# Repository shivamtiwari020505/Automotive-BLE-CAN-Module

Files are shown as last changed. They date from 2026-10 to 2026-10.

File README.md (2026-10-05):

# Automotive BLE-CAN Module

A four-layer hardware design that connects a vehicle CAN bus to a Bluetooth Low Energy (BLE) interface. The module accepts a 9–36 V vehicle supply and has a separate input for a protected, externally charged 1-cell backup battery. During backup operation, the BLE section remains powered while CAN is unavailable.

This repository is a design snapshot for review and prototyping. It has not been fabricated or electrically tested, and the open items below must be resolved before a fabrication release.

## Design at a glance

| Item | Design |
| --- | --- |
| Vehicle input | 9–36 V |
| CAN interface | CAN FD controller and transceiver, connected to the MCU over SPI |
| Wireless interface | Bluetooth Low Energy, with a U.FL antenna connection |
| Backup input | Protected 1-cell Li-ion pack, charged externally |
| PCB | 49.5 × 56.9 mm, four layers, single-sided component assembly |
| Design tool | KiCad 10.0.6 or later |

## Open the project

1. Open [`hardware/BLE-CAN-module.kicad_pro`](hardware/BLE-CAN-module.kicad_pro) in KiCad 10.0.6 or later.
2. Keep the entire `hardware/` directory together. Its symbol tables, footprint tables, local libraries, and 3D models use project-relative paths.
3. For a quick review without KiCad, see the [schematic PDF](documentation/schematic/BLE-CAN-module-schematic.pdf), [PCB views](documentation/pcb/), and [architecture diagram](documentation/architecture/Architecture.svg).

## Repository layout

| Path | Contents |
| --- | --- |
| [`hardware/`](hardware/) | Editable KiCad schematic and PCB, project-local libraries and 3D models |
| [`hardware/Manufacturing_Output_Files/`](hardware/Manufacturing_Output_Files/) | Gerbers, drill files, placement data, BOM, and fabrication notes |
| [`documentation/architecture/`](documentation/architecture/) | System architecture and block diagram |
| [`documentation/schematic/`](documentation/schematic/) | Schematic PDF |
| [`documentation/pcb/`](documentation/pcb/) | PCB layer plot and 3D views |
| [`documentation/dfmea/`](documentation/dfmea/) | Risk register and review report |

## Design status

The project includes routed PCB files and a manufacturing output package, but these are review artifacts. The [architecture notes](documentation/architecture/ARCHITECTURE.md), [BOM notes](hardware/Manufacturing_Output_Files/BOM/BOM_NOTES.md), and [DFMEA report](documentation/dfmea/DFMEA_REPORT.md) record the remaining assumptions and validation work.

Before fabrication, the main open items are:

- Verify the CAN common-mode choke land pattern and terminal numbering.
- Select the CAN crystal and choose part numbers for the remaining BOM entries.
- Resolve the CAN controller's `nWKRQ` power-domain interface in hardware.
- Confirm the required conformal-coating process for the input-section clearances.

Electrical operation, vehicle transients, thermal behavior, RF performance, and EMC still require prototype testing. Do not treat the included manufacturing files as a production release.

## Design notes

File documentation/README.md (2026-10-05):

# Documentation

| Project file | Location | Contents |
| --- | --- | --- |
| Architecture description | `architecture/ARCHITECTURE.md` | System design and assumptions (Rev C) |
| Architecture diagram | `architecture/Architecture.png`, `.svg` | Power, CAN, and BLE block diagram |
| Schematic PDF | `schematic/BLE-CAN-module-schematic.pdf` | Five schematic sheets |
| PCB plots and 3D renders | `pcb/` | Board layer plots and 3D views |
| BOM | `../hardware/Manufacturing_Output_Files/BOM/BOM.csv` | 54 line items, cross-checked against the netlist |
| BOM notes | `../hardware/Manufacturing_Output_Files/BOM/BOM_NOTES.md` | Part qualification and open assumptions |
| DFMEA | `dfmea/DFMEA_REPORT.md`, `dfmea/DFMEA_REGISTER.csv` | 38-item module risk review (Rev 1.0) |
| Fabrication notes | `../hardware/Manufacturing_Output_Files/FAB_NOTES.md` | Stackup and assembly requirements |
| Manufacturing outputs | `../hardware/Manufacturing_Output_Files/` | Gerbers, drills, and placement data |

`datasheets/` holds the device datasheets used during design. `references/` holds
the TI reference material the design draws on — the LP-EM-CC2340R53 LaunchPad
schematic (RF matching values) and the TCAN4550 EVM (common-mode choke and bus
protection). Notes on the CC2340R5 library import are in
`../hardware/libraries/README.md`.

## Known gaps

These are design gaps, not documentation gaps — each is tracked in the DFMEA
register with a closure action.

- **Blocks fabrication:** L301's land pattern is unverified against the TDK
  ACT45B drawing (CAN-007); X301 has no manufacturer part number (MFG-001);
  eight further BOM line items have no MPN (MFG-002 / `../hardware/Manufacturing_Output_Files/BOM/BOM_NOTES.md` OA-3).
- **Blocks production schematic release:** the TCAN4550 nWKRQ power-domain
  conflict needs a hardware isolating buffer (CAN-001).
- **Blocks production build:** conformal coating must be contractually
  confirmed — the 9–36 V input spacing is only compliant under IPC-2221 row B4
  (PWR-005, `../hardware/Manufacturing_Output_Files/FAB_NOTES.md`).
- **Needs hardware before it can close:** all three oscillators run on assumed
  stray capacitance (CAN-002, RF-003, RF-004), and the RF match sits 6.3 mm from
  the ANT pin without re-tuning (RF-001).

36 of 38 DFMEA items are open. See `dfmea/DFMEA_REPORT.md` section 5 for the
twelve stated assumptions where a requirement, datasheet detail or layout rule
could not be closed.

## Tooling

The project is in **KiCad 10** file format (schematic `20260306`, PCB `20260206`)
and requires **KiCad 10.0.6 or later**. It will not open in KiCad 9 — KiCad file
formats are forward-compatible only.

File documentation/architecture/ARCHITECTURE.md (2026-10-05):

# Automotive BLE-CAN Module Architecture

**Revision C | 2026-09-30**

This document describes the current KiCad design in `hardware/BLE-CAN-module.kicad_sch`. It covers the vehicle input and battery backup power paths, CC2340R53 BLE controller, TCAN4550 CAN interface, and their external connections. It is a design description, not a vehicle-transient qualification report.

## System overview

The module accepts a nominal 9-36 V vehicle supply and a separately charged 1-cell Li-ion battery. The protected vehicle input is converted to `+6V5_CAN` for the CAN transceiver and regulated to `+3V3_VEH`. The battery branch produces a protected battery node and a low-quiescent-current 3.0 V rail.

U403/U404 (LM66100-Q1) implement the dual ideal-diode ORing topology of the LM66100-Q1 datasheet, section 9.2.1: each device's CE pin is cross-coupled to the opposite source (`U403 CE` = `+3V3_VEH`, `U404 CE` = `+3V0_BAT`), so the comparators select the higher rail with make-before-break behavior and block reverse current in both directions without any control logic. Because the vehicle rail is regulated to 3.3 V and the battery rail to 3.0 V, source priority is deterministic by construction: the vehicle path conducts whenever vehicle power is present, and the battery path takes over automatically when `+3V3_VEH` decays to about 80 mV below `+3V0_BAT`. The 0.3 V offset also avoids the datasheet-documented corner in which two equal input rails leave both ORing devices off. This is an analog priority scheme; there is deliberately no firmware in the changeover path.

The CC2340R53 runs the BLE application and communicates with the TCAN4550 over SPI. The CAN transceiver is powered from `+6V5_CAN` and uses `+3V3_SYS` for its digital I/O. Consequently, battery backup can keep the MCU domain alive while the vehicle-only CAN transceiver is unpowered; CAN communication is then unavailable.

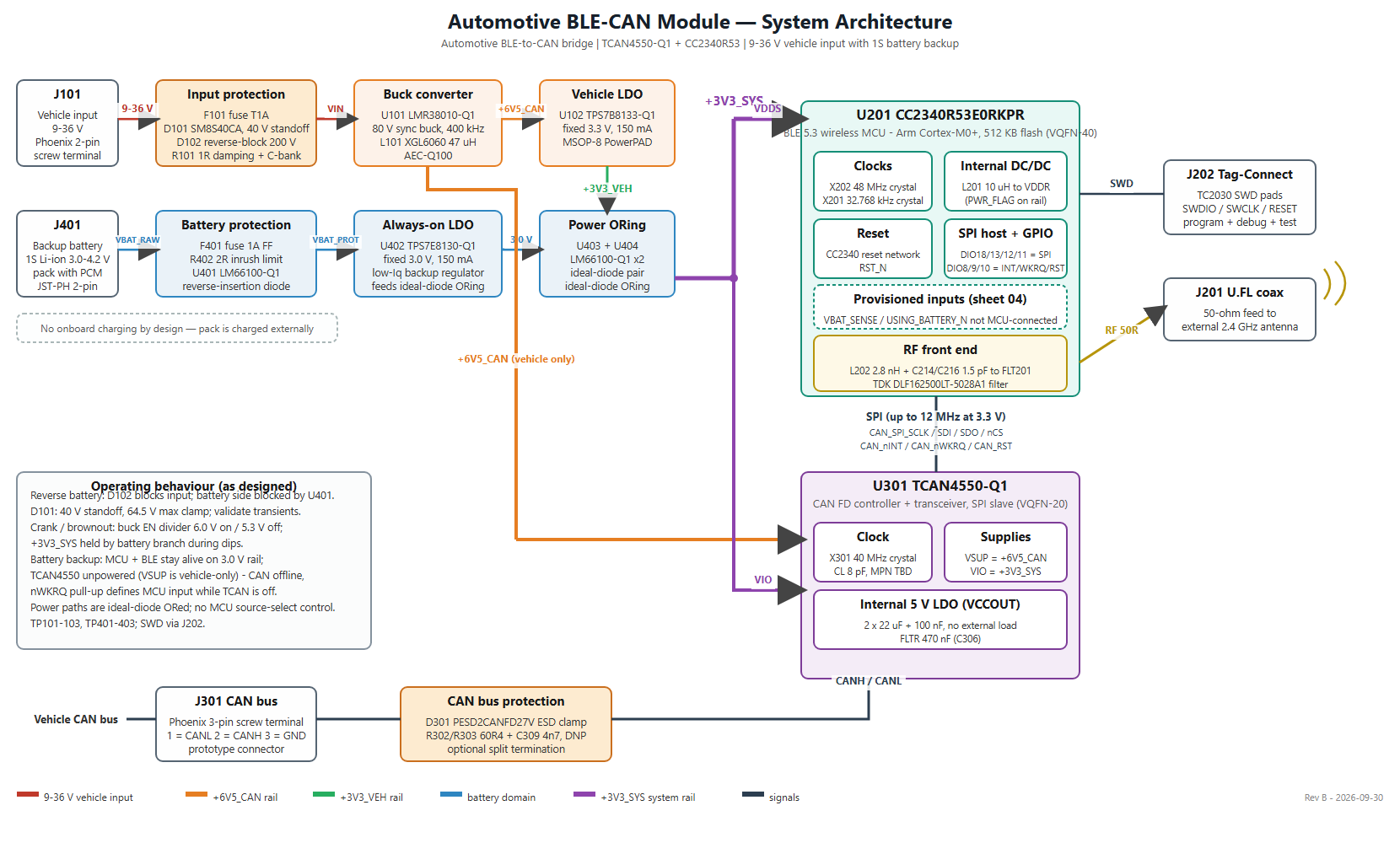
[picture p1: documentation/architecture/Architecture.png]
Automotive BLE-CAN module system architecture


## Power input and backup

### Vehicle input

J101 is the 2-pin 9-36 V input. F101 (T1A) and the input-protection network, including D101 (Vishay SM8S40CA TVS) and D102 (PNE20010ER-Q reverse-polarity protection), protect the downstream converter. R101 (1 ohm) and the input capacitor bank provide damping/filtering. U101 (LMR38010-Q1) with L101 (47 uH) generates `+6V5_CAN`; U102 (TPS7B8133-Q1) regulates that rail to `+3V3_VEH`. D101's 40 V rating is its reverse standoff voltage, not its clamp voltage; its specified maximum clamping voltage is 64.5 V at the rated pulse current. This alone does not establish compliance with a vehicle load-dump or other transient profile.

The 6.5 V intermediate rail is chosen against the TCAN4550 supply window: VSUP recommended operating range is 6-24 V with UVSUP thresholds of 5.5-5.9 V rising and 4.5-4.7 V falling, so 6.5 V provides headroom above UVSUP while minimizing dissipation in the transceiver's internal 5 V LDO and in U102.

### Battery backup

J401 accepts a protected 1-cell Li-ion pack (3.0-4.2 V); the pack is charged externally and no charger is present on this board. F401, R402, and U401 (LM66100-Q1) provide battery-branch protection; U401 uses the datasheet's always-on reverse-current-blocking configuration (CE tied to VOUT through R401), so the pack is isolated from any downstream fault that could otherwise back-drive it. U402 (TPS7E8130-Q1) produces `+3V0_BAT`. U403 and U404 combine `+3V0_BAT` and `+3V3_VEH` onto `+3V3_SYS` as described in the system overview.

`USING_BATTERY_N` and the `VBAT_SENSE` divider are present on the backup-power schematic but are not connected to CC2340 GPIO/ADC pins. They are provisioned, not MCU-readable in the current design. The CAN transceiver supply remains on the vehicle-derived `+6V5_CAN` rail.

## Vehicle transients, crank, and brownout

Behavior over the input range, using LMR38010-Q1 datasheet thresholds (EN rising 1.25 V typ / 1.4 V max; EN falling 1.10 V typ / 0.95 V min) and the R102/R103 divider (383 k / 100 k, ratio 4.83):

- **Normal operation, 9-36 V.** All rails regulated; buck output current is far below the 1 A rating (see power budget).
- **Jump start / 24 V system.** 36 V steady-state is within the converter's 80 V recommended operating range with large margin.
- **Load dump / transients.** D101 clamps at up to 64.5 V; the converter's 80 V operating / 85 V absolute-maximum input tolerates the clamped waveform. Formal ISO 16750-2 / ISO 7637-2 pulse testing has not been performed; see assumptions.
- **Crank.** The converter is enabled above approximately 6.0 V (worst-case 6.8 V) and remains enabled down to approximately 5.3 V typical. Below about 8 V input the buck is in dropout and `+6V5_CAN` follows the input minus the dropout voltage. CAN remains operational until VSUP crosses the TCAN4550 UVSUP falling threshold (4.5-4.7 V); the MCU's 3.3 V LDO stays in regulation essentially as long as the buck runs. Through a moderate crank dip (input ≥ ~6 V) the whole module therefore stays up.
- **Severe brownout (< ~5.3 V) or supply loss.** The buck disables via EN, the vehicle rails collapse, and U403/U404 switch `+3V3_SYS` to the battery rail with make-before-break continuity. The MCU domain (BLE) rides through; the CAN transceiver enters its protected/unpowered state and recovers automatically when VSUP rises back above UVSUP rising (5.5-5.9 V) - the TCAN4550 M_CAN core must then be reconfigured by firmware.
- **Reverse battery.** D102 blocks reverse current; D101 is bidirectional and clamps; F101 provides the series fault break.

## Power budget and thermal estimates

Estimated worst-case active budget (values from device datasheets; not yet validated on hardware):

| Rail | Loads | Estimated worst case |
| --- | --- | --- |
| `+6V5_CAN` | TCAN4550 VSUP (transceiver dominant, internal 5 V LDO, up to 70 mA VCCOUT budget), U102 input | ~90 mA |
| `+3V3_VEH` / `+3V3_SYS` | CC2340R53 (radio active, internal DC/DC), TCAN4550 VIO (≤3 mA with crystal), pull-ups | ~15-20 mA |
| Buck output total | | ~110 mA of 1 A rating |
| Input current at 9 V | ~0.72 W out, ~90 % PFM efficiency | ~90 mA |

Dissipation estimates at worst case, 85 °C ambient:

- **U301 TCAN4550**: dominant-state dissipation ≈ 0.45 W; at RθJA 35.2 °C/W (improved by the exposed-pad via array into the ground planes) junction rise ≈ 16 °C, Tj ≈ 101 °C against a 125 °C operating / 160 °C shutdown limit. This is the hottest device on the board.
- **U101 buck**: ~70 mW loss at full module load - negligible; DDA PowerPAD into the plane stack.
- **U102 LDO**: (6.5 V - 3.3 V) × 20 mA ≈ 64 mW - negligible.

No heatsinking or airflow is assumed; copper pours and the via arrays under U101/U102/U201/U301 are the only thermal paths.

## Standby (parked) current estimate

With the vehicle present, CAN in sleep, and BLE idle/advertising slowly, the estimated draw from the vehicle battery is on the order of **100-150 µA at 12 V**, dominated by:

- R102/R103 EN divider: 483 kΩ across the input ≈ 25 µA at 12 V (50 µA at 24 V) - the largest single fixed load; accepted to keep the enable threshold purely resistive.
- LMR38010-Q1 non-switching quiescent: 40 µA (PFM variant selected specifically for this figure).
- TCAN4550 sleep (VSUP tens of µA, VIO 9 µA) plus TPS7B81-Q1 (2.7 µA) and MCU standby (~1-2 µA).

On the battery branch, the continuous drain is the TPS7E81-Q1 quiescent (2.8 µA), the ideal-diode devices, and the 2 MΩ `VBAT_SENSE` divider (~2 µA) - roughly 6-8 µA before BLE activity, i.e. about 17 mAh/year from the divider alone. As a labeled example, a 500 mAh protected pack supporting an average 50 µA backup profile gives an order-of-magnitude runtime of ~10,000 h. These are datasheet-arithmetic estimates to be confirmed at bring-up.

## BLE controller

U201 is the TI CC2340R53E0RKPR, a 2.4 GHz Bluetooth LE MCU with 512 KB flash. X201 is a 32.768 kHz, 9 pF load crystal (Abracon ABS06-32.768KHZ-9-T). C212 and C213 are 15 pF C0G capacitors (Murata GRM1555C1H150JA01D). These are nominal values selected with approximately 1.5 pF of assumed parasitic capacitance; validate crystal load and startup margin on the assembled layout.

X202 is a 48 MHz, 7 pF load crystal (Abracon ABM11W-48.0000MHZ-7-D1X-T3). C210 and C211 are DNP; the MCU's configurable internal load-capacitance array is used, and its setting should be checked against the assembled board's parasitics. L201 is the MCU internal DC/DC inductor.

The RF network uses L202 (2.8 nH), C214/C216 (1.5 pF), and TDK DLF162500LT-5028A1 (FLT201), a 2.4 GHz band-pass filter. J201 is the U.FL antenna connection; use a 50 ohm feed and a suitable 2.4 GHz antenna. FLT201 is a filter, not a balun. The RF path is a 50 ohm microstrip on F.Cu referenced to the In1.Cu ground plane; the controlled-impedance requirement is stated in `hardware/Manufacturing_Output_Files/FAB_NOTES.md`.

J202 is the Tag-Connect TC2030 programming/debug footprint. The CC2340 SPI clock should be limited to the MCU-supported rate for the selected supply and operating conditions; at 3.3 V, use no more than 12 MHz and observe both devices' timing requirements.

## CAN interface

U301 is the TI TCAN4550-Q1 CAN FD controller/transceiver. It receives `+6V5_CAN` at VSUP, `+3V3_SYS` at VIO, and communicates with U201 over SPI. X301 is a 40 MHz crystal specified at 8 pF load capacitance; the schematic does not specify its manufacturer part number.

C305 and C310 are 22 uF VCCOUT capacitors; C307 is 100 nF. C306 is the 470 nF FLTR capacitor.

**Common-mode choke.** L301 (TDK ACT45B-101-2P-TL003, 100 µH, AEC-Q200) sits directly at the transceiver CANH/CANL pins, matching the choke position on TI's TCAN4550EVM and the datasheet section 11.1 guidance. The transceiver-side nets are `CAN_P`/`CAN_N`; the bus side of the choke - TVS, termination, and connector - is `CAN_BUS_P`/`CAN_BUS_N`. Both pairs use the `_P`/`_N` suffix convention so KiCad treats them as differential pairs. On the PCB the chain is placed inline in signal order — U301 → L301 → D301 → J301 — with the TVS adjacent to the connector per the datasheet layout guideline; J301 was shifted 0.7 mm toward the board edge to fit the choke without courtyard conflicts. The DNP split-termination cluster sits directly below the bus pair; its CANH tap uses a short B.Cu link (two vias) to cross the pair, which is acceptable for an unpopulated termination stub.

D301 (PESD2CANFD27V) protects the CAN bus. J301 is the 3-pin bus connector with the schematic pinout:

| J301 pin | Signal |
| --- | --- |
| 1 | CANL |
| 2 | CANH |
| 3 | GND |

R302 and R303 (60.4 ohm each) and C309 (4.7 nF) are DNP split-termination options. Populate termination only when the module is an end node and the network topology calls for it; do not populate it on an intermediate bus node.

## SPI, interrupt and reset wiring between CC2340R53 and TCAN4550

All seven control signals run directly between the two devices with no level
translation. The complete interface:

| Net | CC2340R53 (U201) | TCAN4550 (U301) | Bias | Purpose of the bias |
| --- | --- | --- | --- | --- |
| `CAN_SPI_SCLK` | pin 13, DIO18 | pin 4, SCLK | R308 100 k to GND | Defined level when the MCU tri-states in backup; matches SPI mode 0 idle |
| `CAN_SPI_SDI` | pin 7, DIO13 | pin 5, SDI | R309 100 k to GND | As above; TCAN input never floats |
| `CAN_SPI_SDO` | pin 6, DIO12 | pin 6, SDO | R310 100 k to GND | TCAN SDO is Hi-Z whenever nCS is high, so this defines the MCU input |
| `CAN_SPI_nCS` | pin 5, DIO11 | pin 7, nCS | R301 10 k to `+3V3_SYS` | Keeps the TCAN deselected while the MCU is in reset or tri-stated |
| `CAN_nINT` | pin 2, DIO8 | pin 8, nINT | R306 10 k to `+3V3_SYS` | Open-drain output; datasheet requires a 2–10 kΩ pull-up to VIO |
| `CAN_nWKRQ` | pin 3, DIO9 | pin 2, nWKRQ | R307 100 k to `+3V3_SYS` | See the voltage-domain note below — this one is **not** safe as drawn |
| `CAN_RST` | pin 4, DIO10 | pin 19, RST | R305 10 k to GND | RST is **active HIGH**; the pull-down keeps the device out of reset while the MCU is tri-stated |

### Voltage-domain assumptions

**No level shifting is required, and this is deliberate.** The TCAN4550 VIO pin
exists precisely so the SPI and GPIO block can be operated in the host's
I/O domain. Both sides of this interface sit on the same rail:

- CC2340R53 `VDDS` (pins 8, 17, 31, 38) → `+3V3_SYS`
- TCAN4550 `VIO` (pin 17) → `+3V3_SYS`

Because both devices track the same node, the logic thresholds move together and
there is no translation, no series resistor network and no added propagation
delay. SPI clock is limited to 12 MHz — the CC2340R53 constraint at 3.3 V, which
is below the TCAN4550's 18 MHz capability, so the MCU is the limiting device.

Two consequences follow from this choice, both tracked in the DFMEA:

1. **`nWKRQ` is the exception, and it is a real defect.** Before firmware writes
   register `0x0800` bit 19, nWKRQ drives from an internal **3.6 V** source — not
   from VIO. It is therefore the one pin in this interface that does *not*
   respect the shared domain. When the CAN device is powered while the MCU rail
   is low or absent, current can be injected into an MCU pin, and R307's 100 kΩ
   pull-up does not isolate a push-pull driver. Firmware configuration cannot
   protect the interval between power-up and that write. A buffer with a 5.5 V
   tolerant input and `Ioff` / partial-power-down protection is required — see
   **DFMEA CAN-001**, which blocks production schematic release.
2. **In battery backup, the shared rail sits at ~3.0 V**, below the TCAN4550's
   3.135 V recommended VIO minimum, though well above its 2.45–2.6 V UVIO
   threshold. The device does not fault; it simply operates outside its
   recommended window. This is accepted because CAN is defined as unavailable in
   backup and VSUP is absent anyway. The alternative — powering VIO from the
   vehicle rail only — was rejected because it would create a powered-MCU /
   unpowered-VIO partial-power-down condition on the SPI pins, which is the same
   mechanism as item 1. See **DFMEA CAN-006**.

The pull-down bias on SCLK/SDI/SDO is not decorative: backup mode is a state the
system enters by design, and without these resistors the TCAN4550 inputs would
float in a powered device.

## RF keepout, ground strategy and enclosure assumptions

**Keepout.** The RF chain runs as a straight line on F.Cu from the U201 ANT pad
through C214 / L202 / C216 and FLT201 to J201, with no vias and no layer changes.
In1.Cu beneath it is an uninterrupted ground plane — the microstrip reference is
continuous over the whole path. A local all-layer keepout is defined under the
U.FL body so no copper or via intrudes into the connector launch. Board-wide
ground stitching (505 vias) flanks the RF corner.

**Ground strategy.** In1.Cu is a solid, unbroken ground plane and is never used
for signal routing. B.Cu is a stitched ground pour. The RF section, the switching
regulator and the CAN section therefore share one reference with no split planes
and no moats — deliberately, since split-plane returns are a more common source
of trouble than they are a cure. U201's RFGND (pin 40) and exposed pad tie
straight into that plane through the device's via array.

**Enclosure assumptions** *(summary; no mechanical
design was undertaken)*:

- The antenna is **off-board**, on a U.FL pigtail. The board makes no assumption
  about antenna type or position beyond providing a 50 Ω port, so the enclosure
  can place it where the installation allows rather than the PCB dictating it.
- The enclosure is assumed **non-metallic in the vicinity of the antenna**, or
  the antenna is assumed to be mounted external to it. No detuning allowance has
  been made, and antenna performance is therefore outside what this board can
  guarantee (**DFMEA RF-005**).
- **Mounting and grounding:** four M2 holes (H1–H4) at the board corners have
  plated, ground-connected pads. If the enclosure is metallic and the standoffs
  are conductive, the board ground bonds to chassis at four points. That is the
  intended arrangement; if chassis bonding is *not* wanted, non-conductive
  standoffs must be specified.
- **Connectors** J101, J301 and J401 are all on board edges with horizontal entry,
  so a simple enclosure with edge cut-outs suffices. J201 (U.FL) is vertical and
  needs headroom for the mating pigtail.
- The board is assumed to be **conformally coated** (see assumptions section) —
  the enclosure is not relied upon for environmental sealing of the PCB.

## PCB stackup rationale

The board is a 1.58 mm 4-layer stackup: **F.Cu (signal) / In1.Cu (solid GND) / In2.Cu (power) / B.Cu (GND pour)**, with 0.11 mm 2116 prepreg between the outer layers and their adjacent planes.

- The thin prepreg to a continuous In1.Cu ground gives the 2.4 GHz microstrip a tight, unbroken reference and keeps the buck converter's hot-loop return inductance low.
- In2.Cu carries the `+3V3_SYS` and `+6V5_CAN` distribution planes, each sandwiched against ground.
- B.Cu is a stitched ground pour providing a low-impedance return and thermal spreading; dense via stitching ties all ground layers together, including arrays under the exposed pads of U101, U102, U201, and U301 and around the connectors and mounting holes.
- All components mount on the top side for single-pass assembly; three fiducials and six labeled test points support manufacturing and bring-up.

## Assumptions and trade-offs

1. **Input-section creepage/clearance - conformal coating assumed.** The 9-36 V input nets are routed at the project-default 0.2 mm clearance (minimum measured 0.20 mm). This assumes the assembled board receives a **permanent polymer conformal coating**, placing it under IPC-2221 Table 6-1 row **B4** (external conductors, coated, 31-50 V → 0.13 mm) rather than row B2 (uncoated → 0.6 mm). Coating is therefore a manufacturing requirement, not an option; it is called out in `hardware/Manufacturing_Output_Files/FAB_NOTES.md` together with the masking list. Where coating is masked - at J101 - the governing limit is the connector system's own rated insulation voltage at its 2.54 mm pitch, not the bare-board spacing table. *Trade-off:* tighter spacing kept the input section compact on a 49.5 × 56.9 mm board; the cost is a mandatory coating step and a repair/rework constraint. *Not closed:* spacing has not been assessed against the SM8S40CA's 64.5 V clamping voltage, only against the 36 V steady-state maximum.

2. **MCU part number.** An early project requirement named CC2340R40, which is not a valid part number. The design uses the **CC2340R5** family and selects **CC2340R53E0RKPR** (512 KB flash, QFN-40 RKP) as its orderable device. This selection does not imply automotive qualification.

3. **Automotive qualification is mixed.** All power-path and CAN ICs are AEC-Q100/Q101 qualified (-Q1 variants). The BLE MCU, CC2340R53E0RKPR, is **not AEC-Q100 qualified**; no automotive-qualified CC2340 orderable exists in this design's library. The module is therefore assumed to be a **cabin-mounted, non-safety telematics device** with an operating ambient bounded by the MCU's commercial rating rather than by the Q1 parts around it. Several electromechanical parts are likewise prototype/bench grade and would change for a production automotive build: the Phoenix MPT terminal blocks (J101, J301) and JST-PH battery connector (J401) have no vibration or sealing rating and would move to a sealed automotive connector system; C101 (Panasonic FK, 105 °C / 2000 h electrolytic) is a wear-out item on the always-on input and would move to an automotive-grade hybrid-polymer or ceramic-only bank; the AEC-Q200 status of the selected Abracon crystal orderables must be verified or Q200 equivalents substituted.

4. **TCAN4550 VIO below recommended minimum in battery backup.** In backup, `+3V3_SYS` equals the 3.0 V battery rail, below the TCAN4550 VIO recommended minimum of 3.135 V but well above the UVIO thresholds (2.45-2.6 V rising), so the device does not fault - it is simply outside recommended operating conditions on a powered pin. This is accepted because CAN is defined as unavailable in backup mode and VSUP is absent anyway. The alternative - powering VIO from the vehicle rail only - was rejected because it would create a powered-MCU/unpowered-VIO partial-power-down condition on the SPI pins (compare DFMEA item CAN-001).

5. **CAN choke land pattern.** L301 is placed and routed on the PCB (DRC and schematic parity clean). Its footprint is a generic 4532 common-mode-choke land pattern; verify it against the TDK ACT45B manufacturer drawing, including terminal numbering, before fabrication release.

## Test and design notes

Power test points are TP101 (`+6V5_CAN`), TP102 (`+3V3_VEH`), TP103 (GND), TP401 (`VBAT_PROTECTED`), TP402 (`+3V3_SYS`), and TP403 (GND). No TP404 or TP405 is present in the current schematic. J202 provides programming/debug access.

The SM8S40CA's 40 V standoff rating is below the maximum 36 V nominal input range only with limited margin for tolerance and transient behavior. Confirm the selected protection scheme against the intended vehicle electrical/transient requirements, connector polarity, fuse coordination, and downstream absolute-maximum ratings before production use. Component ratings in this document do not constitute automotive qualification.

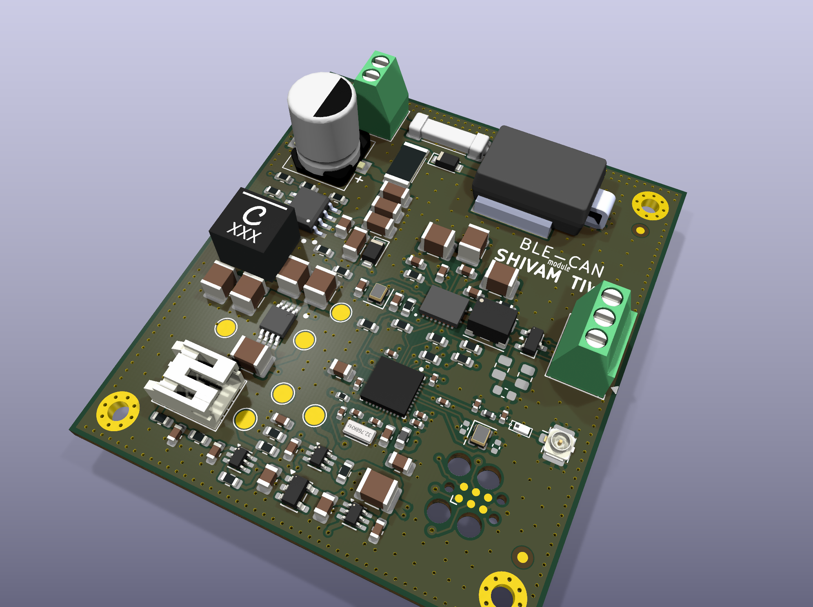
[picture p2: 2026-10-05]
documentation/pcb/pcb-3d-isometric.png

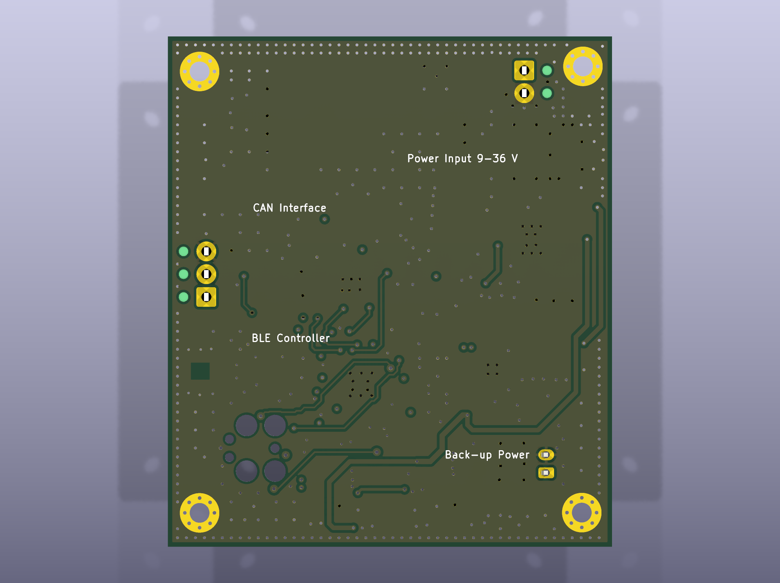
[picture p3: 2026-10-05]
documentation/pcb/pcb-3d-bottom.png

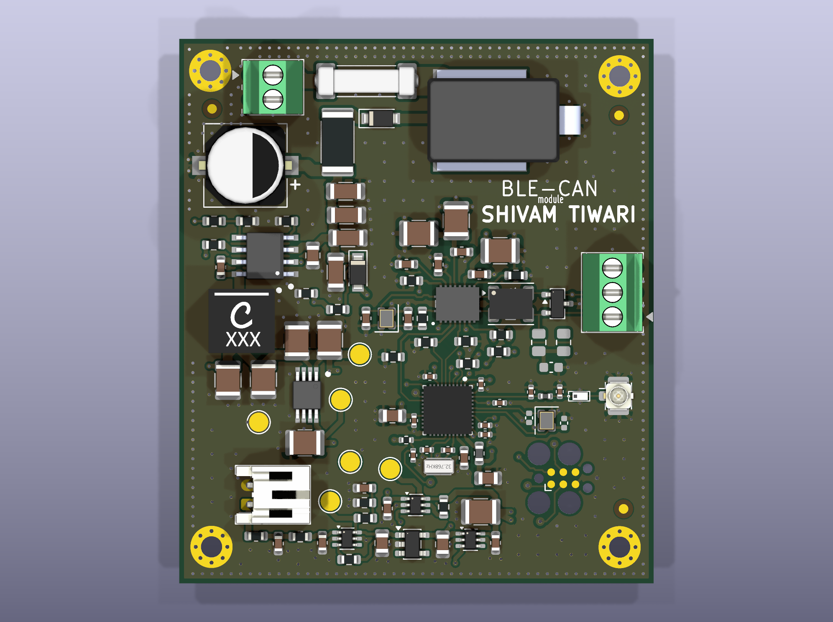
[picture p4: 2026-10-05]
documentation/pcb/pcb-3d-top.png

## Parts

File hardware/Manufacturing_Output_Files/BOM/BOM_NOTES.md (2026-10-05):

# Bill of Materials — Notes, Qualification Status and Unresolved Assumptions

**Project:** Automotive BLE-CAN Module
**Designer:** Shivam Tiwari
**Design period:** 2026-09-24 to 2026-09-30 | Rev A
**Source of truth:** `hardware/BLE-CAN-module.kicad_sch` (KiCad 10.0.6)
**Machine-readable BOM:** `BOM.csv` in this folder

This document carries the qualification notes, alternatives rationale and open
assumptions for this project. `BOM.csv` holds the same information
per line item; this file groups it so it can be reviewed as a whole.

## 1. Summary

| Metric | Count |
| --- | --- |
| BOM line items | 54 |
| Distinct components on the board | 96 |
| Fitted components | 91 |
| DNP components | 5 (C210, C211, C309, R302, R303) |
| Line items with a committed MPN | 46 of 54 |
| **Line items with NO manufacturer part selected** | **8** |
| Footprint-only items (no part fitted) | 14 |

`BOM.csv` has been cross-checked programmatically against the KiCad netlist
export: all 96 board references are covered exactly once, every `Qty` matches its
reference list, and the DNP set agrees with the schematic.

Footprint-only items, correctly excluded from the BOM but present on the board:
H1–H4 (M2 mounting holes, grounded), FM1–FM3 (fiducials), J202 (Tag-Connect
TC2030 programming footprint — no connector is fitted, the probe is a tool), and
TP101/102/103/401/402/403 (test pads).

## 2. Automotive qualification status

The power path and CAN devices are automotive-qualified. The wireless subsystem
and all electromechanical parts are not. This is a deliberate, documented
trade-off — see `documentation/architecture/ARCHITECTURE.md`, assumptions
section 2.

### Qualified

| Class | Parts | Standard |
| --- | --- | --- |
| Power / interface ICs | LMR38010-Q1, TPS7B81-Q1, TPS7E81-Q1, LM66100-Q1 (×3), TCAN4550-Q1 | AEC-Q100 Grade 1 |
| Discretes | SM8S40CA, PNE20010ER-Q, PMEG10010ELR-Q, PESD2CANFD27V | AEC-Q101 |
| Passives | TDK CGA series MLCC (all), Vishay CRCW-e3 resistors (all), Coilcraft XGL6060, Vishay MFU fuse | AEC-Q200 |

### Not qualified, or unverified

| Part | Status | Consequence and intent |
| --- | --- | --- |
| **CC2340R53E0RKPR** (U201) | **Not AEC-Q100** | No automotive-qualified CC2340 orderable exists. This part, not the Q1 devices around it, bounds the module's environmental rating. Assumed cabin-mount, non-safety telematics use. |
| **C101** Panasonic EEEFK2A220P | **AEC-Q200 claim unverified** | The schematic note claims AEC-Q200; this was not confirmed against the Panasonic datasheet. Regardless of qualification, FK is a 105 °C / 2000 h series — roughly one year of continuous operation at high ambient on an always-on rail. This is the board's dominant wear-out item. |
| **F101** Schurter UMT 250 | Not AEC-Q200 | Industrial fuse. Needs an automotive-qualified equivalent or a documented procurement agreement. |
| **C212, C213** Murata GRM | Not automotive (GRM is the commercial series) | Direct automotive equivalent exists: **GCM1555C1H150JA16**. Recommended swap for production — same size, same value. |
| **X201, X202** Abracon | Commercial, +85 °C max | Rated below the +125 °C of the surrounding automotive ICs. Automotive equivalents identified in `BOM.csv`. |
| **FLT201** TDK DLF162500LT | Commercial | No automotive grade identified for this filter. |
| **J101, J301** Phoenix MPT | Not automotive | Industrial screw terminals — no vibration, sealing or keying rating. Bench/prototype connectors. |
| **J401** JST PH | Not automotive | No locking retention for vibration. |
| **J201** Hirose U.FL | Commercial | ~30 mating cycles, no vibration lock. Acceptable for an internal pigtail, not a serviceable interface. |
| **L301** TDK ACT45B | AEC-Q200 believed, **unverified** | See open item OA-2 below. |

## 3. Unresolved assumptions — ranked

These are the honest gaps. None are hidden in the CSV; each appears against its
line item as well.

**OA-1 — X301 (40 MHz CAN crystal) has no manufacturer part selected.**
The single most significant BOM gap. Frequency tolerance directly drives CAN FD
bit timing, and the crystal's motional parameters determine the final C303/C304
and R311 values. This blocks closure of DFMEA item CAN-002. Candidate parts are
listed in `BOM.csv`; none has been committed.

**OA-2 — L301 footprint is a generic land pattern, not the manufacturer's.**
The choke is assigned `L_CommonModeChoke_Coilank_ACM4532`, a generic 4.5 × 3.2 mm
pattern, while the specified part is a TDK ACT45B. Both the pad geometry **and
the terminal numbering** must be checked against the TDK drawing before
fabrication. The schematic symbol variant (`_1423`) was chosen so windings pair
1–4 and 2–3 to match the assigned footprint; if the ACT45B numbers its windings
differently, the symbol variant must be swapped. This is recorded in the
component's `Purpose` field in the schematic.

**OA-3 — Eight line items have no manufacturer part number.**
All are in the MCU/RF section: L201, L202, C201–C204/C206/C207/C215, C205/C208,
C209, C214/C216, R201, plus X301 (OA-1) and the J201 MPN field. Two matter
electrically rather than commercially:
- **L202 (2.8 nH)** and **C214/C216 (1.5 pF)** are RF matching components. The
  values come from TI's LP-EM-CC2340R53 reference design, but a general-purpose
  part will degrade the match — high-Q RF-grade parts with tight tolerance are
  required.
- **L201 (10 µH)** feeds the CC2340R5 internal DC/DC and must meet TI's
  saturation-current and DCR requirement.

**OA-4 — The RF matching network has not been re-tuned for this board.**
L202/C214/C216 are the TI reference values, but on the LaunchPad those parts sit
immediately at the ANT pin. Here the first matching element is **6.3 mm** from
the pin — about 33° of electrical length at 2.44 GHz — and the network feeds a
TDK low-pass filter into a U.FL connector rather than the reference's tuning pi.
The values are a starting point, not a verified match. VNA verification on an
assembled board is required.

**OA-5 — MLCC derating is assumed from datasheet curves, not measured.**
Several capacitances have datasheet minimums that must survive DC bias,
temperature and aging: TCAN4550 VCCOUT (≥10 µF effective at 5 V, from
C305 + C310 = 44 µF nominal), FLTR (≥300 nF from 470 nF nominal), U402 output
(≥2.2 µF), and the buck output bank (≥20 µF effective at 6.49 V). All are
believed to have margin; none has been bench-verified.

**OA-6 — Crystal load capacitors are provisional.**
C212/C213 (15 pF) assume ~1.5 pF board stray for CL = 9 pF. C303/C304 (10 pF)
assume ~3 pF stray for CL = 8 pF. C210/C211 are DNP because the CC2340R5 internal
cap array is used — but the X48P/X48N traces are long and asymmetric (11.1 mm vs
7.6 mm), so the added stray may prevent the array reaching the 7 pF CL. R311 is
0 Ω for first assembly only. All of these are set on the prototype, per TI SLLA549.

**OA-7 — CAN bus termination topology is an assumption.**
R302/R303/C309 are DNP because the module is assumed to be a **stub node**. If it
is deployed as a bus end node, all three must be fitted together (120.8 Ω). No
network topology requirement was supplied.

**OA-8 — Transient protection is not validated against a pulse standard.**
D101's 40 V standoff leaves limited margin over the 36 V maximum input, and its
64.5 V clamp is within the LMR38010-Q1's 80 V operating / 85 V absolute-maximum
rating. No ISO 7637-2 or ISO 16750-2 pulse testing has been performed, and the
fuse/TVS energy coordination study has not been done.

**OA-9 — VBAT_SENSE is provisioned but not connected.**
R403/R404/C404 form a working divider, but `VBAT_SENSE` and `USING_BATTERY_N`
terminate at unconnected labels — no CC2340 ADC or GPIO is attached, despite 16
free pins. Firmware cannot read battery voltage or determine the active source.

**OA-10 — D102 ratings taken from the schematic note, not the datasheet.**
PNE20010ER-Q is recorded as 200 V / 1 A from the schematic's own annotation.
IF(AV) and the forward drop at the ~90 mA operating current were not
independently confirmed.

## 4. Deliberate design choices visible in the BOM

Worth reading as intent rather than as gaps:

- **U101 is the PFM, spread-spectrum variant** (`LMR38010SQ…`, not `…FSQ…`).
  Chosen for 40 µA non-switching quiescent current — the parked-current budget —
  and for conducted/radiated EMI. The FPWM variant would have been the wrong call.
- **U402 is 3.0 V, not 3.3 V.** The 0.3 V offset below `+3V3_VEH` is what gives
  the LM66100 ORing pair a decisive priority margin and avoids the datasheet's
  documented equal-rails lockout, where both devices switch off.
- **U102 is fed from +6V5_CAN, not VIN.** Dissipation drops to ~64 mW at the
  design load instead of ~0.65 W from a 36 V rail.
- **D101 is bidirectional (CA).** Reverse battery is blocked by the D102 series
  diode rather than clamped, so the fuse does not open on a reverse connection.
- **D301 is 27 V standoff.** Chosen so a CANH/CANL short to a 24 V vehicle rail
  does not put the clamp into conduction.
- **R102/R103 set turn-on near 6.0 V**, below the 9 V specification minimum, to
  ride through crank. The cost is ~25 µA continuous — the largest single fixed
  standby load on the vehicle battery.

## 5. Before fabrication release

1. Select X301 and close OA-1.
2. Verify the L301 land pattern and terminal numbering (OA-2).
3. Assign the eight missing MPNs, with RF-grade parts for L202/C214/C216 (OA-3).
4. Swap C212/C213 to the GCM automotive equivalent.
5. Decide the C101 endurance question — either confirm its qualification and
   accept the 2000 h rating, or move to an automotive hybrid-polymer part.
6. Confirm conformal coating is contracted — the input-section spacing depends
   on it (see `hardware/Manufacturing_Output_Files/FAB_NOTES.md`).

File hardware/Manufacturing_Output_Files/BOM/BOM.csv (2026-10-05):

Item | Qty | References | Description | Value / Key Ratings | MPN | Manufacturer | Package / Footprint | Automotive Qualification | Key Alternatives | Notes and Unresolved Assumptions | Fitted
1 | 1 | C101 | Aluminium electrolytic input bulk | 22 uF +/-20% / 100 V / 105 degC / 2000 h endurance | EEEFK2A220P | Panasonic | SMD can 8 x 10.2 mm (FK case F) | UNVERIFIED - schematic note claims AEC-Q200; not confirmed against Panasonic datasheet | Nichicon UCD2A220MCL1GS; Wurth 865060645004 (both need land-pattern check) | Only wet electrolytic on the board and the dominant wear-out item on an always-on rail. 2000 h at 105 degC is roughly 1 year continuous at high ambient. Damping partner to R101; do not delete without re-checking input-filter damping. | Yes
2 | 4 | C102-C105 | Input ceramic bank X7R | 4.7 uF / 100 V / X7R / 1206 | CGA5L1X7R2A475K160AC | TDK | C_1206_3216Metric | AEC-Q200 (TDK CGA automotive series) | Murata GCM31CR72A475KE02; Kemet C1206C475K1RACAUTO | Bank must retain >=4.7 uF effective after DC bias, temperature and aging. Not measured - derating assumed, not verified. | Yes
3 | 1 | C106 | VIN high-frequency bypass | 100 nF / 100 V / X7R / 0805 | CGA4J2X7R2A104K125AA | TDK | C_0805_2012Metric | AEC-Q200 (TDK CGA) | Murata GCM21BR72A104KA37 | Placed directly across U101 VIN/GND for the smallest hot loop. | Yes
4 | 6 | C107,C302,C307,C308,C404,C408 | General decoupling / filter | 100 nF / 50 V / X7R / 0603 | CGA3E2X7R1H104K080AA | TDK | C_0603_1608Metric | AEC-Q200 (TDK CGA) | Murata GCM188R71H104KA57 | Roles: U101 bootstrap (C107), TCAN4550 VSUP/VIO/VCCOUT bypass (C302/C308/C307), VBAT_SENSE filter (C404), +3V3_SYS bypass (C408). | Yes
5 | 9 | C108-C112,C301,C305,C310,C407 | Bulk ceramic X7R | 22 uF / 25 V / X7R / 1210 | CGA6P3X7R1E226M250AB | TDK | C_1210_3225Metric | AEC-Q200 (TDK CGA) | Murata GCM32ER71E226KE15 | C305+C310 must retain >=10 uF effective at 5 V (TCAN4550 VCCOUT minimum). Buck output bank should hold >=20 uF effective at 6.49 V. Derating assumed from datasheet curves - not bench-verified. | Yes
6 | 1 | D101 | Bidirectional transient suppressor | 40 V standoff, 64.5 V max clamp at 102 A (10/1000 us), 8000 W peak | SM8S40CAHM3_A/I | Vishay | DO-218AC (BLE_CAN:Vishay_DO-218AC_SM8S) | AEC-Q101 | Littelfuse SM8S40CA; Bourns SM8S40CA (same DO-218AC outline) | Bidirectional chosen so reverse battery is blocked by D102 rather than clamped. 40 V standoff leaves limited margin over the 36 V maximum input. NOT validated against an ISO 7637-2 / ISO 16750-2 pulse set. | Yes
7 | 1 | D102 | Series reverse-battery blocking rectifier | 200 V / 1 A (per schematic note - confirm IF(AV) and VF at 90 mA) | PNE20010ER-QX | Nexperia | SOD-123W (Diode_SMD:Nexperia_CFP3_SOD-123W) | AEC-Q101 (Nexperia -Q suffix) | Nexperia PMEG6010CEH; ST STPS1L60A (footprint differs) | Series diode costs ~0.5-0.7 V forward drop. A reverse-blocking P-FET would be more efficient but was not used. Exact VF at load not verified. | Yes
8 | 1 | D103 | Output-to-input discharge Schottky | 100 V / 1 A Schottky | PMEG10010ELR-QX | Nexperia | SOD-123W (Diode_SMD:Nexperia_CFP3_SOD-123W) | AEC-Q101 (Nexperia -Q suffix) | Nexperia PMEG10020ELR-Q | Protects the buck when VIN falls below the stored output voltage. Not a battery power path. | Yes
9 | 1 | F101 | Vehicle input fuse | T1A / 125 VDC slow-blow | 3403.0166.24 | SCHURTER | UMT 250 SMD (Fuse:Fuse_Schurter_UMT250) | NOT AEC-Q200 - industrial part; automotive qualification/procurement agreement required | Littelfuse 0453001.MR (AEC-Q200); Bel Fuse 0ZCJ series | Must coordinate with the harness fuse and the TVS clamp energy. Coordination study not performed. | Yes
10 | 1 | J101 | Vehicle power input connector | 6 A / 160 V, 2.54 mm pitch screw terminal | 1725656 | Phoenix Contact | TerminalBlock_Phoenix_MPT-0.5-2-2.54_1x02_P2.54mm_Horizontal | NOT automotive - industrial terminal block, no vibration or sealing rating | TE AMPSEAL 16 series; Molex MX150 (sealed automotive) | Pin 1 = vehicle positive, pin 2 = vehicle return. Prototype/bench connector; production build requires a sealed, keyed, vibration-rated connector. This connector carries the full 9-36 V input: its 0.34 mm pad-to-pad copper gap is fixed by the 2.54 mm pitch, and the surrounding pour clearance is 0.30 mm - both rely on the mandatory conformal coating (IPC-2221 row B4). See hardware/Manufacturing_Output_Files/FAB_NOTES.md. | Yes
11 | 1 | L101 | Buck power inductor | 47 uH / 107 mOhm max DCR / shielded composite | XGL6060-473MEC | Coilcraft | Coilcraft XGL6060 6.0 x 6.0 mm | AEC-Q200 | Wurth 74439346470; Bourns SRP6060A-470M | Marked short-lead side oriented to the SW node to keep the switching field away from the RF section. | Yes
12 | 1 | L201 | MCU DC/DC inductor | 10 uH / 0603 | NOT SELECTED | - | Inductor_SMD:L_0603_1608Metric | Not selected | TI recommends a specific L for the CC2340 internal DC/DC - see device datasheet | UNRESOLVED: no MPN assigned. Must select a part meeting TI's saturation-current and DCR requirement for the CC2340R5 internal DC/DC before release. | Yes
13 | 1 | L202 | RF matching inductor | 2.8 nH / 0402 / high-Q RF | NOT SELECTED | - | Inductor_SMD:L_0402_1005Metric | Not selected | Murata LQW15A series; Coilcraft 0402HP | UNRESOLVED: no MPN. Value copied from the TI LP-EM-CC2340R53 reference. Requires a high-Q RF inductor with tight tolerance; a general-purpose part will degrade the match. | Yes
14 | 1 | L301 | CAN common-mode choke | 100 uH common-mode / CAN and CAN FD rated | ACT45B-101-2P-TL003 | TDK | 4.5 x 3.2 mm (Inductor_SMD:L_CommonModeChoke_Coilank_ACM4532) | AEC-Q200 - VERIFY against TDK datasheet | Murata DLW43SH101XK2; Wurth 744232101 | Part taken from the TI TCAN4550EVM choke pad. FOOTPRINT IS A GENERIC ACM4532 LAND PATTERN - verify pad geometry AND terminal numbering against the TDK ACT45B drawing before fabrication; if ACT45B numbers its windings differently, swap the schematic symbol variant. | Yes
15 | 1 | R101 | Input damping / inrush resistor | 1 Ohm / 5% / 1 W / pulse-proof | CRCW25121R00JNEGIF | Vishay | R_2512_6332Metric | AEC-Q200 (Vishay CRCW-e3) | Vishay CRCW2512 standard; Bourns CRM2512 | Damps the input LC with C101 and limits hot-plug inrush. Approx 5 mW dissipation at nominal load - heavily de-rated for surge energy. | Yes
16 | 1 | R102 | Buck EN divider upper | 383 k / 1% / 0603 | CRCW0603383KFKEA | Vishay | R_0603_1608Metric | AEC-Q200 (Vishay CRCW-e3) | Panasonic ERJ series (AEC-Q200) | With R103 sets buck turn-on near 6.0 V and turn-off near 5.3 V, giving crank ride-through below the 9 V spec. Draws ~25 uA continuously from the vehicle battery - the largest fixed standby load. | Yes
17 | 3 | R103,R107,R405 | Pull-up / divider | 100 k / 1% / 0603 | CRCW0603100KFKEA | Vishay | R_0603_1608Metric | AEC-Q200 (Vishay CRCW-e3) | Panasonic ERJ series (AEC-Q200) | R103 buck EN divider lower; R107 PGOOD pull-up to +3V3_VEH; R405 USING_BATTERY_N pull-up to +3V3_SYS. | Yes
18 | 1 | R104 | Switching frequency set | 64.9 k / 1% / 0603 | CRCW060364K9FKEA | Vishay | R_0603_1608Metric | AEC-Q200 (Vishay CRCW-e3) | Panasonic ERJ series (AEC-Q200) | Sets nominal 400 kHz - the value used in the LMR38010-Q1 datasheet characterisation. | Yes
19 | 1 | R105 | Buck feedback upper | 54.9 k / 1% / 0603 | CRCW060354K9FKEA | Vishay | R_0603_1608Metric | AEC-Q200 (Vishay CRCW-e3) | Panasonic ERJ series (AEC-Q200) | 1 V x (1 + 54.9k/10k) = 6.490 V. Within TI's preferred 10k-100k divider range. | Yes
20 | 1 | R106 | Buck feedback lower | 10.0 k / 1% / 0603 | CRCW060310K0FKEA | Vishay | R_0603_1608Metric | AEC-Q200 (Vishay CRCW-e3) | Panasonic ERJ series (AEC-Q200) | 100 uA nominal divider current; routed as a quiet Kelvin connection to the analogue ground. | Yes
21 | 1 | U101 | Synchronous buck regulator | 4.2-80 V in, 6.49 V out, 1 A, PFM, spread spectrum, 40 uA Iq | LMR38010SQDDARQ1 | Texas Instruments | HSOIC-8 PowerPAD DDA (BLE_CAN:TI_DDA0008B_PowerPAD) | AEC-Q100 Grade 1 (-40 to +125 degC) | LMR38020SQDDARQ1 (2 A, same DDA package); LMR38010FSQDDARQ1 (FPWM variant - higher standby current) | PFM + spread-spectrum variant deliberately chosen: 40 uA non-switching Iq for parked current, spread spectrum for conducted/radiated EMI. Absolute max VIN 85 V covers the 64.5 V TVS clamp. | Yes
22 | 1 | U102 | Vehicle 3.3 V LDO | 3-40 V in, 3.3 V fixed, 150 mA, 2.7 uA Iq | TPS7B8133QDGNRQ1 | Texas Instruments | HVSSOP-8 PowerPAD DGN (BLE_CAN:TI_DGN0008G_PowerPAD) | AEC-Q100 Grade 1 | TPS7B6933QDBVRQ1 (SOT-23-5 - different footprint) | Fed from +6V5_CAN rather than VIN, cutting dissipation to ~64 mW at the ~20 mA design load. | Yes
23 | 1 | U201 | BLE 5.x wireless MCU | 512 KB flash, 2.4 GHz, 1.71-3.8 V, internal DC/DC | CC2340R53E0RKPR | Texas Instruments | QFN-40 RKP 5 x 5 mm (BLE_CAN:RKP0040B-MFG) | NOT AEC-Q100 - no automotive-qualified CC2340 orderable exists | CC2340R52E0RKPR (256 KB, same RKP package and pinout) | MCU SELECTION: CC2340R53E0RKPR (512 KB flash) is the project-selected orderable device in the CC2340R5 family. It is not AEC-Q100 qualified. Assumed cabin-mount, non-safety telematics use - see ARCHITECTURE.md assumptions. | Yes
24 | 7 | C201-C204,C206,C207,C215 | MCU decoupling | 100 nF / 0402 (voltage rating not specified) | NOT SELECTED | - | C_0402_1005Metric | Not selected | TDK CGA2B3X7R1H104K050BB (AEC-Q200) or Murata GCM155R71H104KE02 | UNRESOLVED: no MPN or voltage rating assigned. Specify >=16 V X7R AEC-Q200 parts before release. | Yes
25 | 2 | C205,C208 | MCU bulk decoupling | 10 uF / 0805 (voltage rating not specified) | NOT SELECTED | - | C_0805_2012Metric | Not selected | TDK CGA4J1X7R1C106K125AC (AEC-Q200) | UNRESOLVED: no MPN or voltage rating. C208 is the VDDR reservoir - TI specifies a minimum effective capacitance; confirm after derating. | Yes
26 | 1 | C209 | VDDD decoupling | 1 uF / 10 V / 0603 | NOT SELECTED | - | C_0603_1608Metric | Not selected | TDK CGA3E1X7R1A105K080AC (AEC-Q200) | UNRESOLVED: no MPN. Value per TI SWRA834A section 9.1. | Yes
27 | 2 | C210,C211 | HFXT load capacitor provision | DNP / 0402 | NOT FITTED | - | C_0402_1005Metric | n/a | - | Deliberately unfitted: the CC2340R5 internal load-capacitance array is used instead. Fit only if the internal array cannot reach the crystal's 7 pF CL on the assembled board. | No (DNP)
28 | 2 | C212,C213 | LSE crystal load capacitors | 15 pF / 50 V / C0G / 0402 | GRM1555C1H150JA01D | Murata | C_0402_1005Metric | NOT automotive - GRM is Murata's commercial series | Murata GCM1555C1H150JA16 (AEC-Q200, same size) - RECOMMENDED for production | Values assume ~1.5 pF board stray to hit CL = 9 pF. Stray not measured. Swap to the GCM automotive equivalent for production. | Yes
29 | 2 | C214,C216 | RF matching capacitors | 1.5 pF / 0402 / C0G RF | NOT SELECTED | - | C_0402_1005Metric | Not selected | Murata GJM1555C1H1R5BB01 (RF-grade C0G) | UNRESOLVED: no MPN. Values copied from the TI LP-EM-CC2340R53 reference. Tight-tolerance RF C0G parts required; the match has NOT been re-tuned for this board's U.FL + LPF combination. | Yes
30 | 1 | FLT201 | 2.4 GHz low-pass filter | 2400-2500 MHz LPF | DLF162500LT-5028A1 | TDK | 0603 (RF_BLE_PCBFootprints:DLF162500LT-5028A1) | Commercial - no automotive grade identified | Johanson 2450FM07A0029; Murata LFL21868MSA1A167 | This is a LOW-PASS filter (TDK title: 'Multilayer Low Pass Filter'), used for harmonic suppression - it is not a balun and not a band-pass filter. | Yes
31 | 1 | J201 | RF coaxial connector | 50 Ohm, DC-6 GHz, ~30 mating cycles | U.FL-R-SMT-1(10) | Hirose | Connector_Coaxial:U.FL_Hirose_U.FL-R-SMT-1_Vertical | Commercial | Amphenol A-1JB; I-PEX MHF I (20279-001E-01) | UNRESOLVED: no MPN field populated in the schematic. U.FL has no vibration lock and limited mating cycles - acceptable for an internal pigtail, not for a serviceable interface. Antenna itself is out of scope. | Yes
32 | 1 | X201 | LSE crystal | 32.768 kHz, CL 9 pF, ESR <=90 kOhm, -40 to +85 degC | ABS06-32.768KHZ-9-T | Abracon | Crystal_SMD_2012-2Pin_2.0x1.2mm | Commercial - verify; automotive variant needed for production | Epson FC-135 automotive; Abracon ABS07AIG series (confirm AEC-Q200 status and CL) | Rated to +85 degC only, below the +125 degC of the automotive ICs around it. Load capacitance and startup margin not measured on an assembled board. | Yes
33 | 1 | X202 | HFXT crystal | 48 MHz, CL 7 pF, 4-pad | ABM11W-48.0000MHZ-7-D1X-T3 | Abracon | Crystal_SMD_2016-4Pin_2.0x1.6mm | Commercial - verify; automotive variant needed for production | NDK NX2016SA 48 MHz; Epson TSX-3225 48 MHz (AEC-Q200 variants available) | Relies on the MCU internal cap array (C210/C211 DNP). PCB traces are long and asymmetric (X48P 11.1 mm vs X48N 7.6 mm) - added stray may prevent the array reaching CL = 7 pF. Must be verified on hardware. | Yes
34 | 1 | R201 | MCU reset pull-up | 100 k / 0402 | NOT SELECTED | - | R_0402_1005Metric | Not selected | Vishay CRCW0402100KFKED (AEC-Q200) | UNRESOLVED: no MPN or tolerance assigned. | Yes
35 | 1 | U301 | CAN FD controller + transceiver | VSUP 6-24 V, VIO 3.135-5.25 V, CAN FD to 8 Mbps, SPI, 125 mA VCCOUT LDO | TCAN4550RGYRQ1 | Texas Instruments | VQFN-20 RGY 4.5 x 3.5 mm (BLE_CAN:TI_RGY0020A_VQFN20) | AEC-Q100 Grade 1 (-40 to +125 degC) | TCAN4550A-Q1 (updated silicon revision - check errata and register map) | Hottest device on the board: ~0.45 W dominant, Tj ~101 degC at 85 degC ambient (RthetaJA 35.2 degC/W). VIO sits at 3.0 V in battery backup, below the 3.135 V recommended minimum - accepted because CAN is defined as unavailable in backup. | Yes
36 | 1 | X301 | CAN reference crystal | 40 MHz, CL 8 pF, 4-pad | NOT SELECTED | - | Crystal_SMD_2016-4Pin_2.0x1.6mm | Not selected | NDK NX2016SA 40 MHz; Epson TSX-3225 40 MHz (AEC-Q200 variants available) | UNRESOLVED and the most significant BOM gap: no manufacturer part selected. Frequency tolerance drives CAN FD bit timing. Crystal motional parameters also determine the final C303/C304 and R311 values (DFMEA CAN-002). | Yes
37 | 2 | C303,C304 | CAN crystal load capacitors | 10 pF / 50 V / C0G / 0603 | CGA3E2C0G1H100D080AA | TDK | C_0603_1608Metric | AEC-Q200 (TDK CGA) | Murata GCM1885C1H100DA16 | Assumes ~3 pF board stray against a CL = 8 pF crystal. Provisional - final value to be set on the prototype per TI SLLA549. | Yes
38 | 1 | C306 | TCAN4550 FLTR capacitor | 470 nF / 16 V / X7R / 0603 | CGA3E1X7R1C474K080AC | TDK | C_0603_1608Metric | AEC-Q200 (TDK CGA) | Murata GCM188R71C474KA55 | Must retain >=300 nF effective after bias/temperature/aging (datasheet minimum). 470 nF nominal gives margin. | Yes
39 | 1 | C309 | Split-termination common-mode capacitor | 4.7 nF / 50 V / X7R / 0603 | CGA3E2X7R1H472K080AA | TDK | C_0603_1608Metric | AEC-Q200 (TDK CGA) | Murata GCM188R71H472KA37 | Fitted only together with R302/R303 when the module is a bus end node. | No (DNP)
40 | 1 | D301 | CAN bus ESD / transient clamp | 27 V standoff, 20 kV IEC 61000-4-2 contact, ~6 pF line capacitance | PESD2CANFD27V-T | Nexperia | SOT-23 | AEC-Q101 | ON Semi NUP2105LT1G; TI TPD2E007-Q1 | 27 V standoff chosen so a CANH/CANL short to a 24 V vehicle rail does not cause conduction. Low capacitance preserves CAN FD edges. Placed at the connector, ahead of L301 in the signal path. | Yes
41 | 4 | R301,R304,R305,R306 | CAN control pull-up / pull-down | 10 k / 1% / 0603 | CRCW060310K0FKEA | Vishay | R_0603_1608Metric | AEC-Q200 (Vishay CRCW-e3) | Panasonic ERJ series (AEC-Q200) | R301 nCS pull-up (keeps TCAN deselected during MCU reset); R304 WAKE to GND (local wake unused); R305 RST pull-down (RST is active HIGH); R306 nINT pull-up (datasheet requires 2-10 k). | Yes
42 | 2 | R302,R303 | Split termination | 60.4 Ohm / 1% / 0805 | CRCW080560R4FKEA | Vishay | R_0805_2012Metric | AEC-Q200 (Vishay CRCW-e3) | Panasonic ERJ series (AEC-Q200) | DNP by default - the module is assumed a stub node. Fit both plus C309 (120.8 Ohm total) only at a bus end node. Topology is an assumption, not a verified requirement. | No (DNP)
43 | 4 | R307-R310 | SPI / wake bias resistors | 100 k / 1% / 0603 | CRCW0603100KFKEA | Vishay | R_0603_1608Metric | AEC-Q200 (Vishay CRCW-e3) | Panasonic ERJ series (AEC-Q200) | R307 nWKRQ pull-up - see DFMEA CAN-001 (OPEN): firmware must set register 0x0800 bit 19 to select VIO open-drain mode; the default internal 3.6 V driver is unsafe when the MCU rail is low. R308-R310 define SPI levels when the MCU tri-states in backup. | Yes
44 | 1 | R311 | Crystal series damping provision | 0 Ohm / 0603 | CRCW06030000Z0EA | Vishay | R_0603_1608Metric | AEC-Q200 (Vishay CRCW-e3) | Any AEC-Q200 0603 jumper | Provision per TI SLLA549. 0 Ohm for first assembly only - final value determined by prototype oscillator characterisation. | Yes
45 | 1 | J301 | CAN bus connector | 6 A / 160 V, 2.54 mm pitch screw terminal | 1725669 | Phoenix Contact | TerminalBlock_Phoenix_MPT-0.5-3-2.54_1x03_P2.54mm_Horizontal | NOT automotive - industrial terminal block, no vibration or sealing rating | TE AMPSEAL 16 series; Molex MX150 (sealed automotive) | Prototype/bench connector. Pinout 1 = CANH, 2 = CANL, 3 = GND. Production build requires a sealed, keyed, vibration-rated connector per the OEM harness spec. The 0.34 mm pad-to-pad copper gap is set by the 2.54 mm pitch. | Yes
46 | 3 | U401,U403,U404 | Ideal diode / reverse-current block | 1.5-5.5 V, 1.5 A, 79 mOhm typical Ron | LM66100QDCKRQ1 | Texas Instruments | SC-70-6 DCK (Package_TO_SOT_SMD:SOT-363_SC-70-6) | AEC-Q100 Grade 1 | LM66200-Q1 (dual channel - different package and pinout) | U403/U404 implement the LM66100-Q1 datasheet section 9.2.1 cross-coupled-CE ORing; CE is a comparator against the device's own VIN, so priority is analogue and needs no firmware. U401 uses the section 8.3.2 always-on reverse-current-blocking configuration. | Yes
47 | 1 | U402 | Battery backup LDO | 3-40 V in, 3.0 V fixed, 150 mA, 2.8 uA Iq | TPS7E8130QDBVRQ1 | Texas Instruments | SOT-23-5 DBV | AEC-Q100 Grade 1 | TPS7B8130QDBVRQ1 (similar Iq and package) | The 3.0 V setpoint is deliberate: the 0.3 V offset below +3V3_VEH gives the ORing pair a decisive priority margin and avoids the datasheet's equal-rails lockout case. | Yes
48 | 1 | F401 | Battery branch fuse | 1 A fast-acting / 32 V | MFU0603FF01000P1AT | Vishay | Fuse_0603_1608Metric | AEC-Q200 | Littelfuse 0453001.MR; Bel Fuse 0603FA1-R | Board-fault protection only - coordinates with (does not replace) the battery pack's own protection circuit. | Yes
49 | 3 | C401,C402,C406 | Battery branch decoupling | 1 uF / 16 V / X7R / 0603 | CGA3E1X7R1C105K080AC | TDK | C_0603_1608Metric | AEC-Q200 (TDK CGA) | Murata GCM188R71C105KA64 | C401 connector-side reservoir for insertion bounce; C402/C406 local VIN decoupling for U401/U404 per the LM66100-Q1 datasheet. | Yes
50 | 2 | C403,C405 | Battery LDO input / output capacitors | 4.7 uF / 25 V / X7R / 0805 | CGA4J1X7R1E475K125AC | TDK | C_0805_2012Metric | AEC-Q200 (TDK CGA) | Murata GCM21BR71E475KA73 | U402 requires 2.2-100 uF for stability; must remain >=2.2 uF effective after ~50% derating. | Yes
51 | 1 | R401 | Ideal-diode CE series resistor | 10 k / 1% / 0603 | CRCW060310K0FKEA | Vishay | R_0603_1608Metric | AEC-Q200 (Vishay CRCW-e3) | Panasonic ERJ series (AEC-Q200) | The RCE resistor recommended by the LM66100-Q1 datasheet to limit CE pin current during a reverse-battery insertion (<0.5 mA at -4.2 V). | Yes
52 | 1 | R402 | Battery inrush limiter | 2.0 Ohm / 1% / 0603 | CRCW06032R00FKEA | Vishay | R_0603_1608Metric | AEC-Q200 (Vishay CRCW-e3) | Panasonic ERJ series (AEC-Q200) | Keeps the U401 body-diode insertion pulse below its 2.5 A rating; costs 60 mV at 30 mA. | Yes
53 | 2 | R403,R404 | Battery sense divider | 1.0 M / 1% / 0603 | CRCW06031M00FKEA | Vishay | R_0603_1608Metric | AEC-Q200 (Vishay CRCW-e3) | Panasonic ERJ series (AEC-Q200) | 2:1 divider keeps 4.2 V inside the ADC range; total drain ~2.1 uA. NOTE: VBAT_SENSE is NOT currently connected to any CC2340 ADC pin - provisioned only. | Yes
54 | 1 | J401 | Battery connector | 2 A, 2.00 mm pitch, polarized | S2B-PH-K-S(LF)(SN) | JST | Connector_JST:JST_PH_S2B-PH-K_1x02_P2.00mm_Horizontal | NOT automotive - no vibration or sealing rating | JST GH series; Molex PicoBlade (both still non-automotive) | Pin 1 = BAT+, pin 2 = BAT-. Polarity must be marked on the silkscreen and verified against the pack pigtail before first insertion. Production build needs a locking automotive connector. | Yes

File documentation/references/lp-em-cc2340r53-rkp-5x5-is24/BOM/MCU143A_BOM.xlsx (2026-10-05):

 |  |  |  |  | Capture CIS Standard Bill Of Materials - Standard Report
 |  |  |  |  |  | Report Created on Friday Dec 15 08:40:05 2023
Design Modify Date = Friday, December 15, 2023
Title = LP-EM-CC2340R53
Variant Name = A
Part Number | Quantity | Part Reference | Value | Description | Vendor | Vendor Part Number | PCB Package | Maximum Operating Temperature | ROHS | PCB Footprint | Vendor Part Status
13-00347 | 1 | ANT1 | 2.4GHz | ANTENNA, NON COMPONENT, 2.4GHz INVERTED F ANTENNA, NOT APPLY | TEXAS INSTRUMENTS | DN007 |  | +85DEGC | Not Applicable | ANTENNA_DN007AN | Active
01-01788 | 1 | B1 | 0 | RESISTOR, THICK FILM, 0, 0R/+0.05R, 1A, -55DEGC/+155DEGC, 0603, SMD | KOA SPEER | RK73Z1JTTD | 0603 | +155DEGC | Exempt | RESC1608X55A2N | Active
02-10417 | 1 | C9 | 1uF | CAPACITOR, CERAMIC X7R, 1uF, 10V, -10%/+10%, -55DEGC/+125DEGC, 0402, SMD | MURATA | GRM155Z71A105KE01D | 0402 | +125DEGC | Compliant | CAPC1005X60B2N | Active
02-06129 | 2 | C33 C34 | 1.5pF | CAPACITOR, CERAMIC C0G/NP0, 1.5pF, 50V, -0.1pF/+0.1pF, -55DEGC/+125DEGC, 0201, SMD | MURATA | GRM0335C1H1R5BA01J | 0201 | +125DEGC | Compliant | CAPC0603X35B2N | Active
Do Not Stuff | 0 | C52 C53 | Do Not Stuff | Do Not Stuff | Do Not Stuff | Do Not Stuff | Do Not Stuff | Do Not Stuff | Do Not Stuff | Do Not Stuff | Do Not Stuff
02-10308 | 8 | C55 C92 C99 C101 C102 C103 C106 C107 | 0.1uF | CAPACITOR, CERAMIC X7S, 0.1uF, 10V, -10%/+10%, -55DEGC/+125DEGC, 0201, SMD | MURATA | GRM033C71A104KE14D | 0201 | +125DEGC | Compliant | CAPC0603X35B2N | Active
02-10307 | 1 | C81 | 12pF | CAPACITOR, CERAMIC C0G/NP0, 12pF, 50V, -2%/+2%, -55DEGC/+125DEGC, 0201, SMD | MURATA | GRM0335C1H120GA01D | 0201 | +125DEGC | Compliant | CAPC0603X35B2N | Active
02-09323 | 2 | C91 CA2 | 15pF | CAPACITOR, CERAMIC C0G/NP0, 15pF, 50V, -2%/+2%, -55DEGC/+125DEGC, 0201, SMD | MURATA | GRM0335C1H150GA01D | 0201 | +125DEGC | Compliant | CAPC0603X35B2N | Active
02-10418 | 2 | C104 C105 | 10uF | CAPACITOR, CERAMIC X7R, 10uF, 10V, -10%/+10%, -55DEGC/+125DEGC, 0603, SMD | MURATA | GRM188Z71A106KA73D | 0603 | +125DEGC | Compliant | CAPC1608X100A2N | Active
Do Not Stuff | 0 | CA1 | Do Not Stuff | Do Not Stuff | Do Not Stuff | Do Not Stuff | Do Not Stuff | Do Not Stuff | Do Not Stuff | Do Not Stuff | Do Not Stuff
15-01023 | 1 | CR1 | LPL296-J2L2-25 | OPTO, LED, InGaAlP, GREEN, 560nm, 2V, 0.02A, 0603, SMD | OSRAM | LP L296-J2L2-25 | 0603 | +100DEGC | Compliant | LEDC1707X65N | Active
15-01169 | 1 | CR2 | LS L296-P2Q2-1 | OPTO, LED, RED, 630nm, 2V, 0.02A, 0603, SMD | OSRAM | LS L296-P2Q2-1 | 0603 | +100DEGC | Compliant | LEDC1708X67N | Active
14-05493 | 2 | CR8 CR9 | TPD6E004RSE | DIODE, PROTECTION, ESD ARRAY - 6 CHANNELS, 0.9V TO 5.5V, VBR:7V, -40DEGC/+85DEGC, QFN8, SMD | TEXAS INSTRUMENTS | TPD6E004RSER | QFN8 | +85DEGC | Compliant | QFNFC50P150X150X60-8A2N | Active
14-06704 | 1 | CR10 | TPD1E0B04DPY | DIODE, PROTECTION, TVS, BID, 6.7V, 15W, -40DEGC/+125DEGC, X1SON2, SMD | TEXAS INSTRUMENTS | TPD1E0B04DPYR | SON2 | +125DEGC | Compliant | SON65P100X60X45-2A2N | Active
19-00300 | 6 | FIDU1 FIDU2 FIDU3 FIDU4 FIDU5 FIDU6 | FIDU_1.27mm | NON COMPONENT, FIDUCIAL MARK, ROUND 1.27MM, SMD | NON_COMPONENT | FIDUCIAL_1.27mm |  |  | Not Applicable | FID127X142 | Active
06-04997 | 2 | J1 J2 | SSQ-110-23-L-D | CONNECTOR, HEADER, FEMALE, STRAIGHT, 2 ROWS, 20 PINS, 2.54mm, PTH | SAMTEC | SSQ-110-23-L-D |  | +125DEGC | Compliant | SAMTEC_SSQ11023LD_A2B | Active
06-02188 | 1 | J7 | SMA-10V21-TGG | CONNECTOR, COAX, RF, FEMALE, STRAIGHT, 1 PIN, SMD | HUS-TSAN | SMA-10V21-TGG |  |  | Compliant | HUSTSAN_SMA10V21TGGAN | Active
03-08367 | 1 | L1 | 10uH | INDUCTOR, STANDARD, CHIP, FERRITE CORE, 10uH, -20%/+20%, 0.1A, -55DEGC/+125DEGC, 0603, SMD | MURATA | LQM18DN100M70L | 0603 | +125DEGC | Compliant | INDC1608X100A2N | Active
03-06931 | 1 | L33 | 2.8nH | INDUCTOR, RF, CHIP, NON-MAGNETIC CORE, 2.8nH, -0.1nH/+0.1nH, 0.5A, -55DEGC/+125DEGC, 0201, SMD | MURATA | LQP03TN2N8B02J | 0201 | +125DEGC | Compliant | INDC0603X33A2N | Active
19-00350 | 1 | LBL1 | TI_LOGO | NON COMPONENT, LABEL, TEXAS INSTRUMENTS LOGO | NON_COMPONENT | TI_LOGO |  |  | Missing Info | TI_LOGO_1 | Active
19-01044 | 1 | LBL2 | TRASH_7mm | NON COMPONENT, LABEL, TRASH 7mm | NON_COMPONENT | TRASH_7mm |  |  | Not Applicable | TRASH_7MM | Active
19-00471 | 1 | LBL3 | ESD_LABEL_5x5mm | NON COMPONENT, LABEL, ESD, 5 X 5 mm | NON_COMPONENT | ESD_LABEL_5x5mm |  | N/A | Not Applicable | ESD_LABEL_5X5 | Active
19-00351 | 1 | LBL4 | CE_label | NON COMPONENT, LABEL, CE | NON_COMPONENT | CE_LABEL |  |  | Not Applicable | CE_MARKING | Active
19-00830 | 1 | LBL5 | LABEL_FOR_EVALUATION_ONLY | NON COMPONENT, LABEL, FOR EVALUATION ONLY, NOT FCC APPROVED FOR RESALE | NON_COMPONENT | LABEL_FOR_EVALUATOIN_ONLY |  | N/A | Missing Info | LABEL_FOR_EVALUATION_ONLY | Active
19-00498 | 2 | M1 M2 | SNT-100-BK-G | MECHANIC, SHUNT, CURRENT RATING 4.3A PER PIN, 2.54 X 5.08 X 6.1mm, BLACK | SAMTEC | SNT-100-BK-G |  | +125DEGC | Compliant | SAMTEC_SNT100BKG | Active
13-07898 | 4 | M3 M4 M5 M6 | DCB-12D | MECHANIC, ACCESSORY, SPACER SUPPORT, PCB DIA. 3mm, NYLON 66, NPTH | SUZHOU SOLY ELECTRICIAN | DCB-12D |  | N/A | Compliant | MECH_DCB12D_A2B | Active
06-05038 | 2 | P1 P5 | BB02-HC031-KB1-603000 | CONNECTOR, HEADER, MALE, STRAIGHT, 1 ROW, 3 PINS, PITCH 2.54mm, PTH | GRADCONN | BB02-HC031-KB1-603000 |  | +105DEGC | Compliant | GRADCONN_BB02HC031KB1603000_A2B | Active
06-04999 | 1 | P2 | BB02-HJ041-KB1-603000 | CONNECTOR, HEADER, MALE, STRAIGHT, 2 ROWS, 4 PINS, PITCH 2.54mm, PTH | GRADCONN | BB02-HJ041-KB1-603000 |  | +105DEGC | Compliant | GRADCONN_BB02HJ041KB1603000_A2B | Active
06-12237 | 1 | P3 | SFH11-PBPC-D10-RA-BK | CONNECTOR, HEADER, FEMALE, RIGHT ANGLE, 2 ROW(S), 20 PINS, PITCH 2.54mm, PTH | SULLINS | SFH11-PBPC-D10-RA-BK |  | +105DEGC | Compliant | SULLINS_SFH11PBPCD10RABK_A2B | Active
06-00166 | 1 | P4 | FTSH-105-01-F-DV-K | CONNECTOR, HEADER, MALE, STRAIGHT, 2 ROWS, 10 PINS, PITCH 1.27mm, SMD | SAMTEC | FTSH-105-01-F-DV-K |  | +125DEGC | Compliant | SAMTEC_FTSH-105-01-F-DV-K-10N | Active
01-04220 | 1 | R1 | 100k | RESISTOR, THICK FILM, 100k, -5%/+5%, 0.05W, 30V, -55DEGC/+155DEGC, 0201, SMD | VISHAY | CRCW0201100KJNED | 0201 | +155DEGC | Exempt | RESC0603X35B2N | Active
01-20043 | 4 | R4 R5 R25 R51 | 0 | RESISTOR, THICK FILM, 0, 0R/+0.02R, 0.1W, 2A, -55DEGC/+155DEGC, 0603, SMD | VISHAY | CRCW06030000Z0EC | 0603 | +155DEGC | Exempt | RESC1608X55A2N | Active
Do Not Stuff | 0 | R6 R7 | Do Not Stuff | Do Not Stuff | Do Not Stuff | Do Not Stuff | Do Not Stuff | Do Not Stuff | Do Not Stuff | Do Not Stuff | Do Not Stuff
01-22345 | 1 | R14 | 180 | RESISTOR, THICK FILM, 180, -5%/+5%, 0.063W, 50V, -55DEGC/+155DEGC, 0402, SMD | VISHAY | CRCW0402180RJNED | 0402 | +155DEGC | Exempt | RESC1005X40B2N | Active
01-22346 | 1 | R15 | 220 | RESISTOR, THICK FILM, 220, -5%/+5%, 0.063W, 50V, -55DEGC/+155DEGC, 0402, SMD | VISHAY | CRCW0402220RJNED | 0402 | +155DEGC | Exempt | RESC1005X40B2N | Active
Do Not Stuff | 0 | R19 R20 R21 R22 R23 R52 | Do Not Stuff | Do Not Stuff | Do Not Stuff | Do Not Stuff | Do Not Stuff | Do Not Stuff | Do Not Stuff | Do Not Stuff | Do Not Stuff
01-22487 | 1 | R24 | 2.2k | RESISTOR, THICK FILM, 2.2k, -5%/+5%, 0.063W, 50V, -55DEGC/+155DEGC, 0402, SMD | VISHAY | CRCW04022K20JNED | 0402 | +155DEGC | Exempt | RESC1005X40B2N | Active
01-22482 | 2 | R55 R56 | 100 | RESISTOR, THICK FILM, 100, -5%/+5%, 0.063W, 50V, -55DEGC/+155DEGC, 0402, SMD | VISHAY | CRCW0402100RJNED | 0402 | +155DEGC | Exempt | RESC1005X40B2N | Active
Do Not Stuff | 0 | R66 R67 | Do Not Stuff | Do Not Stuff | Do Not Stuff | Do Not Stuff | Do Not Stuff | Do Not Stuff | Do Not Stuff | Do Not Stuff | Do Not Stuff
08-00293 | 2 | SW1 SW2 | 1188E-1K2 | SWITCH, TACT, 0.05A@12VDC, 0.05A@250VAC, SMD | DIPTRONICS | 1188E-1K2-V-TR |  | +70DEGC | Compliant | SW_1188E1K2V_A2N | Active
18-38719 | 1 | U1 | CC2340R53E0RKP | IC, MICROCONTROLLER, CC2340R5, 32-bit, SIMPLELINK WIRELESS MCU ARM CORTEX -M0+, 512kbyte FLASH, 1.71V TO 3.8V, VQFN40-EP, SMD | TEXAS INSTRUMENTS | CC2340R53E0RKPR | VQFN40-EP | +125DEGC | Missing Info | QFNFC40P500X500X100-41B2N | Preliminary
18-31726 | 1 | U3 | MX25R8035FZUIL0 | IC, MEMORY, FLASH, OTHER, 8Mbit, 8M X 1bit / 4M X 2bit / 2M X 4bit, 12ns, 1.65V TO 3.6V, uSON8, SMD | MACRONIX | MX25R8035FZUIL0 | uSON8 | +85DEGC | Compliant | SON50P300X200X60-9B2N | Active
18-36044 | 1 | U4 | CAT24C08TDI | IC, MEMORY, ROM, EEPROM, SERIAL, I2C, 8kbit, 1k X 8bit, 900ns, 1.7V TO 5.5V, TSOT23-5, SMD | ONSEMI | CAT24C08TDI-GT3 | TSOT23-5 | +85DEGC | Compliant | SOT95P280X100-5A2N | Active
12-01593 | 1 | Y1 | 32.768KHz | CRYSTAL, RESONATOR, 32.768KHz, -380PPM/+380PPM, -40DEGC/+125DEGC, SMD | TAI-SAW | TZ3359DAAO73 |  | +125DEGC | Compliant | XTAL_TZ3359DAAO73_A2N | Active
12-01592 | 1 | Y2 | 48MHz | CRYSTAL, RESONATOR, 48MHz, -30PPM/+30PPM, -40DEGC/+125DEGC, SMD | TAI-SAW | TZ3908AAAO43 |  | +125DEGC | Compliant | OSCCC205X165X50-4A2N | Active
02-06126 | 1 | Z60 | 1.2pF | CAPACITOR, CERAMIC C0G/NP0, 1.2pF, 50V, -0.1pF/+0.1pF, -55DEGC/+125DEGC, 0201, SMD | MURATA | GRM0335C1H1R2BA01J | 0201 | +125DEGC | Compliant | CAPC0603X35B2N | Active
03-06923 | 1 | Z61 | 2nH | INDUCTOR, RF, CHIP, NON-MAGNETIC CORE, 2nH, -0.1nH/+0.1nH, 0.6A, -55DEGC/+125DEGC, 0201, SMD | MURATA | LQP03TN2N0B02J | 0201 | +125DEGC | Compliant | INDC0603X33A2N | Active
02-06121 | 1 | Z62 | 0.7pF | CAPACITOR, CERAMIC C0G/NP0, 0.7pF, 50V, -0.1pF/+0.1pF, -55DEGC/+125DEGC, 0201, SMD | MURATA | GRM0335C1HR70BA01J | 0201 | +125DEGC | Compliant | CAPC0603X35B2N | Active

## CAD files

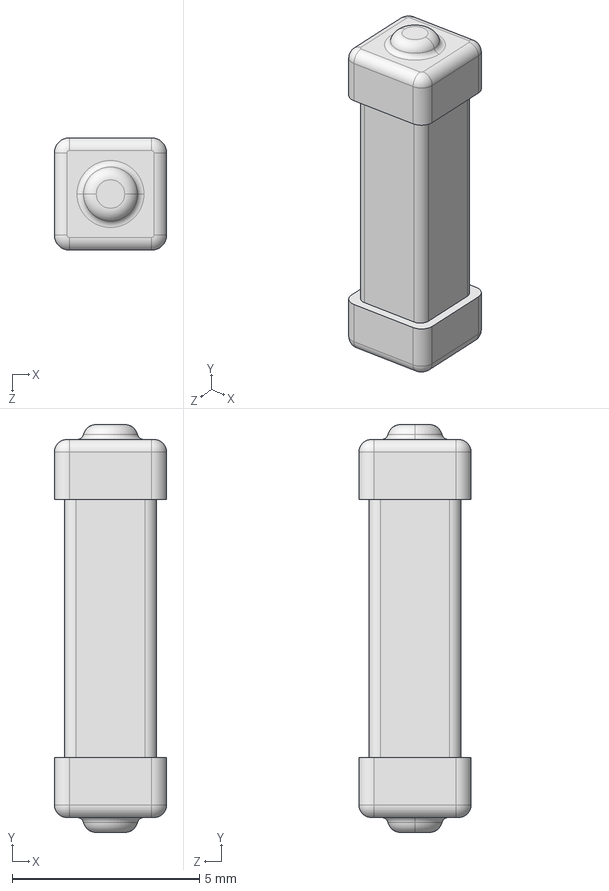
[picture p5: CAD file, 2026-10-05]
hardware/3d_Models/3403.0166.24/3D/3403.0166.24.stp
3.00 x 10.9 x 3.00 mm

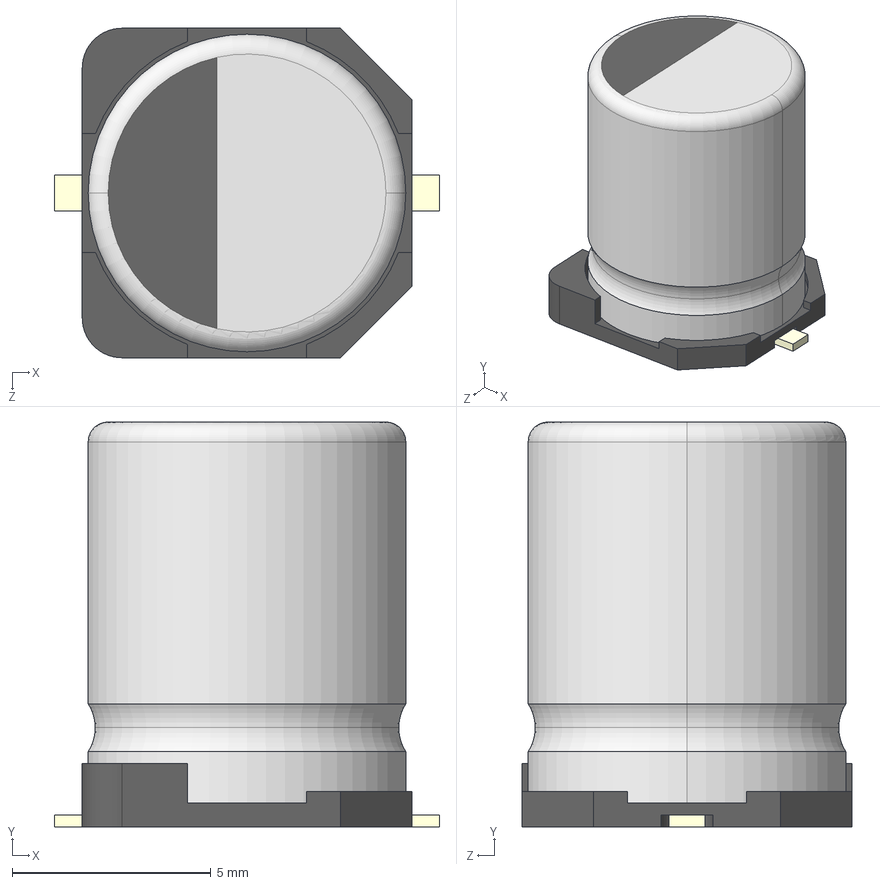
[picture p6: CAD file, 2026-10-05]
hardware/3d_Models/EEEFK2A220P/3D/EEEFK2A220P.stp
9.70 x 10.2 x 8.30 mm
標準SIZE CODE F-001
標準SIZE CODE F-002
標準SIZE CODE F-003 x 2

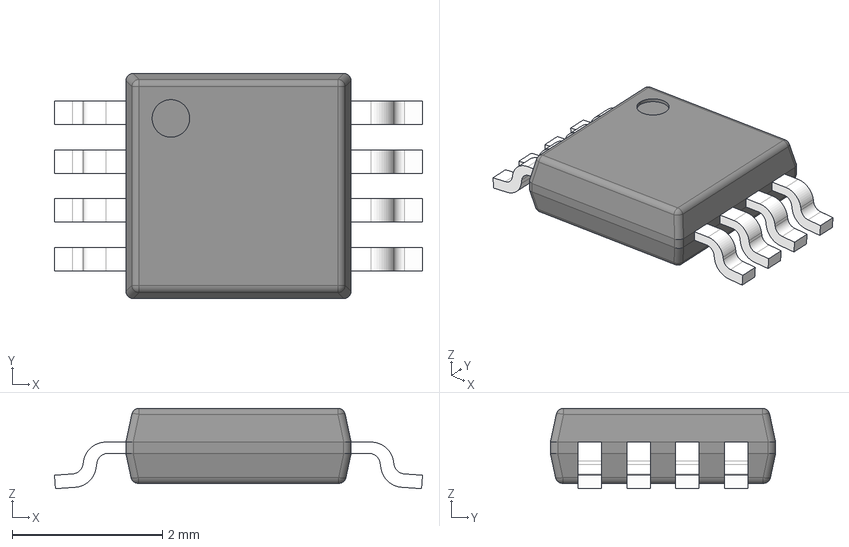
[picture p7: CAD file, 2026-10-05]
hardware/3d_Models/TPS7B8133QDGNRQ1/3D/TPS7B8133QDGNRQ1.stp
4.90 x 3.00 x 1.07 mm
BODY-DGN0008G
LEAD-DGN0008G x 8
PIN1_DGN0008G
DAP_DGN0008G

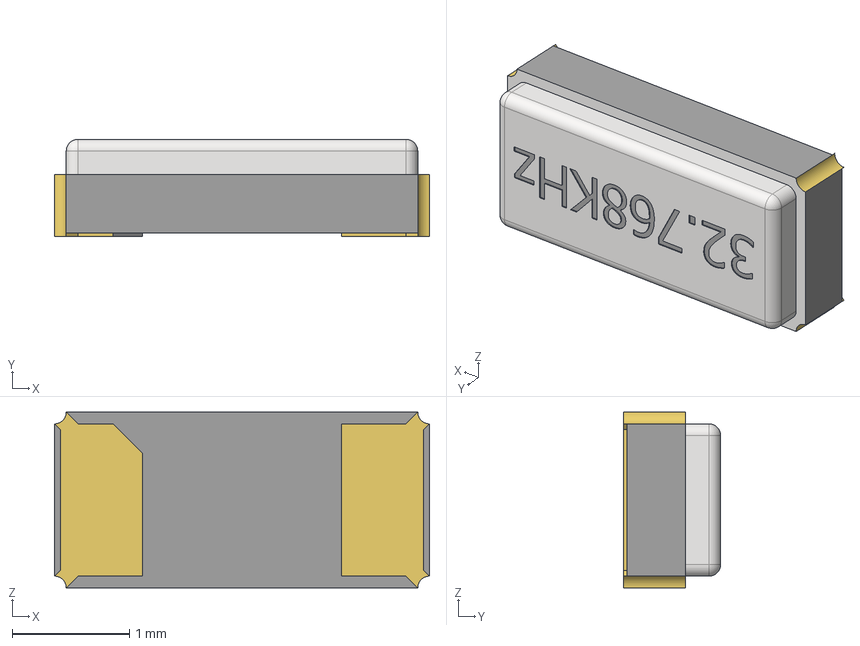
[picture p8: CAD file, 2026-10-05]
hardware/3d_Models/Crystal_3215.stp
3.20 x 0.83 x 1.50 mm

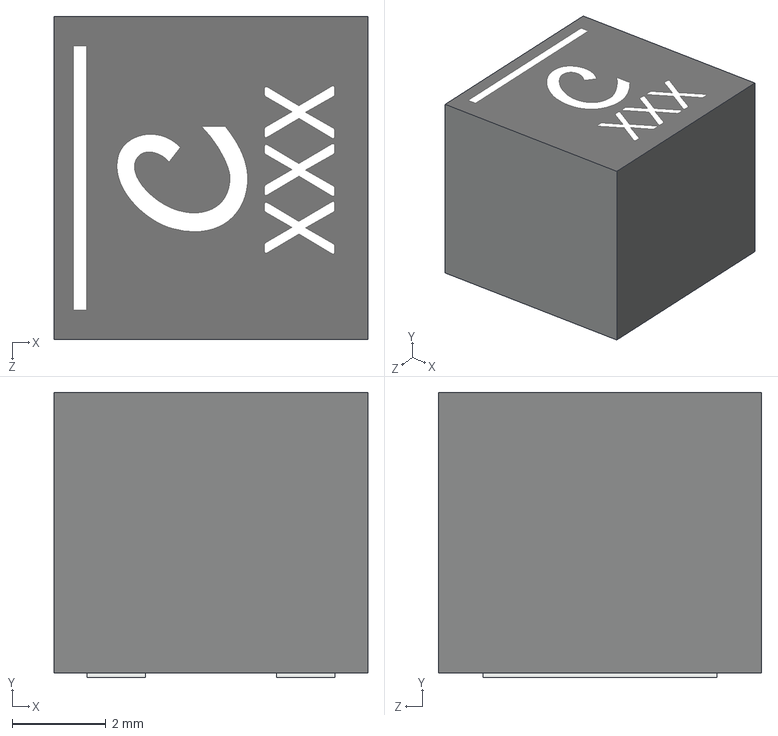
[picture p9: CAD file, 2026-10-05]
hardware/3d_Models/XGL6060.STEP
6.71 x 6.10 x 6.91 mm

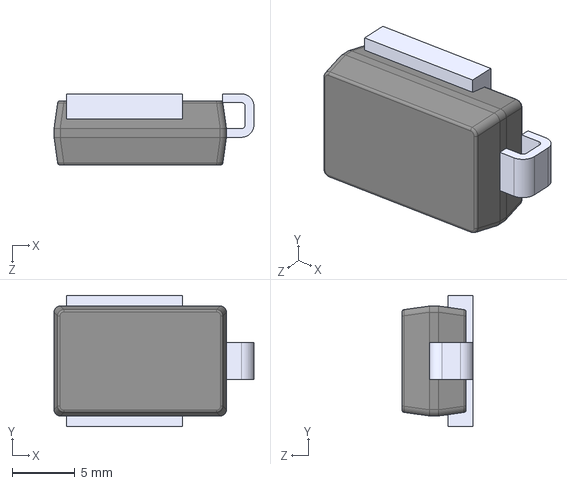
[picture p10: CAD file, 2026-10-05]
hardware/3d_Models/DIO_JEDEC_DO-218AC.STEP
16.0 x 10.5 x 5.70 mm

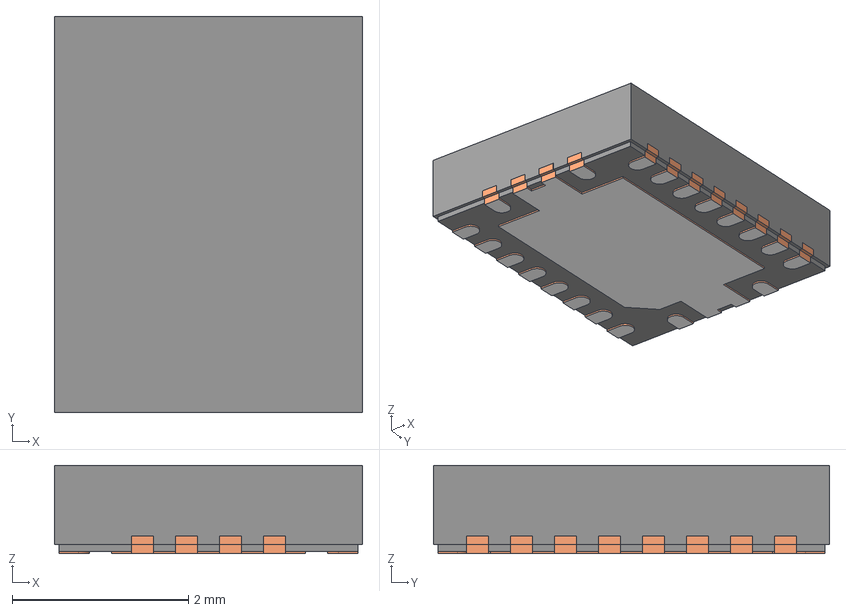
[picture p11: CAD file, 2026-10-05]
hardware/3d_Models/RGY0020C.stp
3.50 x 4.50 x 1.00 mm
BODY-QFN_AF0
FRAME-RGY0020C_AF0
PIN1-ID

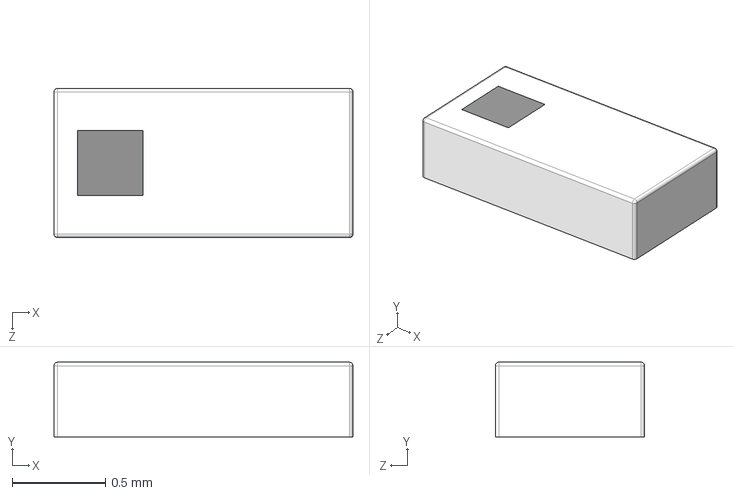
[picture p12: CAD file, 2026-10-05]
hardware/3d_Models/DLF162500LT-5028A1--3DModel-STEP-269445.STEP
1.60 x 0.4 x 0.8 mm

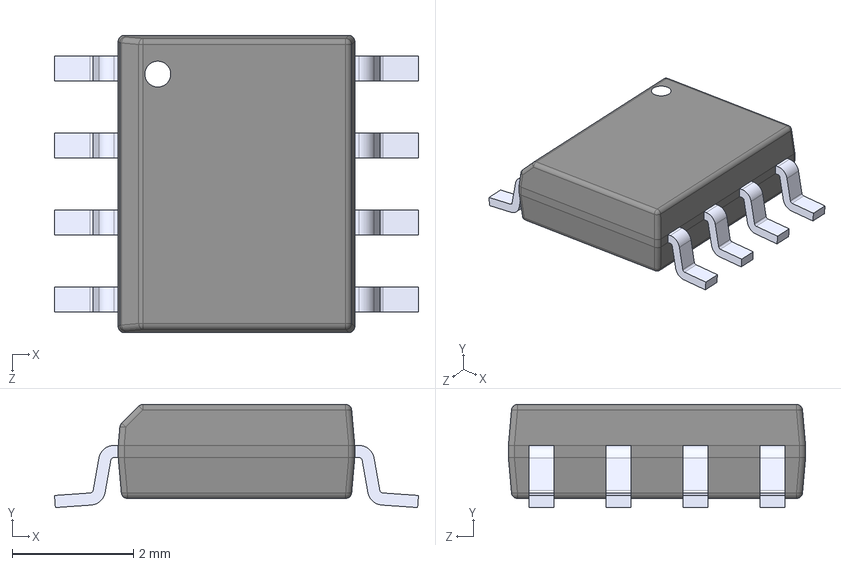
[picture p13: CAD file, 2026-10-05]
hardware/3d_Models/LMR38010SQDDARQ1/3D/LMR38010SQDDARQ1.stp
6.00 x 1.70 x 4.90 mm

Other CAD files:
hardware/3d_Models/3403.0166.24/Allegro/3403016624.psm
hardware/3d_Models/3403.0166.24/DEHDL/3403.0166.24/chips/chips.prt
hardware/3d_Models/EEEFK2A220P/Allegro/eehzt1e331up.psm
hardware/3d_Models/EEEFK2A220P/DEHDL/eeefk2a220p/chips/chips.prt
hardware/3d_Models/LMR38010SQDDARQ1/Allegro/soic127p600x170-9n.psm
hardware/3d_Models/LMR38010SQDDARQ1/DEHDL/lmr38010sqddarq1/chips/chips.prt
hardware/3d_Models/TPS7B8133QDGNRQ1/Allegro/sop65p490x110-9n.psm
hardware/3d_Models/TPS7B8133QDGNRQ1/DEHDL/tps7b8133qdgnrq1/chips/chips.prt

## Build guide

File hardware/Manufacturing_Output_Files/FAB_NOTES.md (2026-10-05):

# Fabrication and Assembly Notes — Automotive BLE-CAN Module

These notes accompany the Gerber/drill package in `gerbers_drill_files/` and are part
of the manufacturing data. Requirements here are mandatory unless marked informative.

## 1. Board and stackup

| Parameter | Value |
| --- | --- |
| Finished thickness | 1.58 mm ± 10% |
| Layer count | 4 (F.Cu / In1.Cu / In2.Cu / B.Cu), 35 µm (1 oz) each |
| Dielectric 1 (F.Cu–In1.Cu) | 0.11 mm 2116 prepreg, Er ≈ 4.29 |
| Core (In1.Cu–In2.Cu) | 1.2 mm FR4, Er ≈ 4.6 |
| Dielectric 3 (In2.Cu–B.Cu) | 0.11 mm 2116 prepreg, Er ≈ 4.29 |
| Surface finish | HAL lead-free |
| Soldermask | Both sides, green or fab standard |
| Silkscreen | Both sides, white |

Layer roles: F.Cu signal/components, In1.Cu continuous GND reference (do not modify),
In2.Cu power distribution, B.Cu ground pour and stitching.

## 2. Controlled impedance — REQUIRED

**2.4 GHz RF path (F.Cu, referenced to In1.Cu GND):** the antenna feed from the MCU
(U201 pin 39) through the matching network (C214, L202, C216), band-pass filter
(FLT201), to the U.FL connector (J201) is designed as a **50 ohm single-ended
microstrip**. As drawn, the trace width is 0.18 mm over the 0.11 mm 2116 prepreg.

- Target: **50 ohm ± 10 %** single-ended.
- The fab shall confirm the stackup achieves this at the drawn 0.18 mm width, or
  advise the adjusted width/prepreg required. Any width change must be agreed
  before tooling; do not resize the trace unilaterally.
- Provide an impedance test coupon on the production panel and an impedance
  report with the shipment.
- Dielectric constraints in the Gerber job file are binding for this requirement
  (`dielectric_constraints: yes`).

**CAN differential pair (informative, no coupon required):** `CAN_P/CAN_N` and
`CAN_BUS_P/CAN_BUS_N` form a differential pair with a 120 ohm nominal bus
impedance. The on-board run is a short stub (< 20 mm) on a terminated bus, so
formal differential impedance control is **not** required; standard tolerances
apply. Do not reroute or thin these traces.

## 3. Conformal coating — REQUIRED

The assembled board **must receive a permanent polymer conformal coating** (acrylic
or equivalent, applied per IPC-CC-830). Electrical spacing in the 9–36 V input
section is designed to IPC-2221 Table 6-1 row **B4** (external conductors *with*
permanent polymer coating); the bare, uncoated board does **not** meet the B2
spacing row for 31–50 V and must not be put into service uncoated.

Mask (keep free of coating):

- J101 (power terminal block), J301 (CAN terminal block), J401 (battery connector)
- J201 U.FL RF connector
- J202 Tag-Connect programming footprint
- Test points TP101, TP102, TP103, TP401, TP402, TP403
- Mounting holes H1–H4 (grounding contact surfaces)

## 4. Assembly

- All components on the top side (F.Cu); single-sided reflow.
- Three fiducials (FM1–FM3); placement data in `CPL-files/`.
- Exposed-pad devices U101, U102, U201, U301: thermal-via-in-pad present; standard
  paste windowing per the supplied paste layer. X-ray or AOI inspection of the
  U301 (VQFN-20) exposed pad is requested on first articles (see project DFMEA
  item CAN-003).
- DNP parts (do not fit): C210, C211, C309, R302, R303 — see BOM.

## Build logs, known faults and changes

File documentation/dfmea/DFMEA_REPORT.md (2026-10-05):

# Automotive BLE-CAN Module — Design FMEA

**Document status:** Draft for design review
**Revision:** 1.0 (supersedes Rev 0.1, which covered the CAN interface only)
**Date:** 2026-09-30
**Designer:** Shivam Tiwari
**Scope:** Whole module — vehicle power input, battery backup, CAN interface, BLE
subsystem, RF, manufacturing, mechanical and firmware bring-up
**Register:** `DFMEA_REGISTER.csv` (38 items, sorted by descending RPN)
**Design under analysis:** `hardware/BLE-CAN-module.kicad_sch` /
`.kicad_pcb`, KiCad 10.0.6

## 1. Rating method

- **Severity (S):** 1 = negligible; 10 = hazardous or regulatory impact.
- **Occurrence (O):** 1 = remote; 10 = frequent.
- **Detection (D):** 1 = almost certain detection before release; 10 = unlikely
  to be detected before the field.
- **RPN = S × O × D.** RPN drives prioritisation but does **not** override a high
  severity: any item with S ≥ 8 is treated as release-relevant regardless of RPN.
- Target (residual) ratings are goals, valid only once the listed closure
  evidence is approved. Severity is never reduced by an action — only occurrence
  and detection are.

Ratings are preliminary and must be re-baselined against project's approved
DFMEA scoring matrix when one is adopted.

A note on occurrence scoring: items whose cause is *an unmeasured assumption*
(PWR-004, RF-001, RF-003) carry a deliberately high occurrence, because the
design has no evidence either way. Items where a datasheet-specified mitigation
is already implemented (BAT-004, CAN-004) carry a low occurrence.

## 2. Coverage of project failure modes

| Failure mode | Items |
| --- | --- |
| Input overvoltage | PWR-001 |
| Reverse battery | PWR-002 (vehicle), BAT-001 / MEC-001 (pack) |
| Regulator thermal stress | THM-001 (TCAN4550), THM-002 (U101/U102) |
| Battery leakage or improper charging | BAT-002, BAT-003, BAT-005 |
| CAN bus short / open | CAN-004 (short), CAN-005 (termination/open) |
| ESD damage | ESD-001 (bus), ESD-002 (handling/debug) |
| BLE range loss | RF-001, RF-002, RF-005 |
| Oscillator failure | CAN-002 (40 MHz), RF-003 (48 MHz), RF-004 (32.768 kHz) |
| Poor solderability | MFG-003, CAN-003, CAN-007 |
| Wrong connector insertion | MEC-001, MEC-002 |
| Firmware / debug bring-up | CAN-001, FW-001, FW-002, FW-003 |

Additional design-specific items not on that list: PWR-003 (crank boundary),
PWR-004 (electrolytic wear-out), PWR-005 (coating dependency), PWR-006 (parked
current), BAT-004 (ORing lockout corner), CAN-006 (VIO out of spec in backup),
CAN-008 (common-mode emissions), MEC-003 (vibration), MFG-001/002 (unreleased
BOM items), MFG-004 (DNP variant control).

**Distribution:** 38 items — PWR 6, CAN 8, BAT 5, RF 5, MFG 4, MEC 3, FW 3,
ESD 2, THM 2. Two are design-action-complete; 36 remain open.

## 3. Release gates

The design is **not** ready for production release until these close. Each is a
hard gate, not a recommendation.

### Blocks fabrication

- **CAN-007 (RPN 192)** — L301's land pattern is a generic ACM4532, not derived
  from the TDK ACT45B drawing. Pad geometry *and* terminal numbering must be
  confirmed. If ACT45B pairs its windings differently from the assumed 1–4 / 2–3,
  the schematic symbol variant must be swapped and the netlist re-verified.
- **MFG-001 (RPN 63, O = 9)** — X301 has no manufacturer part number. Low RPN,
  but the occurrence is 9 because the board simply cannot be built. Its frequency
  tolerance also gates CAN-002.
- **MFG-002 (RPN 96)** — eight further line items without MPNs, of which
  L202/C214/C216 are RF-critical.

### Blocks production schematic release

- **CAN-001 (RPN 224)** — nWKRQ drives an internal 3.6 V push-pull rail before
  firmware can reconfigure it. Firmware alone cannot protect the interval between
  power-up and configuration; a hardware isolating buffer is required.

### Blocks production build

- **PWR-005 (RPN 168)** — conformal coating is load-bearing, not cosmetic. The
  input section is designed to IPC-2221 row **B4** (coated). Uncoated, it fails
  row B2 in 118 places with a minimum spacing of 0.2005 mm against the 0.6 mm
  requirement. Coating must appear on the assembly drawing and purchase order.

### Close after EVT, before production freeze

- **CAN-002, RF-003, RF-004** — all three oscillators are running on assumed
  stray capacitance. None can be closed by review; each needs measurement on
  assembled hardware.

## 4. The items that most deserve scrutiny

### 4.1 CAN-001 — nWKRQ power-domain conflict (RPN 224, carried from Rev 0.1)

Not merely a firmware setting. At reset, before software can write to the
TCAN4550, nWKRQ drives from an internal 3.6 V source. The CC2340R53 input limit
follows its own VDDS rail. When the CAN device is powered while the MCU rail is
absent or low — precisely what happens in battery backup — the direct connection
can inject current into an MCU pin. R307's 100 kΩ pull-up does not isolate a
push-pull driver.

A buffer with a 5.5 V-tolerant input and `Ioff` / partial-power-down protection
breaks the path while preserving an MCU-domain output level. Firmware
configuration (register `0x0800` bit 19) remains necessary, but is then no longer
the *only* protection. This is the one item where the schematic, as drawn, has a
defect rather than an unverified assumption.

### 4.2 PWR-004 — the electrolytic is the service-life limit (RPN 210)

C101 is the only wet electrolytic on the board, and it sits on a rail that is
energised whenever the vehicle battery is connected. The Panasonic FK series is
rated 105 °C / 2000 h — roughly one year of continuous operation at high ambient.
Every other component on the board will outlive it by an order of magnitude.

The schematic note claims AEC-Q200; that claim was **not** confirmed against the
Panasonic datasheet during this review and is recorded as unverified in the BOM.
Note also that C101 is not decorative: it is the damping partner to R101, so
removing it in favour of ceramics requires the input filter damping to be
re-checked.

### 4.3 RF-001 — the match is not where the reference design puts it (RPN 168)

Measured from the layout: the U201 ANT pad is at x = 132.0 mm and the first
matching element at x = 138.29 mm. That is **6.29 mm** of line ahead of the
network. On this stackup at 2.44 GHz (ε_eff ≈ 3.2, λ_g ≈ 69 mm) it is about
**33° of electrical length**, enough to rotate the source impedance materially.

The values themselves (L202 2.8 nH, C214/C216 1.5 pF) are correct — they come
from TI's LP-EM-CC2340R53 reference. But on that reference the parts sit
immediately at the pin. Copying the values without copying the geometry does not
reproduce the match. Compounding it, RF-002 notes the feed is routed at 0.18 mm
(≈55.6 Ω) rather than the ~0.215 mm needed for 50 Ω.

This is the most likely single cause of disappointing BLE range on first
articles, and it is not detectable without a VNA.

### 4.4 BAT-004 — a corner that was designed out (RPN 64)

Included deliberately as an example of a risk that was closed at design time
rather than deferred. The LM66100-Q1 datasheet §9.2.2 documents that two
cross-coupled ORing devices will *both* switch off if their inputs sit at the
same voltage for an extended period — which would collapse `+3V3_SYS` entirely.

The rails are offset by 300 mV (3.3 V vehicle, 3.0 V battery) against an 80 mV
comparator window. Worst-case tolerance still leaves 174 mV. **This is the reason
U402 is a 3.0 V part and not a 3.3 V part** — a choice that looks arbitrary in
the BOM and is in fact the mitigation for this failure mode.

### 4.5 CAN-006 — an accepted out-of-specification condition (RPN 96)

In battery backup, TCAN4550 VIO sits at ~3.0 V against a recommended minimum of
3.135 V. It is above the 2.45–2.6 V UVIO threshold, so the device does not fault
— it simply operates outside its recommended window.

This is accepted rather than fixed, because the alternative is worse: powering
VIO from the vehicle rail alone would create a powered-MCU / unpowered-VIO
partial-power-down condition on the SPI pins, which is the same mechanism as
CAN-001. The mitigation is behavioural — firmware must not drive SPI in backup —
and it depends on BAT-005 being closed first so firmware can *tell* it is in
backup.

## 5. Unresolved risks and stated assumptions

Where something could not be closed,
what was assumed is stated.

| # | Open question | What was assumed |
| --- | --- | --- |
| 1 | No vehicle transient specification was supplied | ISO 7637-2 / ISO 16750-2 applicability assumed but **not tested**. D101's 40 V standoff has only 4 V margin over 36 V; its 64.5 V clamp is within the buck's 80 V rating, which is the whole basis for believing the chain survives (PWR-001). |
| 2 | No network topology was supplied | The module is assumed a **stub node**, so R302/R303/C309 are DNP (CAN-005). |
| 3 | No ambient temperature requirement was supplied | 85 °C assumed for thermal work. TCAN4550 Tj ≈ 101 °C at that ambient, by calculation only (THM-001). |
| 4 | No parked-current budget was supplied | ~100–150 µA estimated from datasheet figures, never measured (PWR-006). |
| 5 | Conformal coating is not contractually confirmed | Assumed present; the input-section spacing is only compliant under IPC-2221 B4 (PWR-005). |
| 6 | TDK ACT45B land pattern not obtained | Generic ACM4532 pattern used; winding pairing assumed 1–4 / 2–3 (CAN-007). |
| 7 | PCB stray capacitance never measured | ~1.5 pF assumed at the LSE, ~3 pF at the CAN crystal; the 48 MHz HFXT relies entirely on the MCU internal array with 11.07/7.63 mm asymmetric traces (CAN-002, RF-003, RF-004). |
| 8 | C101 AEC-Q200 status unconfirmed | Schematic claim recorded as unverified; the 2000 h endurance concern stands regardless (PWR-004). |
| 9 | No antenna or enclosure defined | U.FL port only; radiated performance cannot be predicted (RF-005). |
| 10 | Battery pack PCM parameters unspecified | A protected 1S pack is assumed to be always fitted; the board provides no charging and no monitoring (BAT-002). |
| 11 | D102 ratings taken from a schematic note | 200 V / 1 A assumed; IF(AV) and VF at ~90 mA not independently confirmed. |
| 12 | Via-in-pad treatment unspecified | Tenting requested, plugging/filling not specified — a solder-wicking risk on four exposed-pad devices (MFG-003). |

## 6. What changed since Rev 0.1

Rev 0.1 contained three items, all CAN. They are carried forward unchanged in
substance:

- **CAN-003** — TCAN4550 land pattern correction. Design action complete against
  TI drawing 4225320/A; first-article verification still open.
- **CAN-001** — nWKRQ power sequencing. Still open, still blocking.
- **CAN-002** — 40 MHz oscillator characterisation. Still open; now additionally
  notes the asymmetric crystal routing (8.78 mm vs 3.23 mm) as a contributing
  cause, and is explicitly coupled to MFG-001 since the crystal is unselected.

Thirty-five items were added covering power, battery, RF, thermal, ESD,
mechanical, manufacturing and firmware. Two mitigations were **implemented during
this review** and are reflected in the register: D301 was relocated adjacent to
J301 (ESD-001), and L301 was added and placed between the transceiver and the
TVS (CAN-008).

## 7. References

- [TI TCAN4550-Q1 datasheet](https://www.ti.com/lit/ds/symlink/tcan4550-q1.pdf)
- [TI TCAN455x Clock Optimization and Design Guidelines, SLLA549](https://www.ti.com/lit/an/slla549/slla549.pdf)
- [TI SN74LVC1G17-Q1](https://www.ti.com/product/SN74LVC1G17-Q1)
- [TI CC2340R5 datasheet](https://www.ti.com/lit/ds/symlink/cc2340r5.pdf)
- [TI LMR38010-Q1 datasheet](https://www.ti.com/lit/ds/symlink/lmr38010-q1.pdf)
- [TI LM66100-Q1 datasheet](https://www.ti.com/lit/ds/symlink/lm66100-q1.pdf)
- [TI RGY0020A land-pattern drawing 4225320/A](https://www.ti.com/lit/pdf/qfnd041)
- IPC-2221B Table 6-1 (conductor spacing); IPC-A-610 class 2 (void criteria)
- Project: `documentation/architecture/ARCHITECTURE.md`,
  `hardware/Manufacturing_Output_Files/BOM/BOM_NOTES.md`, `hardware/Manufacturing_Output_Files/FAB_NOTES.md`

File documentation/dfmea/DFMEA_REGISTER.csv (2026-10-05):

ID | Design function | Potential failure mode | Potential effect | Cause or mechanism | Current controls | Initial S | Initial O | Initial D | Initial RPN | Recommended action | Closure evidence | Target S | Target O | Target D | Target RPN | Owner | Status
CAN-003 | Manufacturable TCAN4550 RGY0020A land pattern | Incorrect perimeter-pad centers cause solder bridging or opens | Low yield or nonfunctional CAN controller | Prior custom footprint interpreted pad-center dimensions incorrectly | Corrected pad and stencil centers against TI 4225320/A; copies hash-match | 8 | 7 | 6 | 336 | Independent overlay review; PCB DRC; first-article AOI/X-ray inspection | Accepted footprint overlay; clean DRC; accepted first-article solder inspection | 8 | 1 | 2 | 16 | Hardware and Manufacturing | DESIGN ACTION COMPLETE - verification open
CAN-001 | Safe MCU wake across CAN and MCU power domains | nWKRQ default 3.6 V reaches MCU while MCU VDDS is low or absent | Absolute-maximum violation; back-powering; excess sleep current; latch-up or damage; false or missed wake | Mixed power domains; default internal 3.6 V output exists before SPI configuration; direct connection and R307 100k pull-up lack power-off isolation | Schematic warning; firmware bit 19 requirement; datasheet review | 8 | 4 | 7 | 224 | Add automotive over-voltage-tolerant buffer with Ioff/partial-power-down protection (for example SN74LVC1G17-Q1); define TCAN-off state; remove or reassign raw pull-up; configure and read back bits 19 and 8 | Approved schematic and ERC; all VSUP/VIO/reset/sleep sequences tested; MCU pin within limits; no back-power current | 8 | 1 | 2 | 16 | Hardware and Firmware | OPEN - blocks production schematic release
PWR-004 | Maintain input filter damping across service life | C101 ESR rise and capacitance loss; eventual open circuit | Under-damped input filter; buck instability; raised conducted emissions; loss of hot-plug surge absorption | Panasonic EEEFK2A220P is an FK-series 105 degC / 2000 h wet electrolytic on an always-on rail - roughly one year continuous at high ambient. It is the only wet electrolytic on the board and its AEC-Q200 status is claimed in the schematic note but NOT confirmed against the datasheet | R101 1 ohm series damping partner; 100 V part on a 36 V maximum rail gives large voltage derating | 6 | 5 | 7 | 210 | Confirm AEC-Q200 status from the Panasonic datasheet; compute required life at the target ambient; if 2000 h is insufficient move to an automotive hybrid-polymer part or an all-ceramic bank - and re-check input filter damping if the electrolytic is removed | Life calculation at target ambient plus the selected part datasheet and a damping re-check | 6 | 2 | 3 | 36 | Hardware | OPEN - stated assumption
CAN-002 | Stable 40 MHz reference clock | Crystal fails to start or stop; excessive drive/amplitude; excessive frequency error | No or intermittent CAN; CAN-FD bit errors; temperature-dependent field failure; reduced crystal life | Unmeasured PCB stray capacitance and loop margin; R311 0 ohm is provisional; component and layout variation; CAN_XTAL2 trace is 8.78 mm against CAN_XTAL1 at 3.23 mm so the loop is asymmetric | 40 MHz CL8 crystal; C303/C304 10 pF C0G; R311 tuning footprint at OSC1; TI SLLA549 note | 8 | 4 | 6 | 192 | Characterize EVT hardware across voltage and temperature; tune R311/C303/C304; confirm frequency and drive level against the exact ordered crystal limit | Signed oscillator test report with equipment/probe loading/board revision/sample count/corners/final BOM values | 8 | 2 | 2 | 32 | Hardware Validation | OPEN - close after EVT before production fabrication
CAN-007 | Manufacturable CAN common-mode choke | L301 land pattern or terminal numbering does not match the specified TDK ACT45B | Open or swapped windings - CAN non-functional or with no common-mode filtering; scrapped first article | L301 is assigned the generic Inductor_SMD:L_CommonModeChoke_Coilank_ACM4532 pattern (4.5 x 3.2 mm) rather than a pattern derived from the TDK drawing. Symbol variant _1423 was selected so windings pair 1-4 and 2-3 to match that footprint layout (pads 1 and 2 one side; 3 and 4 the other) | Requirement recorded in the component Purpose field; BOM open item OA-2; ARCHITECTURE.md note. Netlist verified as CAN_P to pin 1; CAN_BUS_P to pin 4; CAN_N to pin 2; CAN_BUS_N to pin 3 | 8 | 6 | 4 | 192 | Obtain the TDK ACT45B land-pattern drawing; verify pad geometry AND terminal numbering; if ACT45B pairs its windings differently swap the symbol variant and re-verify the netlist; independent overlay review before release | Footprint overlay against the manufacturer drawing plus a winding continuity check on the first article | 8 | 1 | 2 | 16 | Hardware and Manufacturing | OPEN - blocks fabrication release
MEC-003 | Maintain connections under vehicle vibration | J101 or J301 screw terminals loosen; J401 or J201 unmate | Intermittent power or CAN or total loss of function; intermittent faults are very hard to diagnose in the field | None of the four external connectors has a vibration rating. Phoenix MPT screw terminals rely on screw torque alone; JST PH uses friction retention; U.FL has no lock and is rated for roughly 30 mating cycles | Four M2 mounting holes H1-H4 with grounded pads secure the board itself to the enclosure | 7 | 5 | 5 | 175 | Replace all external connectors with sealed locking automotive types for production (alternatives listed in the BOM); specify screw torque and thread-locking for any prototype field trial; consider a U.FL retainer or a soldered antenna pigtail | Production connector selection record plus vibration testing to the target ISO 16750-3 profile | 7 | 2 | 3 | 42 | Hardware and Mechanical | OPEN - prototype-grade by explicit design decision
MFG-003 | Reliable exposed-pad solder and thermal joint | Voiding; insufficient solder; solder wicking into thermal vias under U101 U102 U201 U301 | Degraded heat sinking which raises the THM-001 risk; unstable ground reference; intermittent or nonfunctional devices | Four exposed-pad packages carry thermal via-in-pad arrays (U101 10 vias; U201 10; U102 6; U301 6). Vias in pad wick solder unless plugged and capped. Tenting is requested on both faces but via plugging or filling is NOT specified in the fabrication notes | Paste apertures defined in the supplied stencil layers; CAN-003 already corrected the U301 land pattern against TI drawing 4225320/A | 7 | 5 | 5 | 175 | Decide and specify via-in-pad treatment (plugged and capped versus tented only) in FAB_NOTES.md; agree stencil aperture design with the assembler; X-ray first articles against IPC-A-610 class 2 void limits | X-ray images of all four devices on the first article plus an agreed stencil drawing | 7 | 2 | 2 | 28 | Manufacturing | OPEN
ESD-002 | Survive handling ESD during assembly programming and service | ESD damage at J202 J201 J401 or the bare test points | Latent or immediate MCU or RF damage; field failures with no clear root cause | J202 Tag-Connect exposes SWDIO SWDCK and RESET directly to MCU pins with no series protection; J201 U.FL connects to the RF port through the matching network; TP101-TP103 and TP401-TP403 are bare pads. Only the CC2340R53 device-level pin ESD rating protects these nodes | No specific circuit protection - relies on device ESD ratings and factory ESD control | 6 | 4 | 7 | 168 | Require ESD-controlled handling in the assembly and service work instructions; if field programming is expected add series resistors or a low-capacitance ESD array on the SWD lines | ESD handling procedure in the released work instruction plus a decision record on SWD protection | 6 | 2 | 4 | 48 | Hardware and Manufacturing | OPEN
PWR-005 | Maintain creepage and clearance on the 9-36 V input section | Board is built or field-serviced without conformal coating | Dendrite growth or arcing between the VIN nets and GND under humidity and contamination; field short across the vehicle supply | All netclasses use 0.2 mm clearance including the 9-36 V nets. A DRC run against an IPC-2221 Table 6-1 row B2 rule (external uncoated 31-50 V requires 0.6 mm) returned 118 clearance violations with a minimum actual spacing of 0.2005 mm. The design is compliant only under row B4 (external with permanent polymer coating requires 0.13 mm) | Coating declared MANDATORY in hardware/Manufacturing_Output_Files/FAB_NOTES.md with a masking list; recorded in ARCHITECTURE.md assumptions | 7 | 4 | 6 | 168 | Make conformal coating a line item on the assembly drawing and the purchase order rather than only a note; add an incoming-inspection check; consider widening the local pour clearance around J101 and F101 to 0.6 mm so the uncoated case is also safe | Assembly drawing revision and a signed process sheet showing coating and masking | 7 | 1 | 2 | 14 | Hardware and Manufacturing | OPEN
RF-001 | Deliver rated BLE output power and receive sensitivity | Antenna matching network does not present the intended impedance to the MCU RF port | Reduced TX power and RX sensitivity - direct BLE range loss; possible variance against regulatory power limits | Measured from the layout: the U201 ANT pad sits at x = 132.0 mm and the first matching element C214/L202 at x = 138.29 mm so 6.29 mm of line precedes the match. At 2.44 GHz on this stackup (eeff about 3.2; guided wavelength about 69 mm) that is roughly 33 degrees of electrical length which rotates the source impedance. L202 2.8 nH and C214/C216 1.5 pF were taken from the TI LP-EM-CC2340R53 reference where those parts sit immediately at the pin | Values are datasheet-derived; TDK DLF162500LT low-pass filter follows the match; continuous In1 ground reference at 0.11 mm | 6 | 7 | 4 | 168 | Either relocate the matching network adjacent to the ANT pad or re-tune L202/C214/C216 on a VNA for the as-built geometry including the LPF and U.FL; measure conducted TX power and sensitivity; add DNP tuning placeholders for future adjustment | VNA S11 plot at the U.FL port plus conducted power and sensitivity measurements | 6 | 2 | 2 | 24 | Hardware and RF | OPEN - highest-confidence RF risk
RF-005 | Radiate at the intended pattern and efficiency | Antenna detuning or blockage by the enclosure metal or mounting position | Severe BLE range loss in the installed position regardless of board-level RF performance | The design terminates at a U.FL port. No antenna part is selected and no enclosure or mounting position is defined. Metal proximity cable routing and ground-plane coupling all remain open | U.FL allows the antenna to be positioned away from the board; board ground is continuous across In1 and B.Cu | 6 | 5 | 5 | 150 | Select the antenna and pigtail; define mounting position and keepout relative to metal; measure total radiated power and efficiency in the final enclosure | Radiated performance measurement in the intended installation | 6 | 2 | 3 | 36 | Hardware and RF | OPEN - antenna and enclosure selection required before production
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

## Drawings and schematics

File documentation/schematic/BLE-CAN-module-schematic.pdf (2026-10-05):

1 | 2 | 3 | 4 | 5 | 6

AB

C

D

AB

C

## D Date: 2026-09-30

Size: A4 | Rev: A
KiCad E.D.A. 10.0.6 | Id: 1/5

# Title: Automotive BLE-CAN Module

## File: BLE-CAN-module.kicad_sch

## Sheet: /

## SHIVAM TIWARI

## Automotive BLE-CAN Module

## CC2340R53 BLE | TCAN4550-Q1 CAN FD | 9-36 V input | 1S Li-ion backup

4-layer FR4, 1.58 mm, 49.5 x 56.9 mm | single-sided assembly

## Design period: 2026-09-24 to 2026-09-30 | Rev A

01_POWER_INPUT File: 01_POWER_INPUT.kicad_sch | 02_MCU_BLE_Controller File: MCU_BLE_Controller.kicad_sch 04_Power_Back-up
File: 04_Power_Back-up.kicad_sch | 03_CAN_Interface

## File: 03_CAN_Interface.kicad_sch

FM1 | FM3 H4 | FM2 H1 | H2 | H3 POWER INPUT 9-36 V Conversion to 6V5 and +3V3 Vehicle CAN bus to Bluetooth LE bridge | | 9-36 V input | 1S Li-ion backup

# AUTOMOTIVE BLE-CAN MODULE

Automotive BLE-CAN Module | | | Rev A | | | September 2026

SHEET INDEX
01 | POWER INPUT | 9-36 V protection, 6.49 V buck, 3.3 V LDO
02 | BLE CONTROLLER | CC2340R53, clocks, RF front-end, SWD
03 | CAN INTERFACE | TCAN4550-Q1, CMC, TVS, split termination 04 | BATTERY BACKUP | 1S pack input, 3.0 V LDO, ideal-diode ORing BLE CONTROLLER 2.4 GHz CC2340R53, clocks, RF front-end, SWD
KEY DEVICES U201 CC2340R53E0RKPR | BLE 5.x MCU, 512 KB flash, QFN-40 U301 TCAN4550RGYRQ1 | CAN FD controller + transceiver, SPI U101 LMR38010SQDDARQ1 80 V buck, PFM, spread spectrum

### U102 TPS7B8133QDGNRQ1 40 V LDO, 2.7 uA Iq U402 TPS7E8130QDBVRQ1 40 V LDO, 2.8 uA Iq

### U401/3/4 LM66100QDCKRQ1 ideal diode / reverse-current block

L301 ACT45B-101-2P | CAN common-mode choke Mounting Holes (M2) | CAN INTERFACE CAN FD TCAN4550-Q1, choke, TVS, termination
Fiducial Markers | POWER TREE J101 9-36 V -> F101 -> D101 TVS / D102 reverse -> R101 damping -> U101 LMR38010-Q1 buck ........ +6V5_CAN (TCAN4550 VSUP) -> U102 TPS7B8133-Q1 LDO ... +3V3_VEH

J401 1S pack -> F401 -> U401 RCB -> U402 TPS7E8130-Q1 ... +3V0_BAT U403 / U404 LM66100-Q1 ideal-diode OR .... +3V3_SYS (MCU + VIO) Vehicle rail has priority by the 3.3 V / 3.0 V offset; battery takes over automatically on vehicle loss. CAN is unavailable in backup. BATTERY BACKUP 1S Li-ion 3.0 V rail, ideal-diode ORing BOARD / PROCESS

### 4-layer FR4, 1.58 mm: F.Cu signal / In1 GND / In2 power / B.Cu GND

49.5 x 56.9 mm, single-sided assembly, HAL lead-free Conformal coating REQUIRED - input spacing designed to IPC-2221 B4 RF feed is 50 ohm controlled impedance - see Output_Files/FAB_NOTES.md

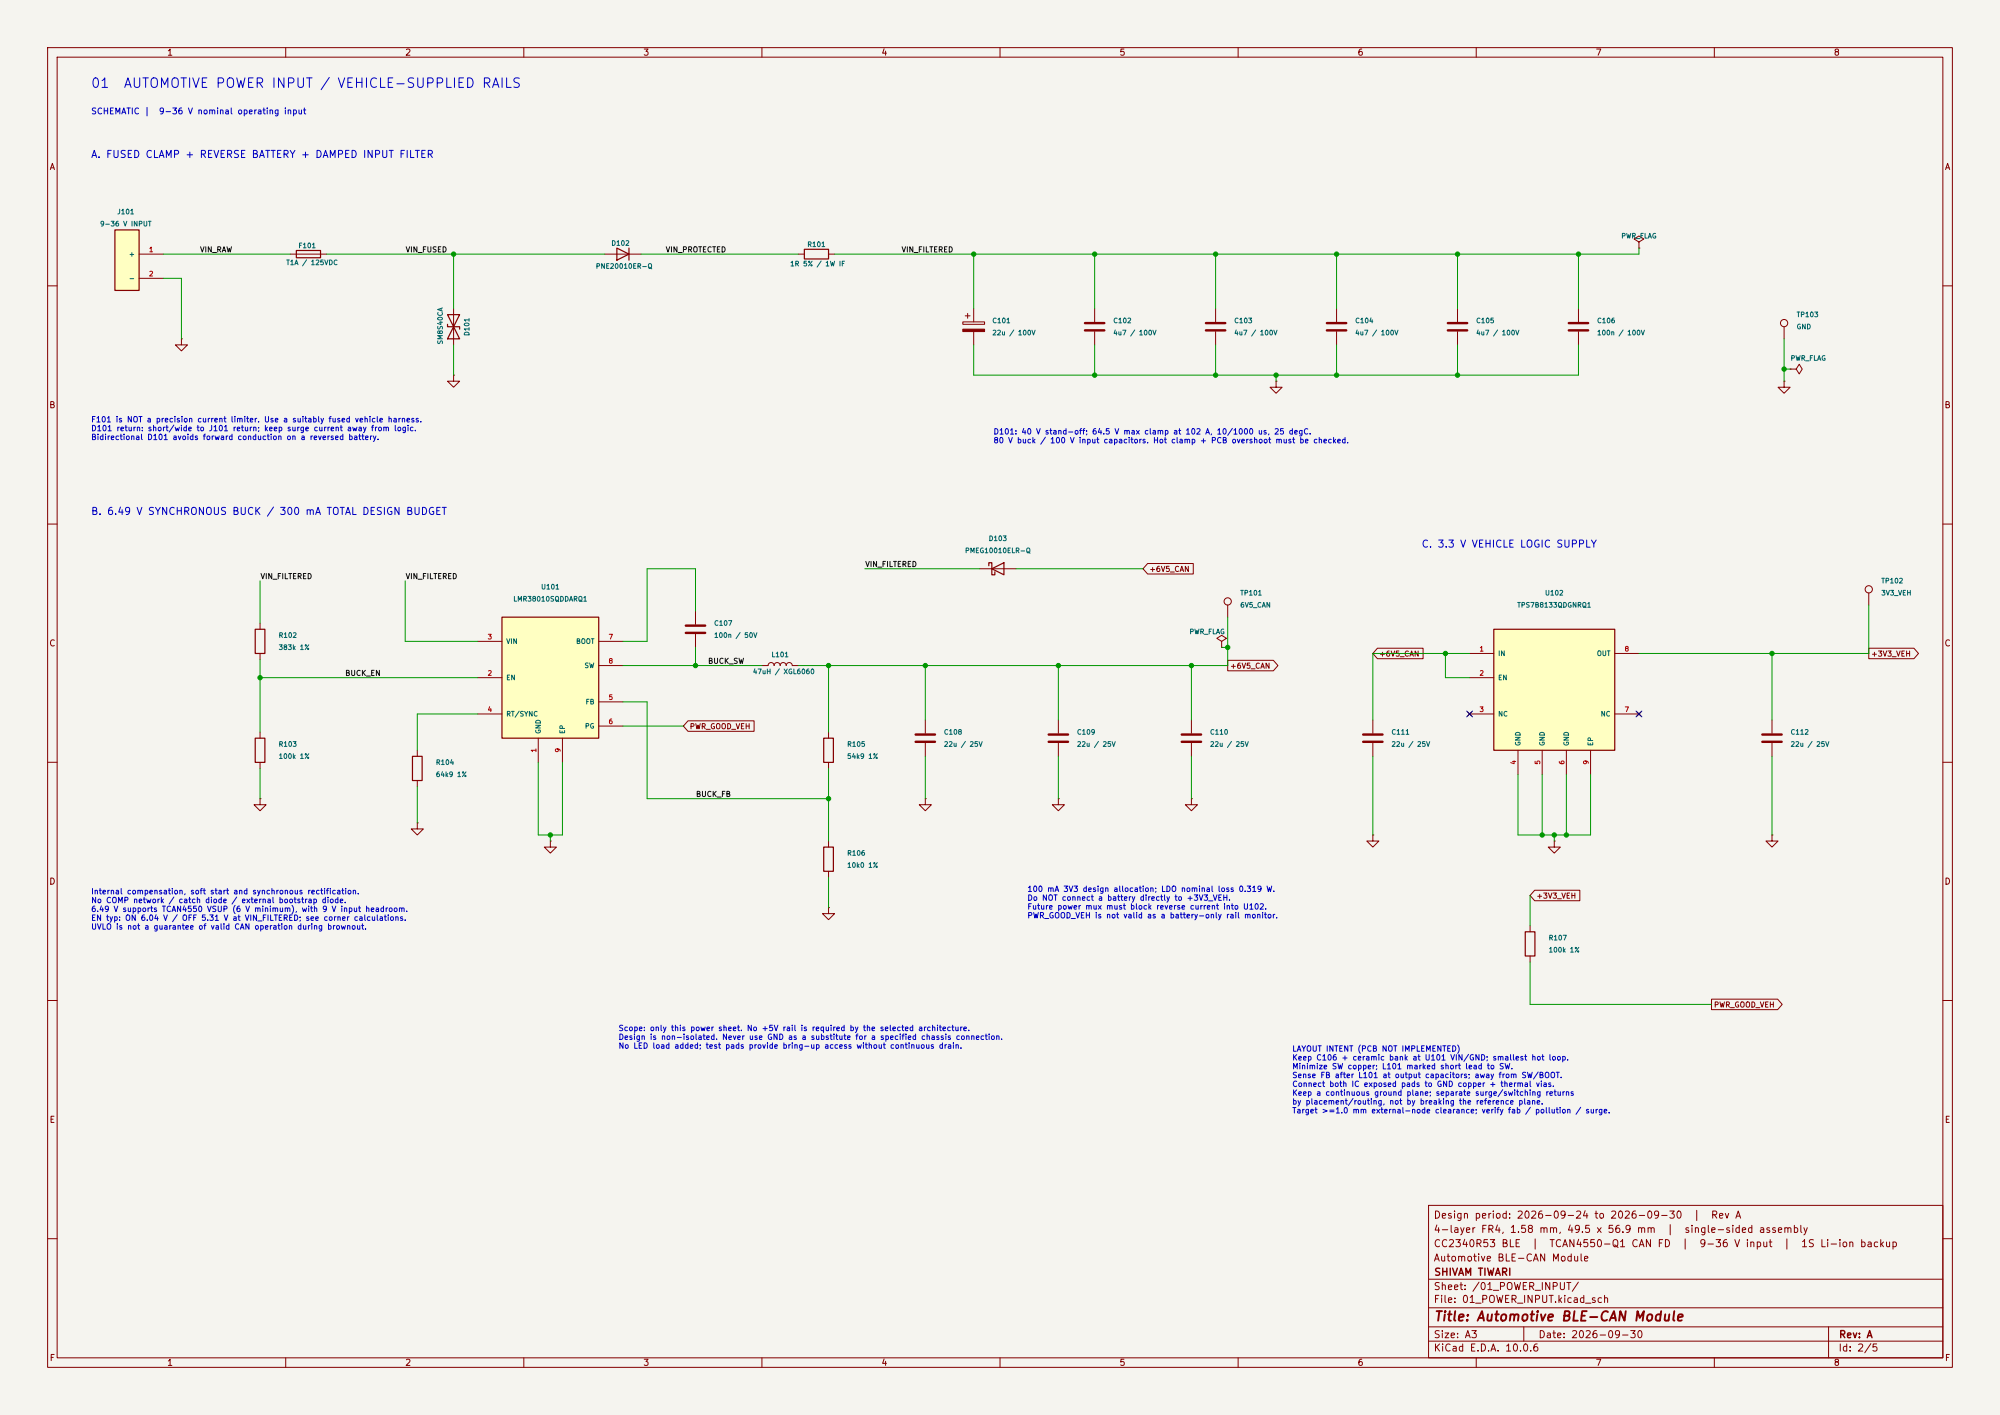
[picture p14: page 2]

01 AUTOMOTIVE POWER INPUT / VEHICLE-SUPPLIED RAILS

D101: 40 V stand-off; 64.5 V max clamp at 102 A, 10/1000 us, 25 degC. 80 V buck / 100 V input capacitors. Hot clamp + PCB overshoot must be checked. SCHEMATIC | 9-36 V nominal operating input

A. FUSED CLAMP + REVERSE BATTERY + DAMPED INPUT FILTER

B. 6.49 V SYNCHRONOUS BUCK / 300 mA TOTAL DESIGN BUDGET

Internal compensation, soft start and synchronous rectification. No COMP network / catch diode / external bootstrap diode. 6.49 V supports TCAN4550 VSUP (6 V minimum), with 9 V input headroom. EN typ: ON 6.04 V / OFF 5.31 V at VIN_FILTERED; see corner calculations. UVLO is not a guarantee of valid CAN operation during brownout.

Keep C106 + ceramic bank at U101 VIN/GND; smallest hot loop. Minimize SW copper; L101 marked short lead to SW. Sense FB after L101 at output capacitors; away from SW/BOOT. Connect both IC exposed pads to GND copper + thermal vias. Keep a continuous ground plane; separate surge/switching returns by placement/routing, not by breaking the reference plane.

Target >=1.0 mm external-node clearance; verify fab / pollution / surge.

Design period: 2026-09-24 to 2026-09-30 | Rev A
CC2340R53 BLE | TCAN4550-Q1 CAN FD | 9-36 V input | 1S Li-ion backup
Automotive BLE-CAN Module
SHIVAM TIWARI
Sheet: /01_POWER_INPUT/
File: 01_POWER_INPUT.kicad_sch
Title: Automotive BLE-CAN Module

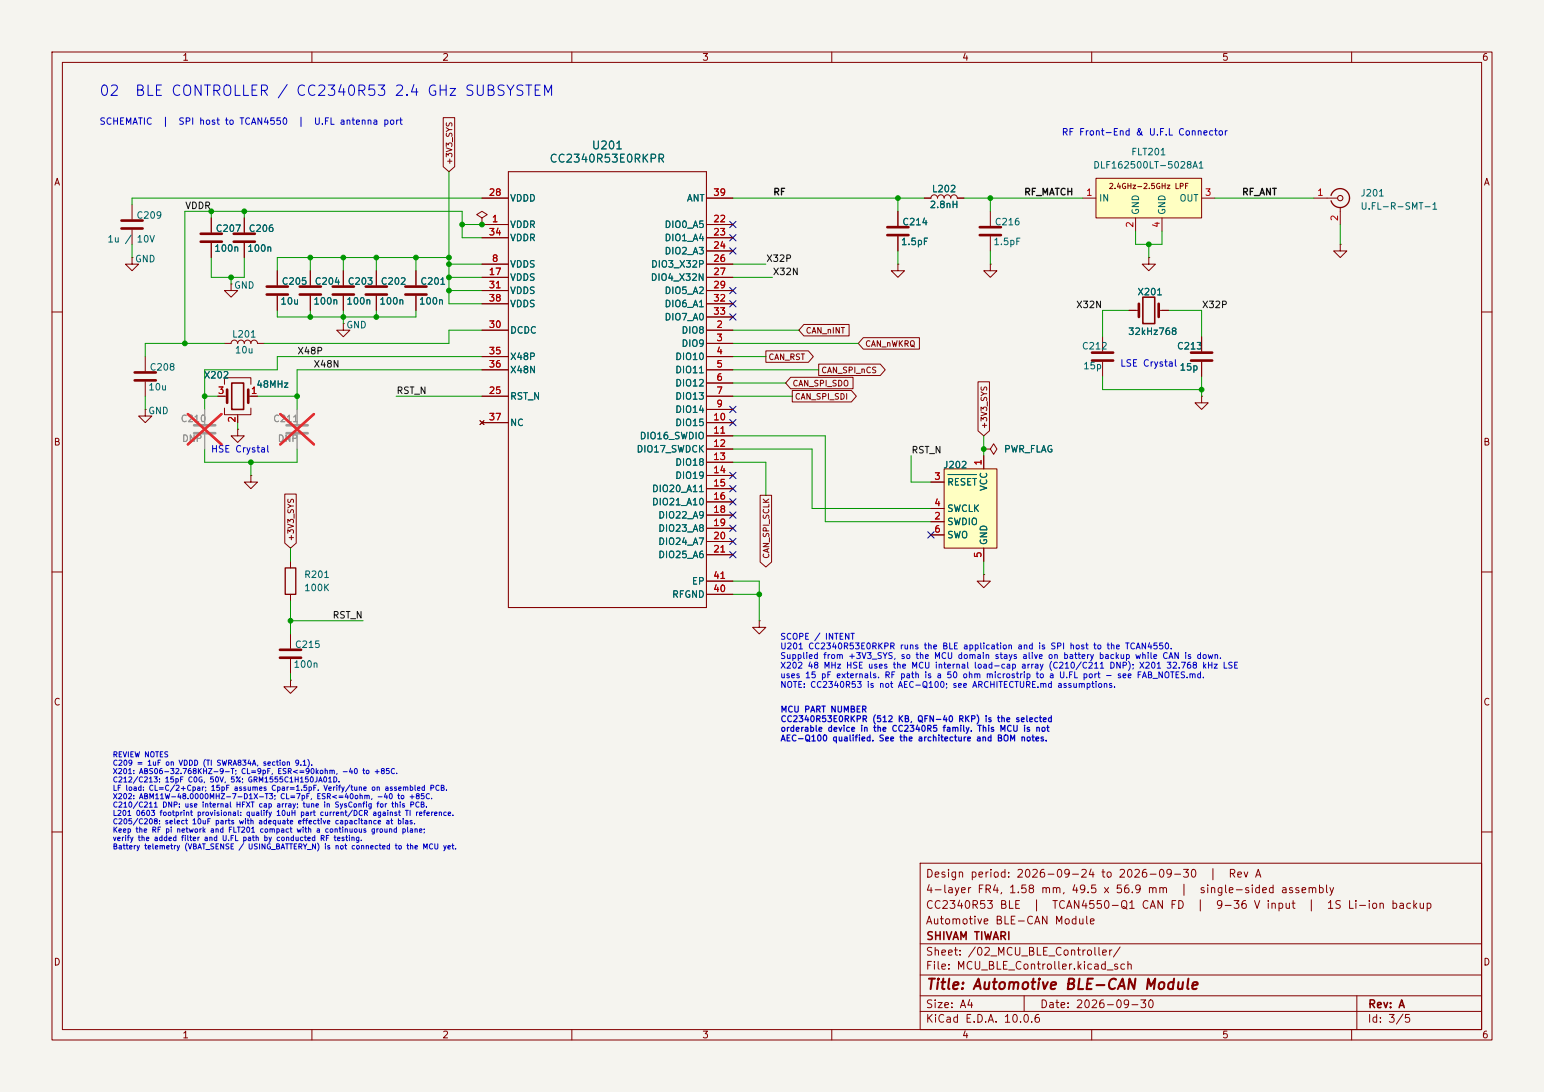
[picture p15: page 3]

orderable device in the CC2340R5 family. This MCU is not AEC-Q100 qualified. See the architecture and BOM notes. SCOPE / INTENT U201 CC2340R53E0RKPR runs the BLE application and is SPI host to the TCAN4550. Supplied from +3V3_SYS, so the MCU domain stays alive on battery backup while CAN is down. X202 48 MHz HSE uses the MCU internal load-cap array (C210/C211 DNP); X201 32.768 kHz LSE

CC2340R53E0RKPR (512 KB, QFN-40 RKP) is the selected
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

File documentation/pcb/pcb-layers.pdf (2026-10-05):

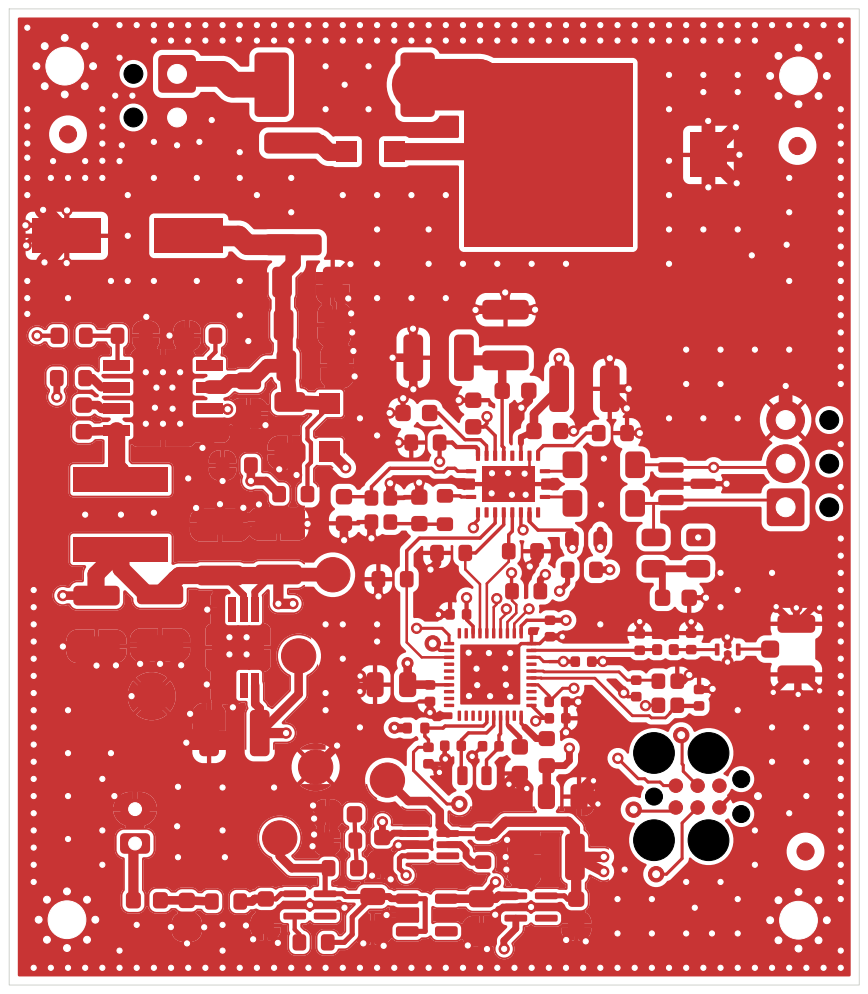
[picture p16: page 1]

4-layer FR4, 1.58 mm, 49.5 x 56.9 mm | single-sided assembly
CC2340R53 BLE | TCAN4550-Q1 CAN FD | 9-36 V input | 1S Li-ion backup
Bytebeam Hardware Design Assignment - Hardware Design Engineer
SHIVAM TIWARI
Sheet:
File: Bytebeam-BLE-CAN-module.kicad_pcb
Title: Automotive BLE-CAN Module

Size: A4 | Rev: A
KiCad E.D.A. 10.0.6 | Id: 1/7

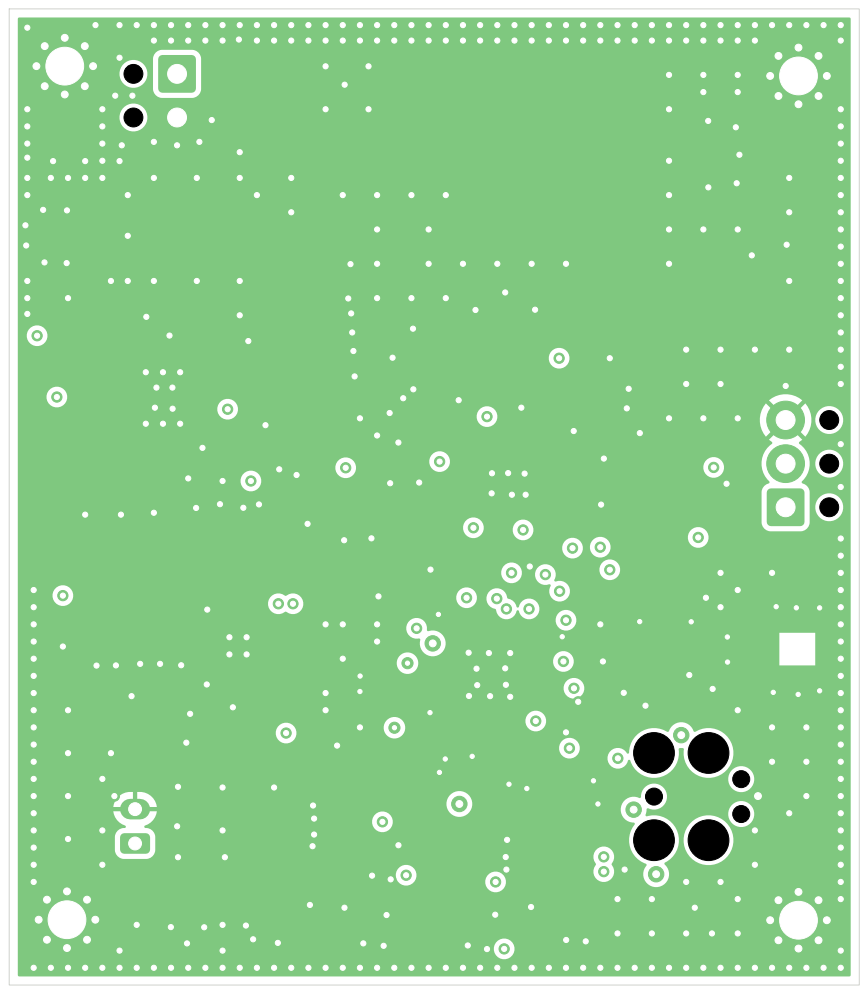
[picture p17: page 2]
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

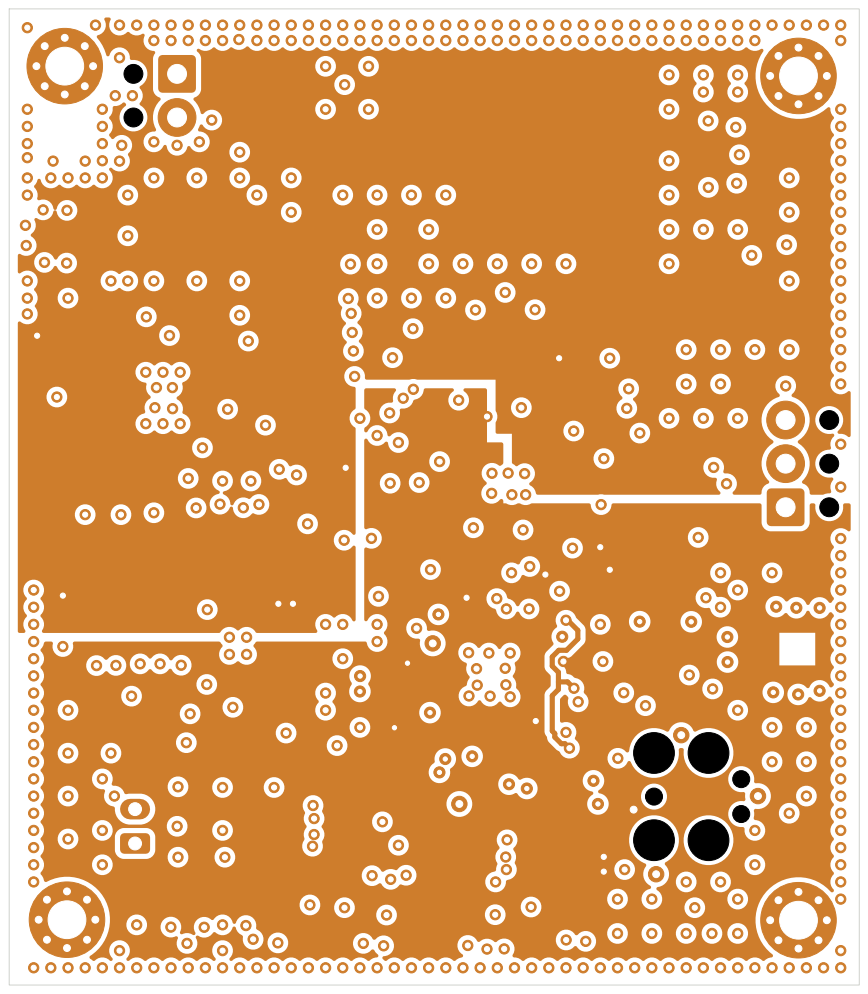
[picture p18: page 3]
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

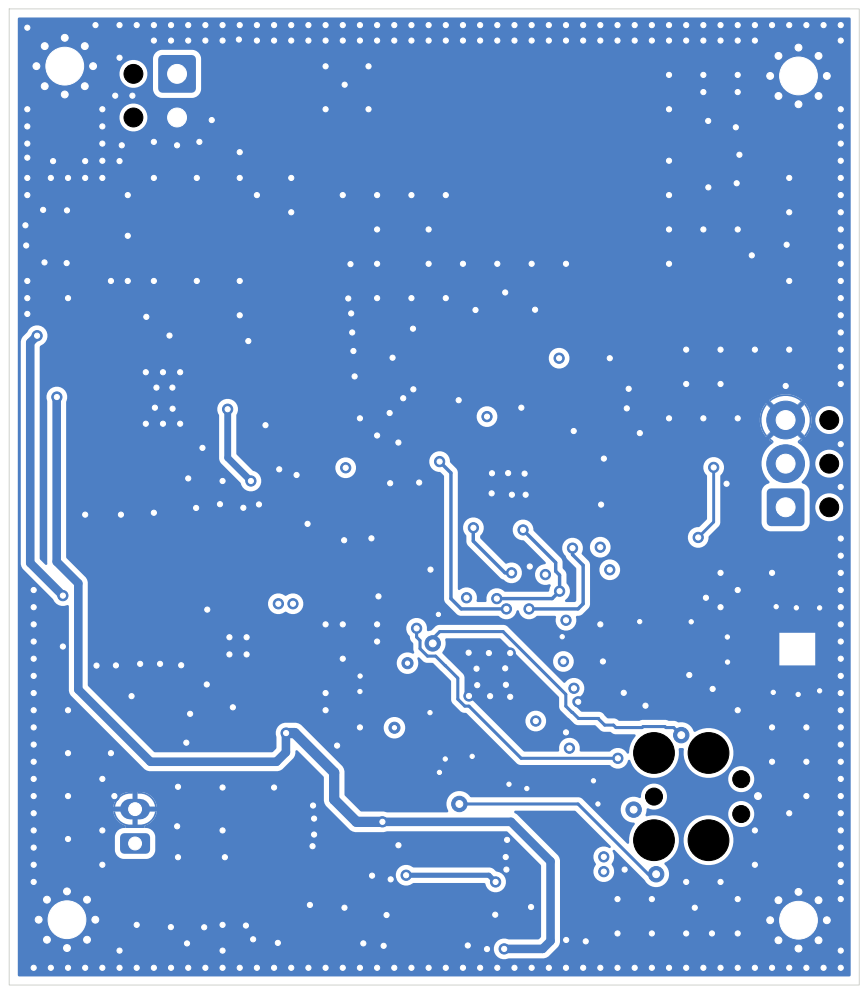
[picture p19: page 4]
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

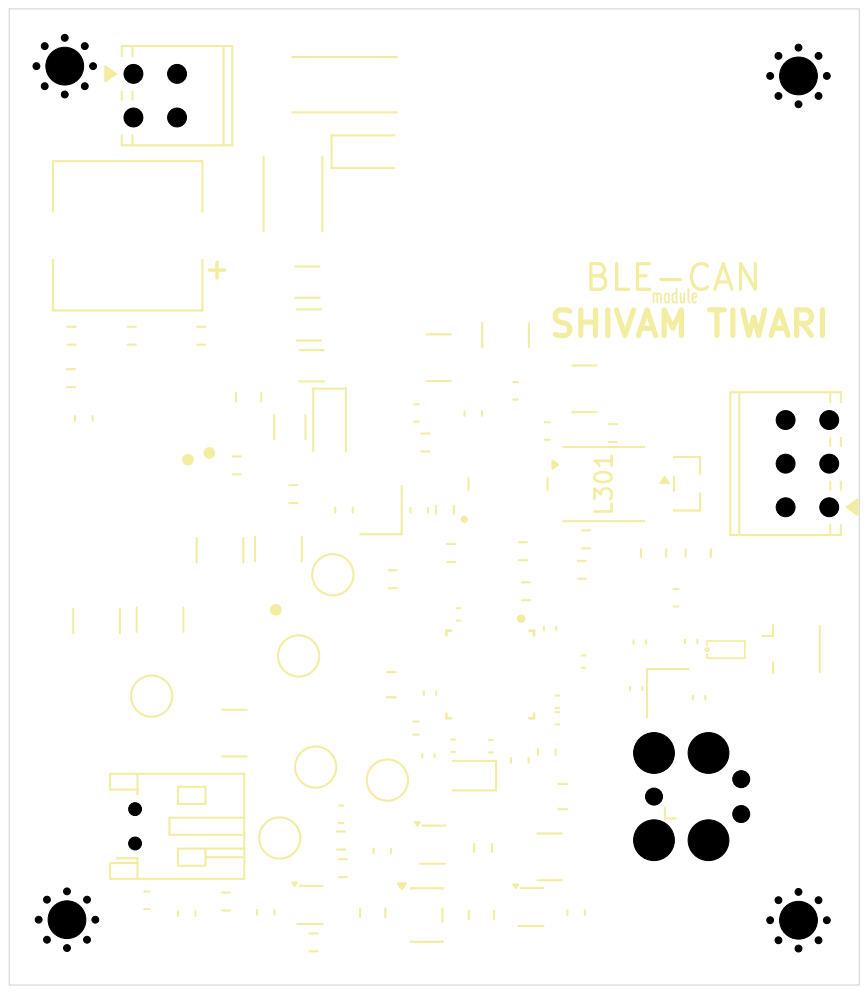
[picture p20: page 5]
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

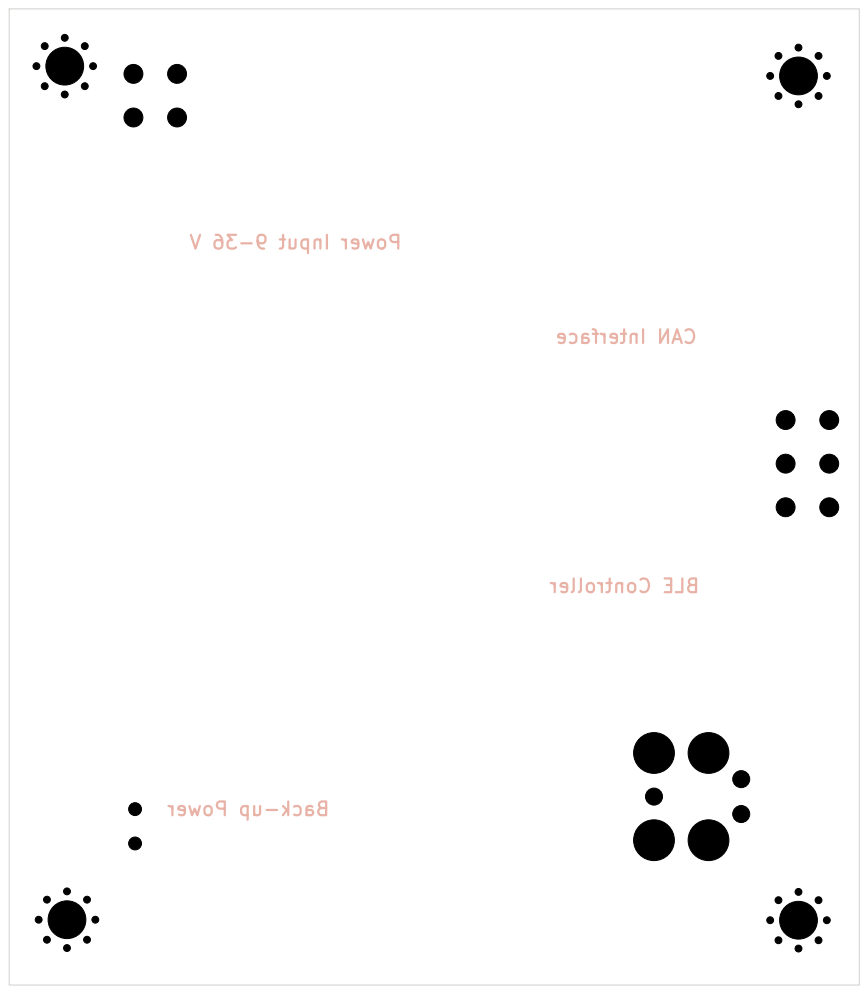
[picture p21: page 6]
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

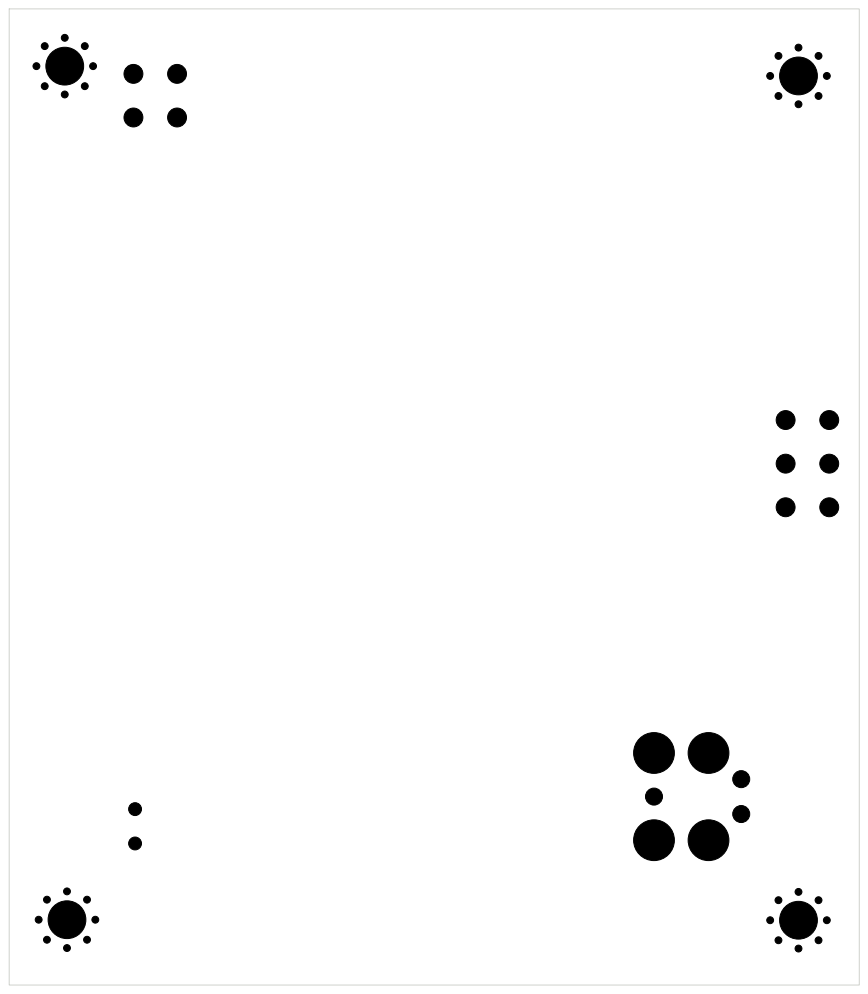
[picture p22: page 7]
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

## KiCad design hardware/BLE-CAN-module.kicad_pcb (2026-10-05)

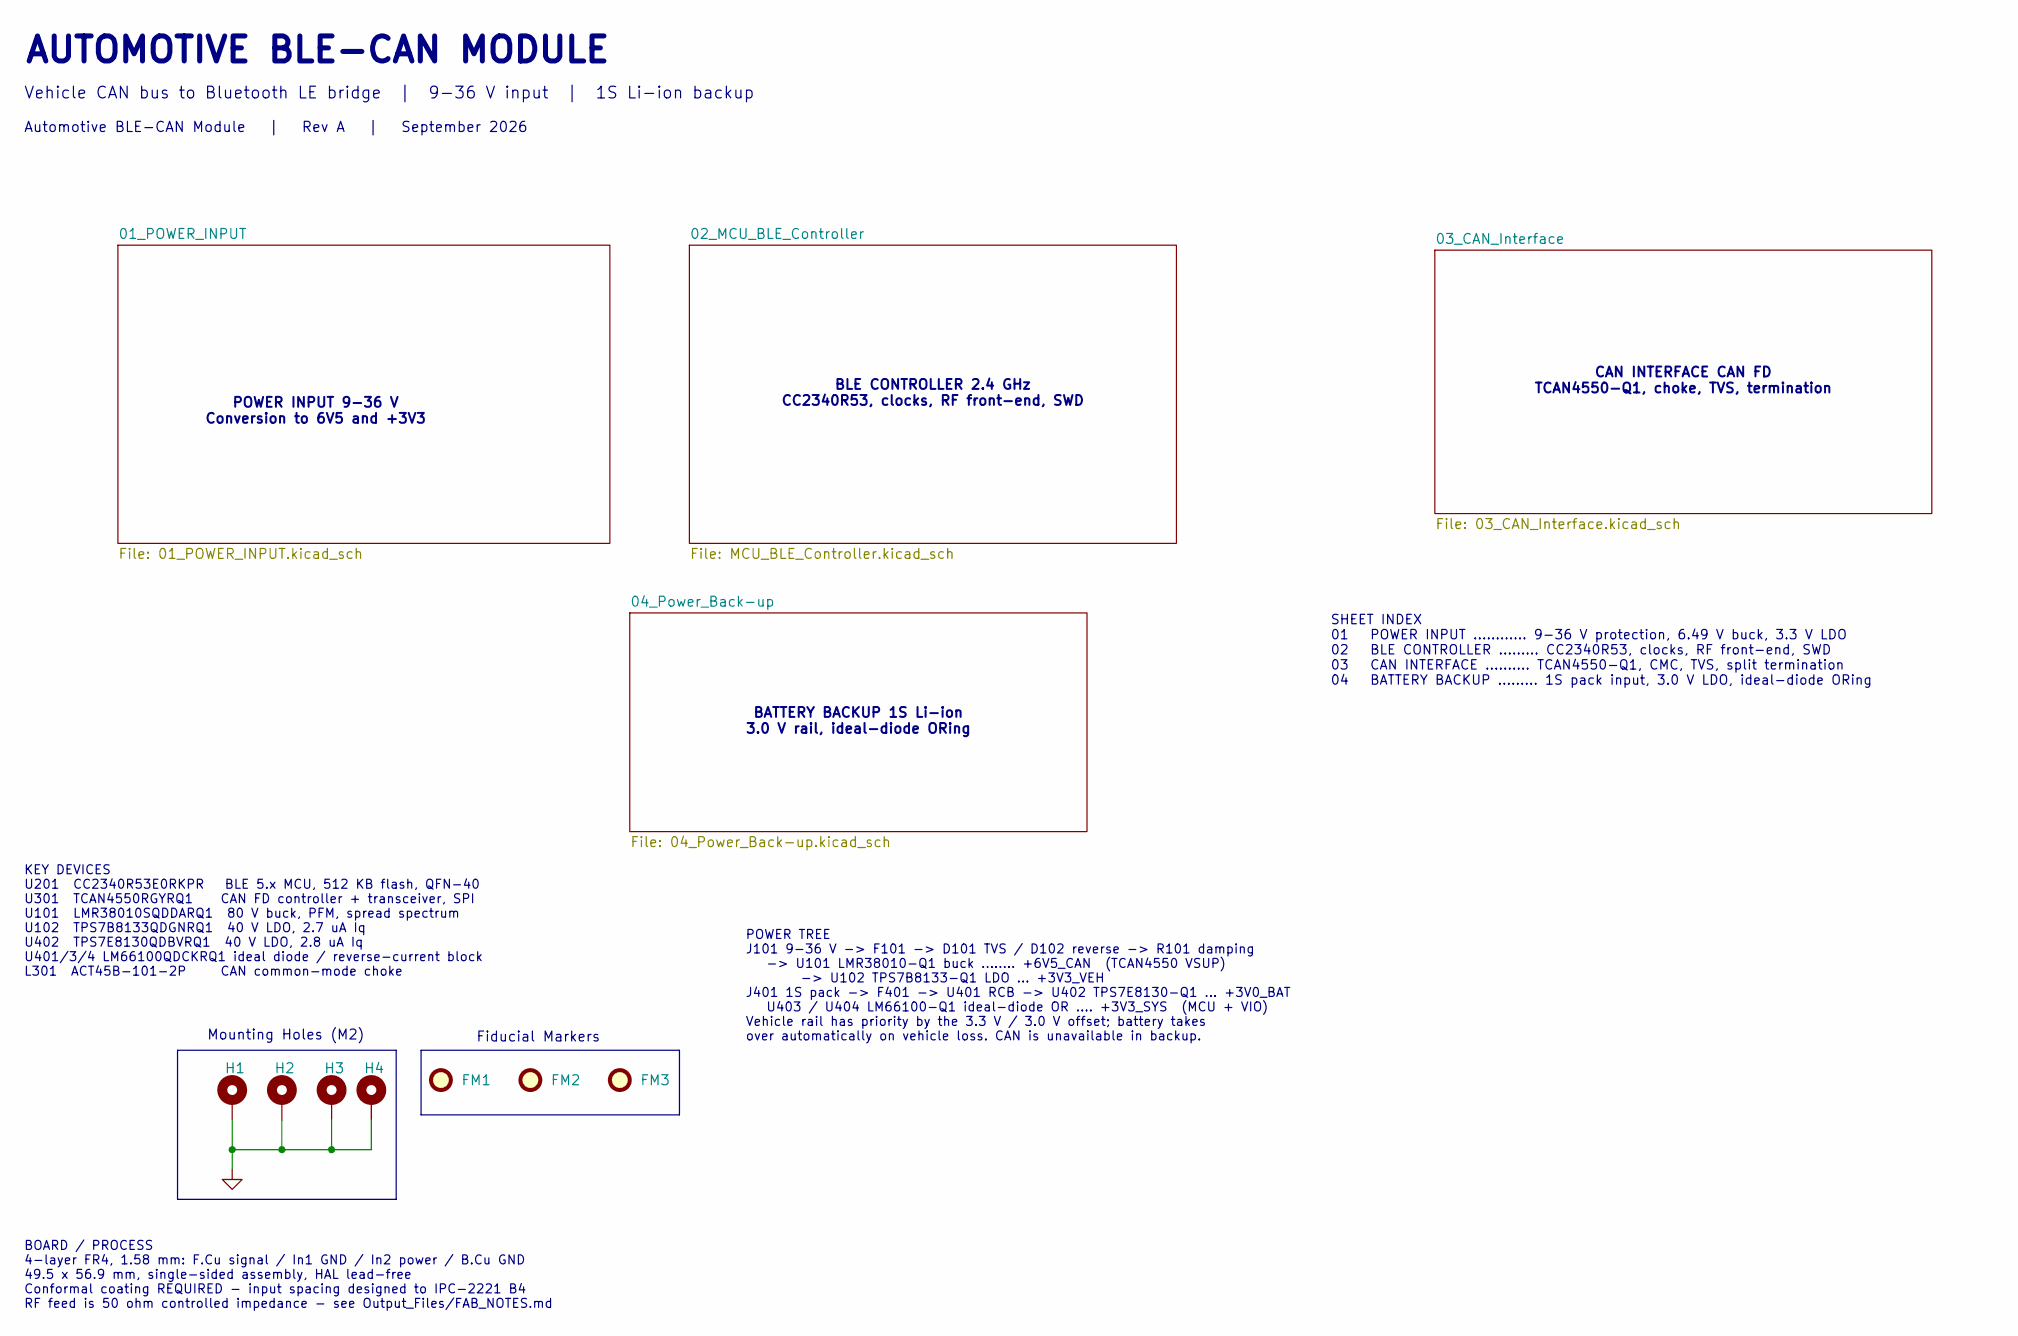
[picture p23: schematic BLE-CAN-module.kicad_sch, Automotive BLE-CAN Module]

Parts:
FM1, FM2, FM3: Fiducial; Fiducial_1mm_Mask2mm
H1, H2, H3, H4: MountingHole_Pad; MountingHole_2.2mm_M2_Pad_Via

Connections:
GND: H1.1 (1_1), H2.1 (1_1), H3.1 (1_1), H4.1 (1_1); also elsewhere on the board

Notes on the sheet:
SHEET INDEX 01 POWER INPUT ............ 9-36 V protection, 6.49 V buck, 3.3 V LDO 02 BLE CONTROLLER ......... CC2340R53, clocks, RF front-end, SWD 03 CAN INTERFACE .......... TCAN4550-Q1, CMC, TVS, split termination 04 BATTERY BACKUP ......... 1S pack input, 3.0 V LDO, ideal-diode ORing
POWER INPUT 9-36 V Conversion to 6V5 and +3V3
KEY DEVICES U201 CC2340R53E0RKPR BLE 5.x MCU, 512 KB flash, QFN-40 U301 TCAN4550RGYRQ1 CAN FD controller + transceiver, SPI U101 LMR38010SQDDARQ1 80 V buck, PFM, spread spectrum U102 TPS7B8133QDGNRQ1 40 V LDO, 2.7 uA Iq U402 TPS7E8130QDBVRQ1 40 V LDO, 2.8 uA Iq U401/3/4 LM66100QDCKRQ1 ideal diode /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
Vehicle CAN bus to Bluetooth LE bridge | 9-36 V input | 1S Li-ion backup
POWER TREE J101 9-36 V -> F101 -> D101 TVS / D102 reverse -> R101 damping -> U101 LMR38010-Q1 buck ........ +6V5_CAN (TCAN4550 VSUP) -> U102 TPS7B8133-Q1 LDO ... +3V3_VEH J401 1S pack -> F401 -> U401 RCB -> U402 TPS7E8130-Q1 ... +3V0_BAT U403 / U404 LM66100-Q1 ideal-diode OR .... +3V3_SYS (MCU + VI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
AUTOMOTIVE BLE-CAN MODULE
Mounting Holes (M2)
BOARD / PROCESS 4-layer FR4, 1.58 mm: F.Cu signal / In1 GND / In2 power / B.Cu GND 49.5 x 56.9 mm, single-sided assembly, HAL lead-free Conformal coating REQUIRED - input spacing designed to IPC-2221 B4 RF feed is 50 ohm controlled impedance - see Output_Files/FAB_NOTES.md
Fiducial Markers
Automotive BLE-CAN Module | Rev A | September 2026
BLE CONTROLLER 2.4 GHz CC2340R53, clocks, RF front-end, SWD
CAN INTERFACE CAN FD TCAN4550-Q1, choke, TVS, termination
BATTERY BACKUP 1S Li-ion 3.0 V rail, ideal-diode ORing

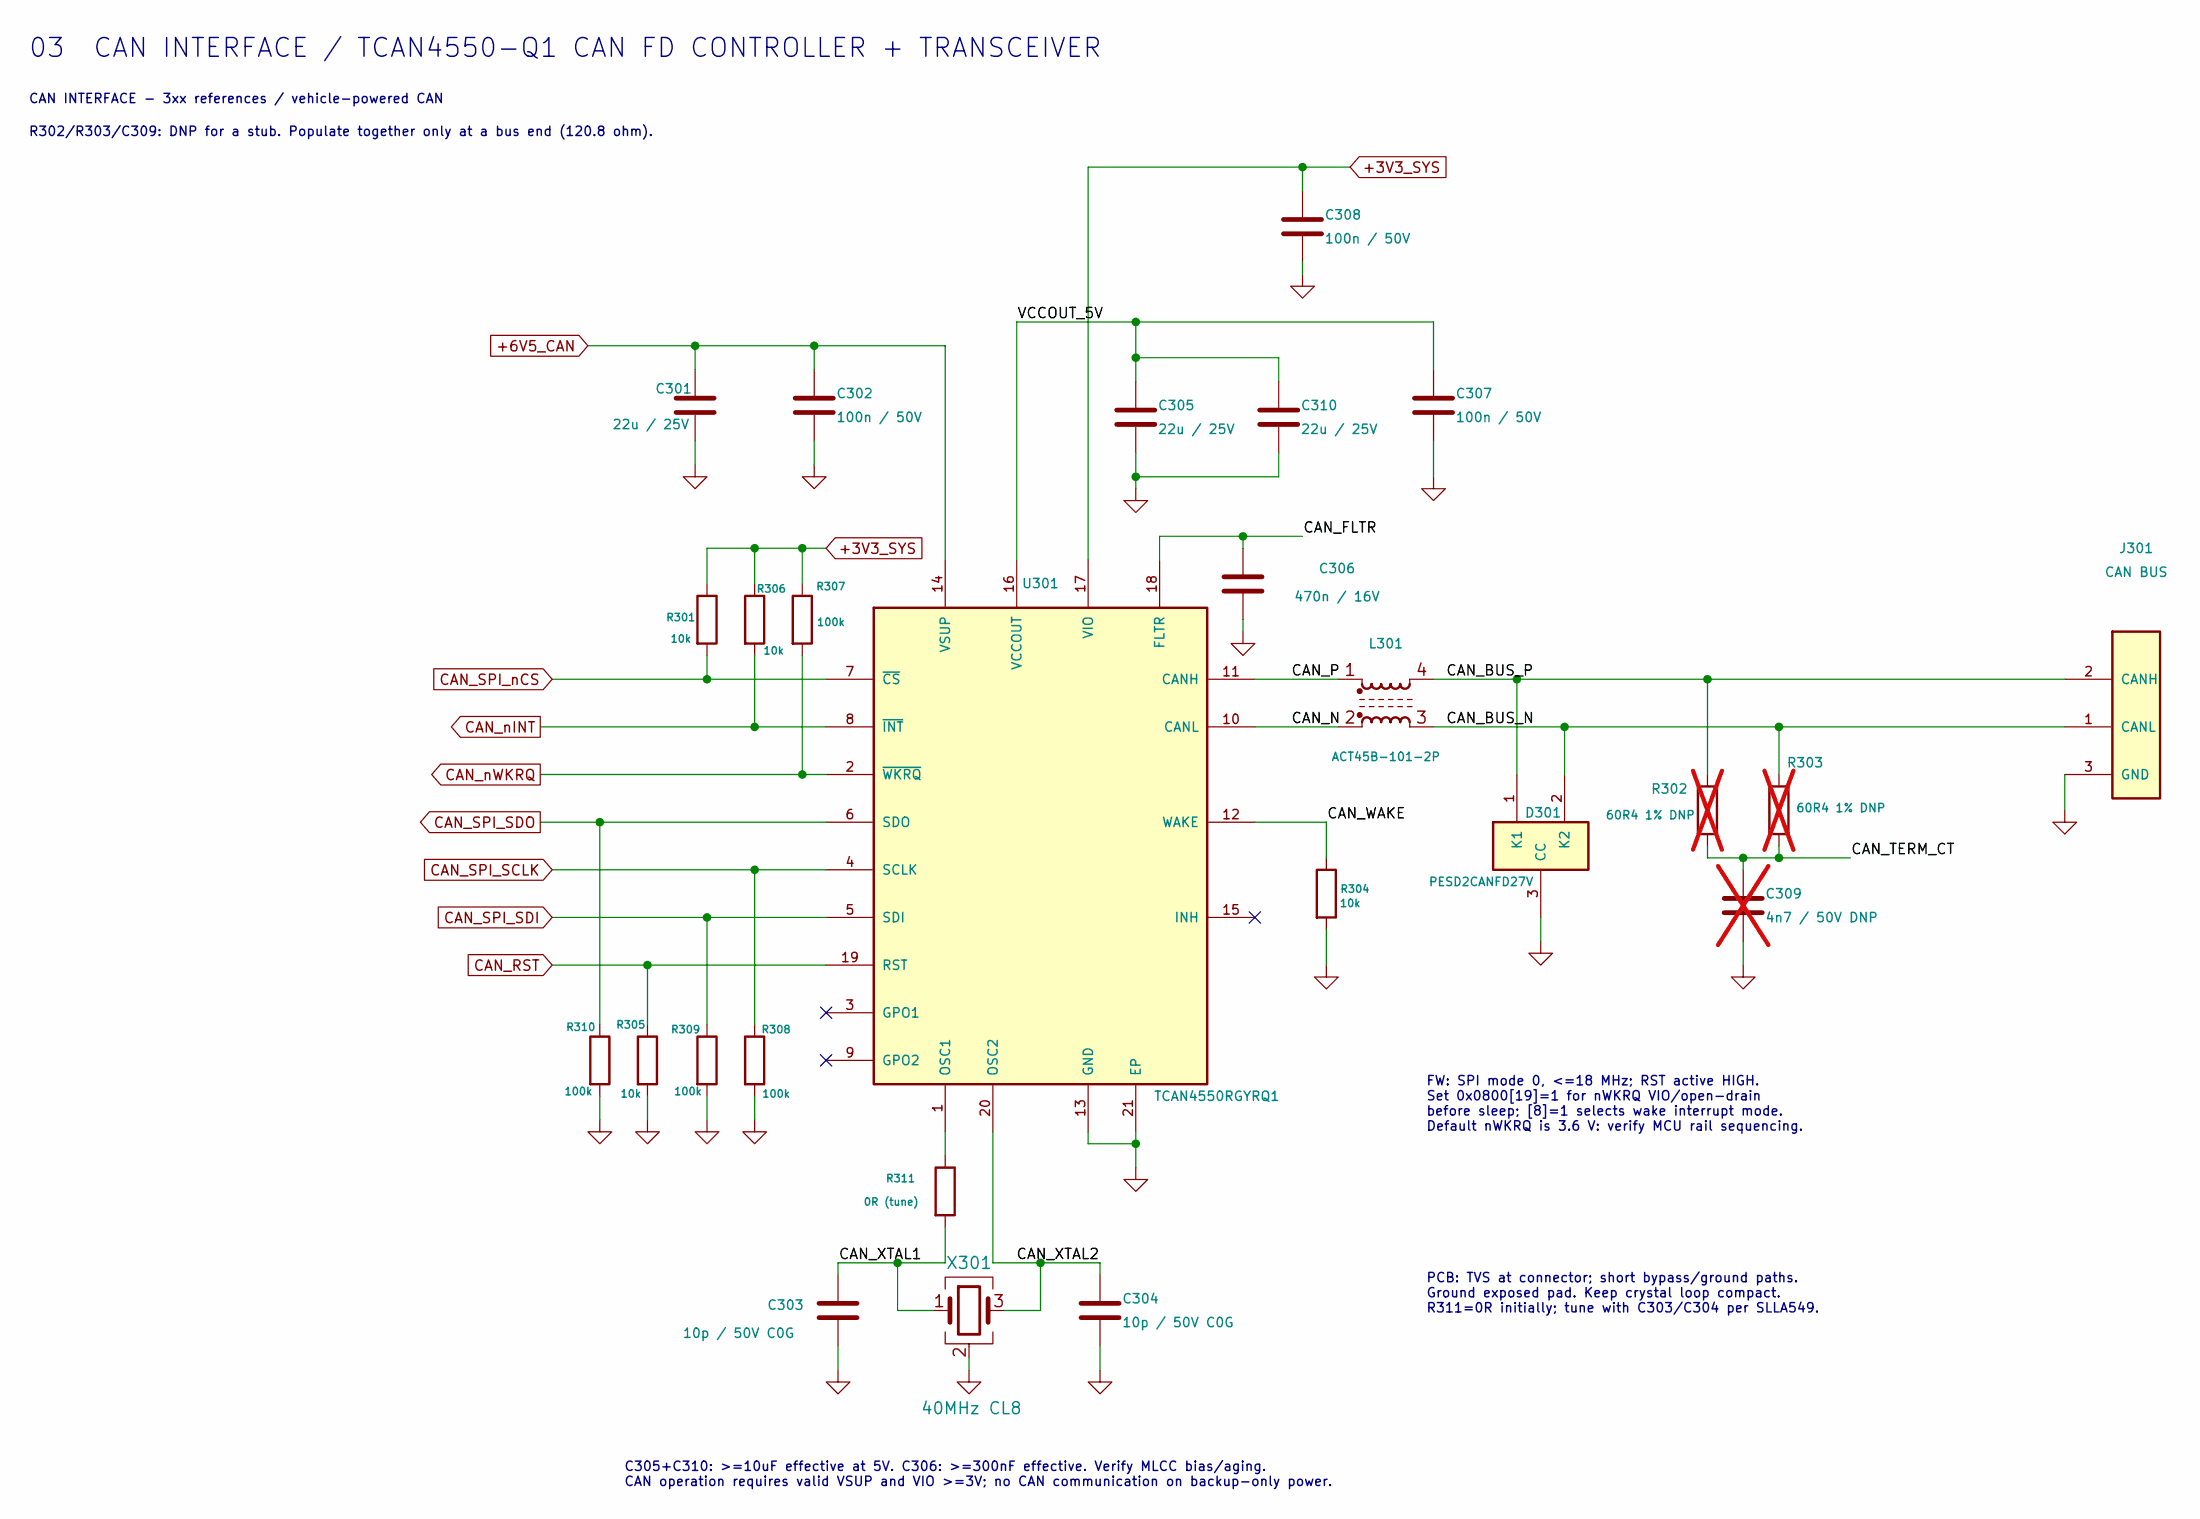
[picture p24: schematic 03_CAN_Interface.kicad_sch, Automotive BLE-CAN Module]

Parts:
C301, C305, C310: 22u / 25V; C_1210_3225Metric; MPN CGA6P3X7R1E226M250AB
C302, C307, C308: 100n / 50V; C_0603_1608Metric; MPN CGA3E2X7R1H104K080AA
C303, C304: 10p / 50V C0G; C_0603_1608Metric; MPN CGA3E2C0G1H100D080AA
C306: 470n / 16V; C_0603_1608Metric; MPN CGA3E1X7R1C474K080AC
C309: 4n7 / 50V DNP; C_0603_1608Metric; MPN CGA3E2X7R1H472K080AA; not fitted
D301: PESD2CANFD27V; SOT-23; MPN PESD2CANFD27V-T
J301: CAN BUS; TerminalBlock_Phoenix_MPT-0,5-3-2.54_1x03_P2.54mm_Horizontal; MPN 1725669
L301: ACT45B-101-2P; L_CommonModeChoke_Coilank_ACM4532; MPN ACT45B-101-2P-TL003
R301, R304, R305, R306: 10k; R_0603_1608Metric; MPN CRCW060310K0FKEA
R302, R303: 60R4 1% DNP; R_0805_2012Metric; MPN CRCW080560R4FKEA; not fitted
R307, R308, R309, R310: 100k; R_0603_1608Metric; MPN CRCW0603100KFKEA
R311: 0R (tune); R_0603_1608Metric; MPN CRCW06030000Z0EA
U301: TCAN4550RGYRQ1; TI_RGY0020A_VQFN20; MPN TCAN4550RGYRQ1
X301: 40MHz CL8; Crystal_SMD_2016-4Pin_2.0x1.6mm

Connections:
+3V3_SYS: C308.1, R301.1, R306.1, R307.1, U301.17 (VIO); also elsewhere on the board
+6V5_CAN: C301.1, C302.1, U301.14 (VSUP); also elsewhere on the board
/03_CAN_Interface/CAN_BUS_N: D301.2 (K2), J301.1 (CANL), L301.3, R303.1
/03_CAN_Interface/CAN_BUS_P: D301.1 (K1), J301.2 (CANH), L301.4, R302.1
/03_CAN_Interface/CAN_FLTR: C306.1, U301.18 (FLTR)
/03_CAN_Interface/CAN_N: L301.2, U301.10 (CANL)
/03_CAN_Interface/CAN_P: L301.1, U301.11 (CANH)
/03_CAN_Interface/CAN_TERM_CT: C309.1, R302.2, R303.2
/03_CAN_Interface/CAN_WAKE: R304.1, U301.12 (WAKE)
/03_CAN_Interface/CAN_XTAL1: C303.1, R311.2, X301.1
/03_CAN_Interface/CAN_XTAL2: C304.1, U301.20 (OSC2), X301.3
/03_CAN_Interface/VCCOUT_5V: C305.1, C307.1, C310.1, U301.16 (VCCOUT)
CAN_RST: R305.1, U301.19 (RST); also elsewhere on the board
CAN_SPI_SCLK: R308.1, U301.4 (SCLK); also elsewhere on the board
CAN_SPI_SDI: R309.1, U301.5 (SDI); also elsewhere on the board
CAN_SPI_SDO: R310.1, U301.6 (SDO); also elsewhere on the board
CAN_SPI_nCS: R301.2, U301.7 (~CS); also elsewhere on the board
CAN_nINT: R306.2, U301.8 (~INT); also elsewhere on the board
CAN_nWKRQ: R307.2, U301.2 (~WKRQ); also elsewhere on the board
GND: C301.2, C302.2, C303.2, C304.2, C305.2, C306.2, C307.2, C308.2, C309.2, C310.2, D301.3 (CC), J301.3 (GND), R304.2, R305.2, R308.2, R309.2, R310.2, U301.13 (GND), U301.21 (EP), X301.2 (G), X301.4 (G); also elsewhere on the board
unnamed: R311.1, U301.1 (OSC1)

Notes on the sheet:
03 CAN INTERFACE / TCAN4550-Q1 CAN FD CONTROLLER + TRANSCEIVER
CAN INTERFACE - 3xx references / vehicle-powered CAN
R302/R303/C309: DNP for a stub. Populate together only at a bus end (120.8 ohm).
C305+C310: >=10uF effective at 5V. C306: >=300nF effective. Verify MLCC bias/aging. CAN operation requires valid VSUP and VIO >=3V; no CAN communication on backup-only power.
FW: SPI mode 0, <=18 MHz; RST active HIGH. Set 0x0800[19]=1 for nWKRQ VIO/open-drain before sleep; [8]=1 selects wake interrupt mode. Default nWKRQ is 3.6 V: verify MCU rail sequencing.
PCB: TVS at connector; short bypass/ground paths. Ground exposed pad. Keep crystal loop compact. R311=0R initially; tune with C303/C304 per SLLA549.

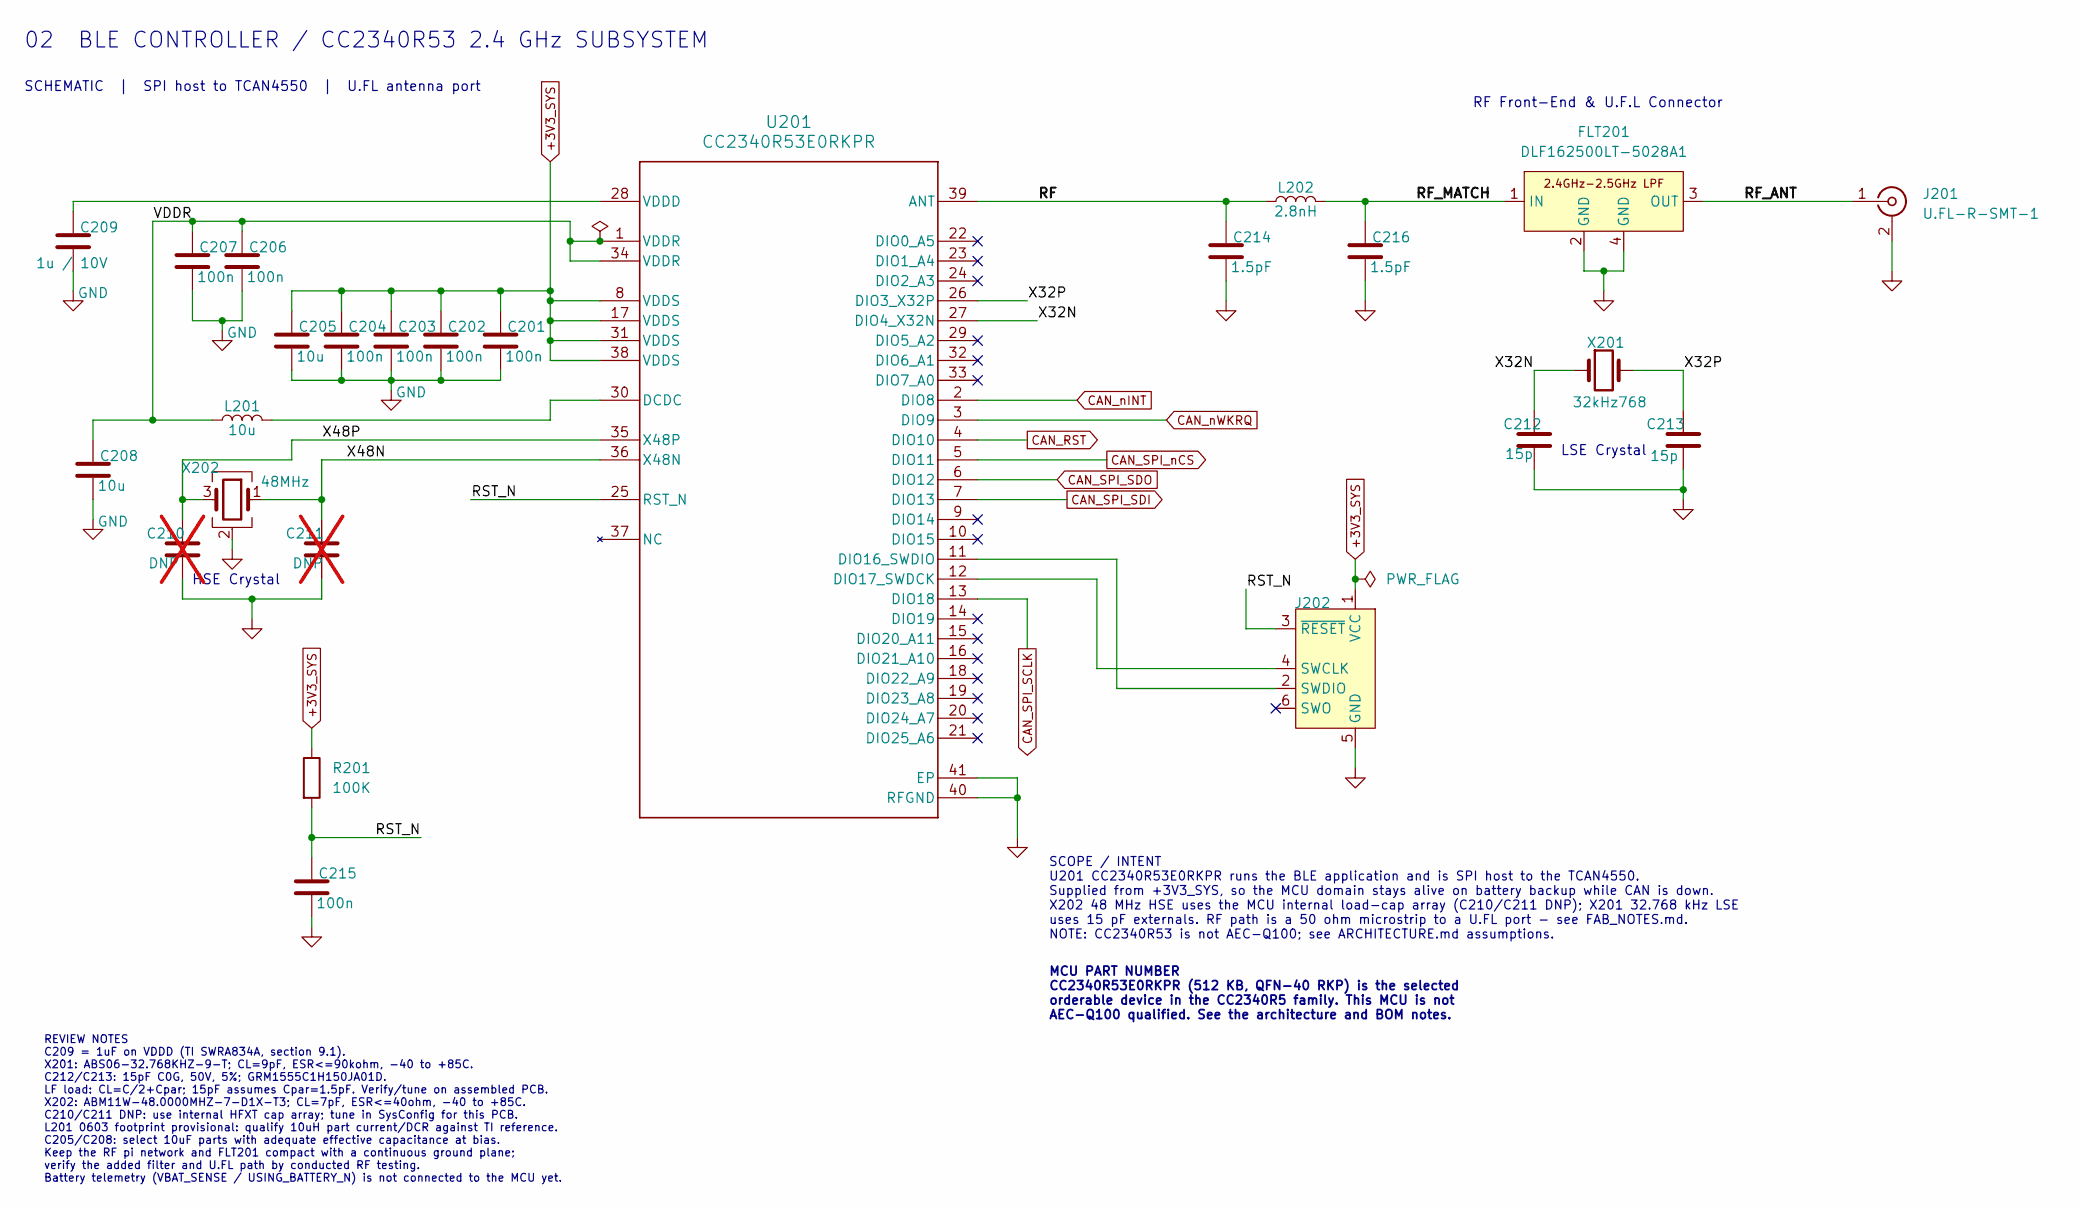
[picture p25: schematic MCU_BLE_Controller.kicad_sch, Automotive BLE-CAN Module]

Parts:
C201, C202, C203, C204, C206, C207, C215: 100n; C_0402_1005Metric
C205, C208: 10u; C_0805_2012Metric
C209: 1u / 10V; C_0603_1608Metric
C210, C211: DNP; C_0402_1005Metric; not fitted
C212, C213: 15p; C_0402_1005Metric; MPN GRM1555C1H150JA01D
C214, C216: 1.5pF; C_0402_1005Metric
FLT201: DLF162500LT-5028A1
J201: U.FL-R-SMT-1; U.FL_Hirose_U.FL-R-SMT-1_Vertical
J202: Conn_ARM_SWD_TagConnect_TC2030; Tag-Connect_TC2030-IDC-FP_2x03_P1.27mm_Vertical
L201: 10u; L_0603_1608Metric
L202: 2.8nH; L_0402_1005Metric
R201: 100K; R_0402_1005Metric
U201: CC2340R53E0RKPR; RKP0040B-MFG
X201: 32kHz768; Crystal_SMD_2012-2Pin_2.0x1.2mm; MPN ABS06-32.768KHZ-9-T
X202: 48MHz; Crystal_SMD_2016-4Pin_2.0x1.6mm; MPN ABM11W-48.0000MHZ-7-D1X-T3

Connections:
+3V3_SYS: C201.1, C202.1, C203.1, C204.1, C205.1, J202.1 (VCC), R201.1, U201.8 (VDDS), U201.17 (VDDS), U201.31 (VDDS), U201.38 (VDDS); also elsewhere on the board
/02_MCU_BLE_Controller/RF: C214.1, L202.1, U201.39 (ANT)
/02_MCU_BLE_Controller/RF_ANT: FLT201.3 (OUT), J201.1 (In)
/02_MCU_BLE_Controller/RF_MATCH: C216.1, FLT201.1 (IN), L202.2
/02_MCU_BLE_Controller/RST_N: C215.1, J202.3 (~RESET), R201.2, U201.25 (RST_N)
/02_MCU_BLE_Controller/VDDR: C206.1, C207.1, C208.1, L201.1, U201.1 (VDDR), U201.34 (VDDR)
/02_MCU_BLE_Controller/X32N: C212.1, U201.27 (DIO4_X32N), X201.1
/02_MCU_BLE_Controller/X32P: C213.1, U201.26 (DIO3_X32P), X201.2
/02_MCU_BLE_Controller/X48N: C211.1, U201.36 (X48N), X202.1
/02_MCU_BLE_Controller/X48P: C210.1, U201.35 (X48P), X202.3
CAN_RST: U201.4 (DIO10); also elsewhere on the board
CAN_SPI_SCLK: U201.13 (DIO18); also elsewhere on the board
CAN_SPI_SDI: U201.7 (DIO13); also elsewhere on the board
CAN_SPI_SDO: U201.6 (DIO12); also elsewhere on the board
CAN_SPI_nCS: U201.5 (DIO11); also elsewhere on the board
CAN_nINT: U201.2 (DIO8); also elsewhere on the board
CAN_nWKRQ: U201.3 (DIO9); also elsewhere on the board
GND: C201.2, C202.2, C203.2, C204.2, C205.2, C206.2, C207.2, C208.2, C209.2, C210.2, C211.2, C212.2, C213.2, C214.2, C215.2, C216.2, FLT201.2 (GND), FLT201.4 (GND), J201.2 (Ext), J202.5 (GND), U201.40 (RFGND), U201.41 (EP), X202.2 (G), X202.4 (G); also elsewhere on the board
unnamed: J202.4 (SWCLK), U201.12 (DIO17_SWDCK)
unnamed: J202.2 (SWDIO), U201.11 (DIO16_SWDIO)
unnamed: L201.2, U201.30 (DCDC)
unnamed: C209.1, U201.28 (VDDD)

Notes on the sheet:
SCHEMATIC | SPI host to TCAN4550 | U.FL antenna port
SCOPE / INTENT U201 CC2340R53E0RKPR runs the BLE application and is SPI host to the TCAN4550. Supplied from +3V3_SYS, so the MCU domain stays alive on battery backup while CAN is down. X202 48 MHz HSE uses the MCU internal load-cap array (C210/C211 DNP); X201 32.768 kHz LSE uses 15 pF externals. RF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
LSE Crystal
MCU PART NUMBER CC2340R53E0RKPR (512 KB, QFN-40 RKP) is the selected orderable device in the CC2340R5 family. This MCU is not AEC-Q100 qualified. See the architecture and BOM notes.
REVIEW NOTES C209 = 1uF on VDDD (TI SWRA834A, section 9.1). X201: ABS06-32.768KHZ-9-T; CL=9pF, ESR<=90kohm, -40 to +85C. C212/C213: 15pF C0G, 50V, 5%; GRM1555C1H150JA01D. LF load: CL=C/2+Cpar; 15pF assumes Cpar=1.5pF. Verify/tune on assembled PCB. X202: ABM11W-48.0000MHZ-7-D1X-T3; CL=7pF, ESR<=40oh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
RF Front-End & U.F.L Connector
HSE Crystal
02 BLE CONTROLLER / CC2340R53 2.4 GHz SUBSYSTEM

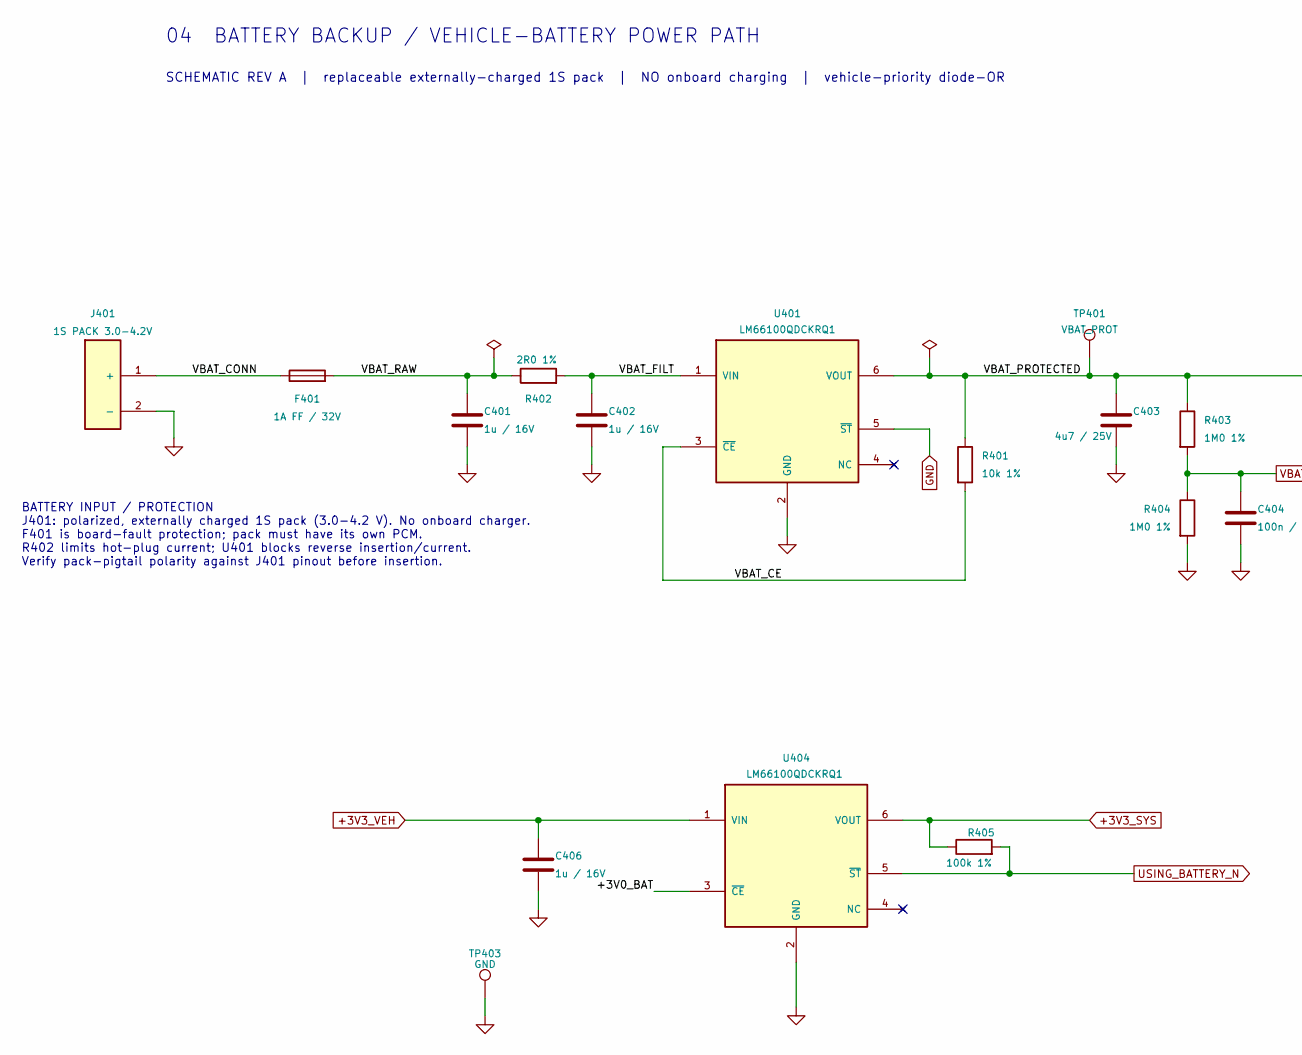
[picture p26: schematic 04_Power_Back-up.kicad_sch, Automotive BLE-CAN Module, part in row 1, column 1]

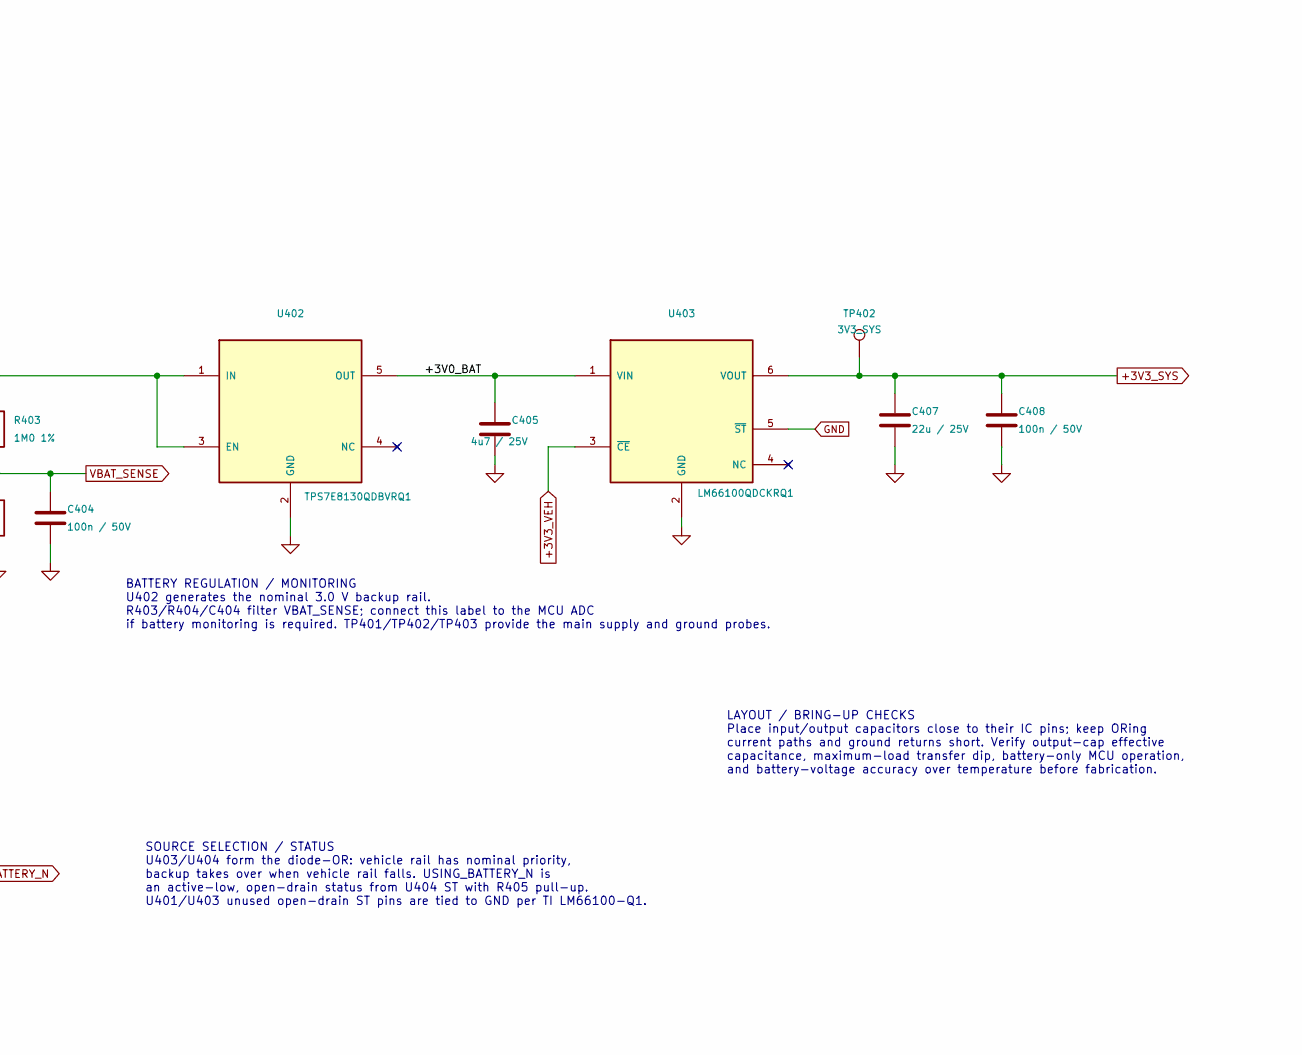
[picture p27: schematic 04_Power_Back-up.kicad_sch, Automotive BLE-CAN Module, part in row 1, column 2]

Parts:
C401, C402, C406: 1u / 16V; C_0603_1608Metric; MPN CGA3E1X7R1C105K080AC
C403, C405: 4u7 / 25V; C_0805_2012Metric; MPN CGA4J1X7R1E475K125AC
C404, C408: 100n / 50V; C_0603_1608Metric; MPN CGA3E2X7R1H104K080AA
C407: 22u / 25V; C_1210_3225Metric; MPN CGA6P3X7R1E226M250AB
F401: 1A FF / 32V; Fuse_0603_1608Metric; MPN MFU0603FF01000P1AT
J401: 1S PACK 3.0-4.2V; JST_PH_S2B-PH-K_1x02_P2.00mm_Horizontal; MPN S2B-PH-K-S(LF)(SN)
R401: 10k 1%; R_0603_1608Metric; MPN CRCW060310K0FKEA
R402: 2R0 1%; R_0603_1608Metric; MPN CRCW06032R00FKEA
R403, R404: 1M0 1%; R_0603_1608Metric; MPN CRCW06031M00FKEA
R405: 100k 1%; R_0603_1608Metric; MPN CRCW0603100KFKEA
TP401: VBAT_PROT; TestPoint_Pad_D2.0mm; MPN N/A - PCB copper pad
TP402: 3V3_SYS; TestPoint_Pad_D2.0mm; MPN N/A - PCB copper pad
TP403: GND; TestPoint_Pad_D2.0mm; MPN N/A - PCB copper pad
U401, U403, U404: LM66100QDCKRQ1; SOT-363_SC-70-6; MPN LM66100QDCKRQ1
U402: TPS7E8130QDBVRQ1; SOT-23-5; MPN TPS7E8130QDBVRQ1

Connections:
+3V3_SYS: C407.1, C408.1, R405.1, TP402.1 (1_1), U403.6 (VOUT), U404.6 (VOUT); also elsewhere on the board
+3V3_VEH: C406.1, U403.3 (~CE), U404.1 (VIN); also elsewhere on the board
/04_Power_Back-up/+3V0_BAT: C405.1, U402.5 (OUT), U403.1 (VIN), U404.3 (~CE)
/04_Power_Back-up/VBAT_CE: R401.2, U401.3 (~CE)
/04_Power_Back-up/VBAT_CONN: F401.1, J401.1 (+)
/04_Power_Back-up/VBAT_FILT: C402.1, R402.2, U401.1 (VIN)
/04_Power_Back-up/VBAT_PROTECTED: C403.1, R401.1, R403.1, TP401.1 (1_1), U401.6 (VOUT), U402.1 (IN), U402.3 (EN)
/04_Power_Back-up/VBAT_RAW: C401.1, F401.2, R402.1
GND: C401.2, C402.2, C403.2, C404.2, C405.2, C406.2, C407.2, C408.2, J401.2 (-), R404.2, TP403.1 (1_1), U401.2 (GND), U401.5 (~ST), U402.2 (GND), U403.2 (GND), U403.5 (~ST), U404.2 (GND); also elsewhere on the board
USING_BATTERY_N: R405.2, U404.5 (~ST)
VBAT_SENSE: C404.1, R403.2, R404.1

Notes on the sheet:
LAYOUT / BRING-UP CHECKS Place input/output capacitors close to their IC pins; keep ORing current paths and ground returns short. Verify output-cap effective capacitance, maximum-load transfer dip, battery-only MCU operation, and battery-voltage accuracy over temperature before fabrication.
SCHEMATIC REV A | replaceable externally-charged 1S pack | NO onboard charging | vehicle-priority diode-OR
BATTERY INPUT / PROTECTION J401: polarized, externally charged 1S pack (3.0-4.2 V). No onboard charger. F401 is board-fault protection; pack must have its own PCM. R402 limits hot-plug current; U401 blocks reverse insertion/current. Verify pack-pigtail polarity against J401 pinout before insertion.
04 BATTERY BACKUP / VEHICLE-BATTERY POWER PATH
BATTERY REGULATION / MONITORING U402 generates the nominal 3.0 V backup rail. R403/R404/C404 filter VBAT_SENSE; connect this label to the MCU ADC if battery monitoring is required. TP401/TP402/TP403 provide the main supply and ground probes.
SOURCE SELECTION / STATUS U403/U404 form the diode-OR: vehicle rail has nominal priority, backup takes over when vehicle rail falls. USING_BATTERY_N is an active-low, open-drain status from U404 ST with R405 pull-up. U401/U403 unused open-drain ST pins are tied to GND per TI LM66100-Q1.

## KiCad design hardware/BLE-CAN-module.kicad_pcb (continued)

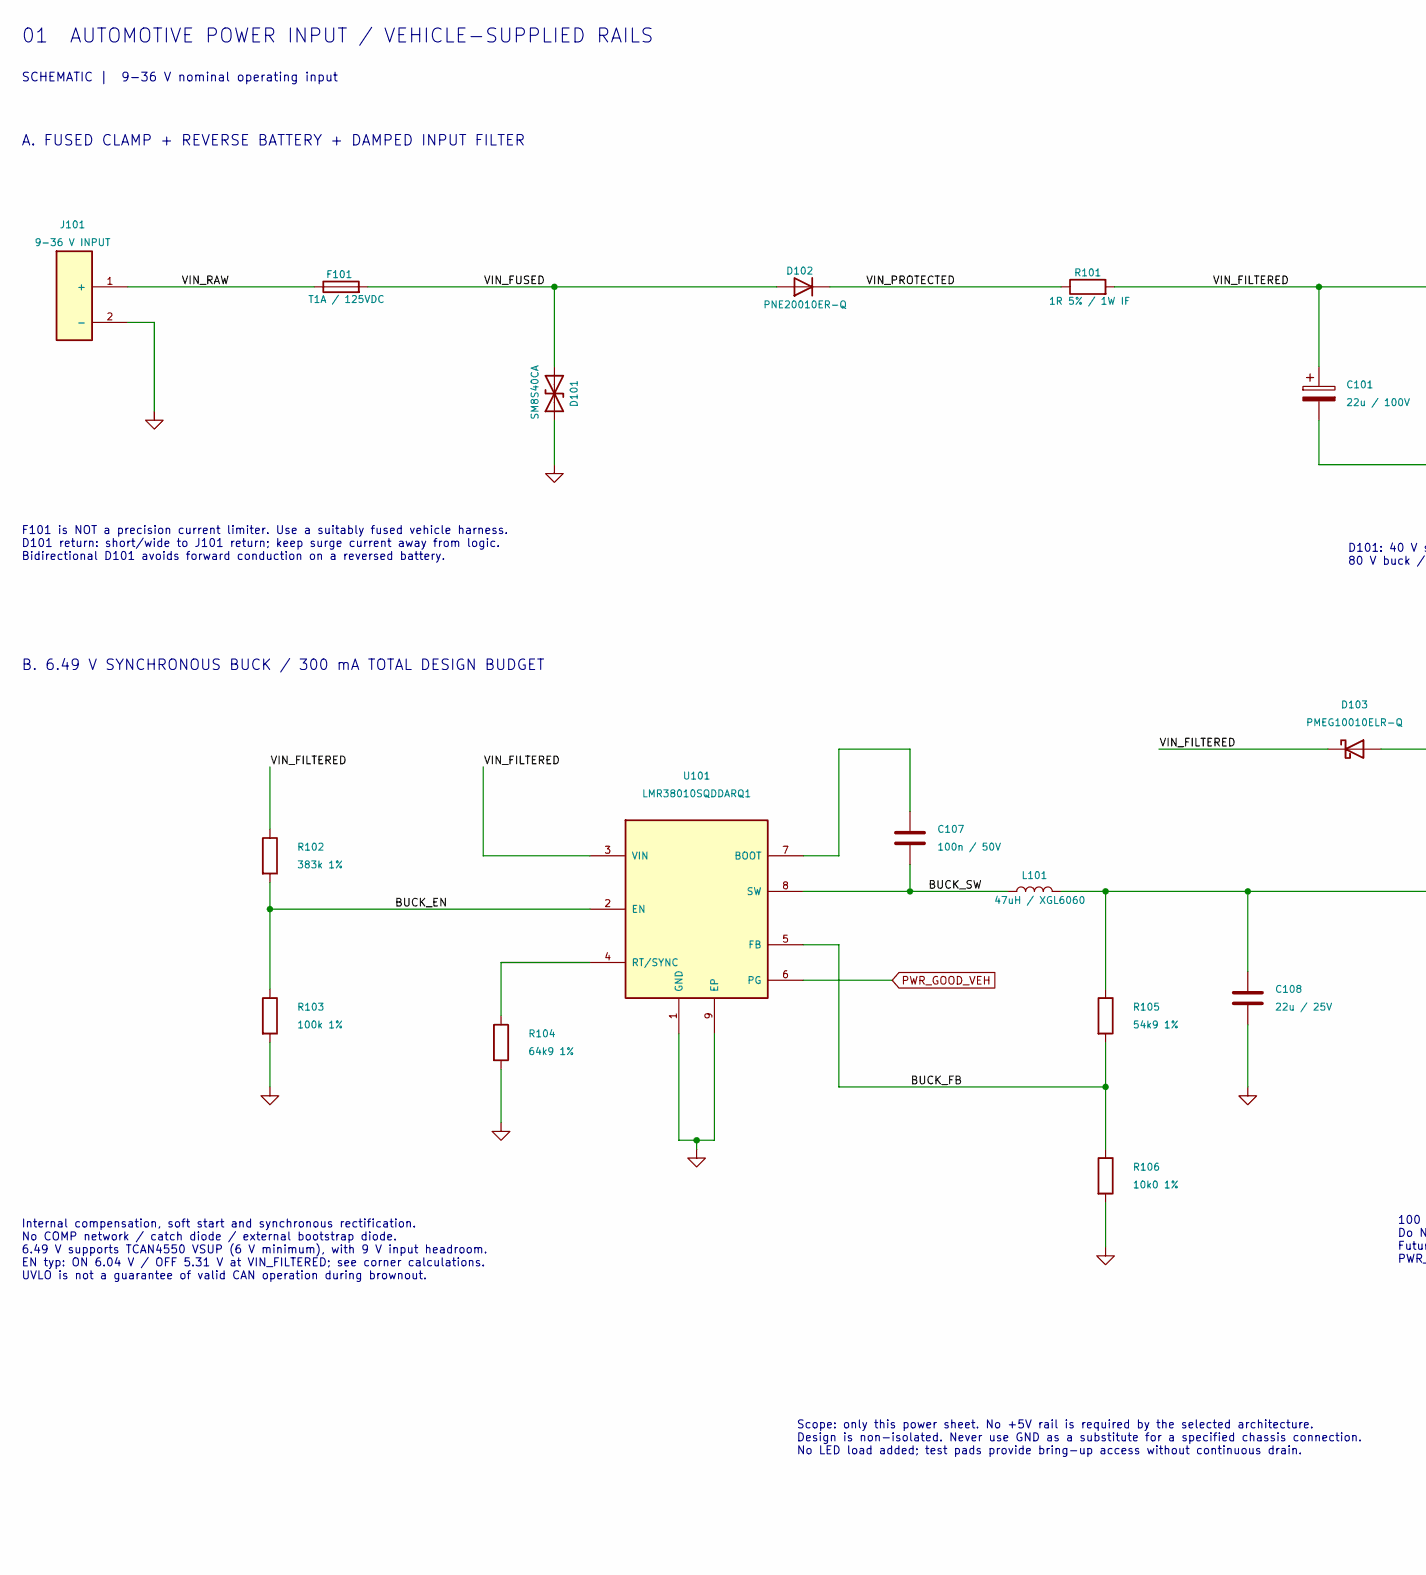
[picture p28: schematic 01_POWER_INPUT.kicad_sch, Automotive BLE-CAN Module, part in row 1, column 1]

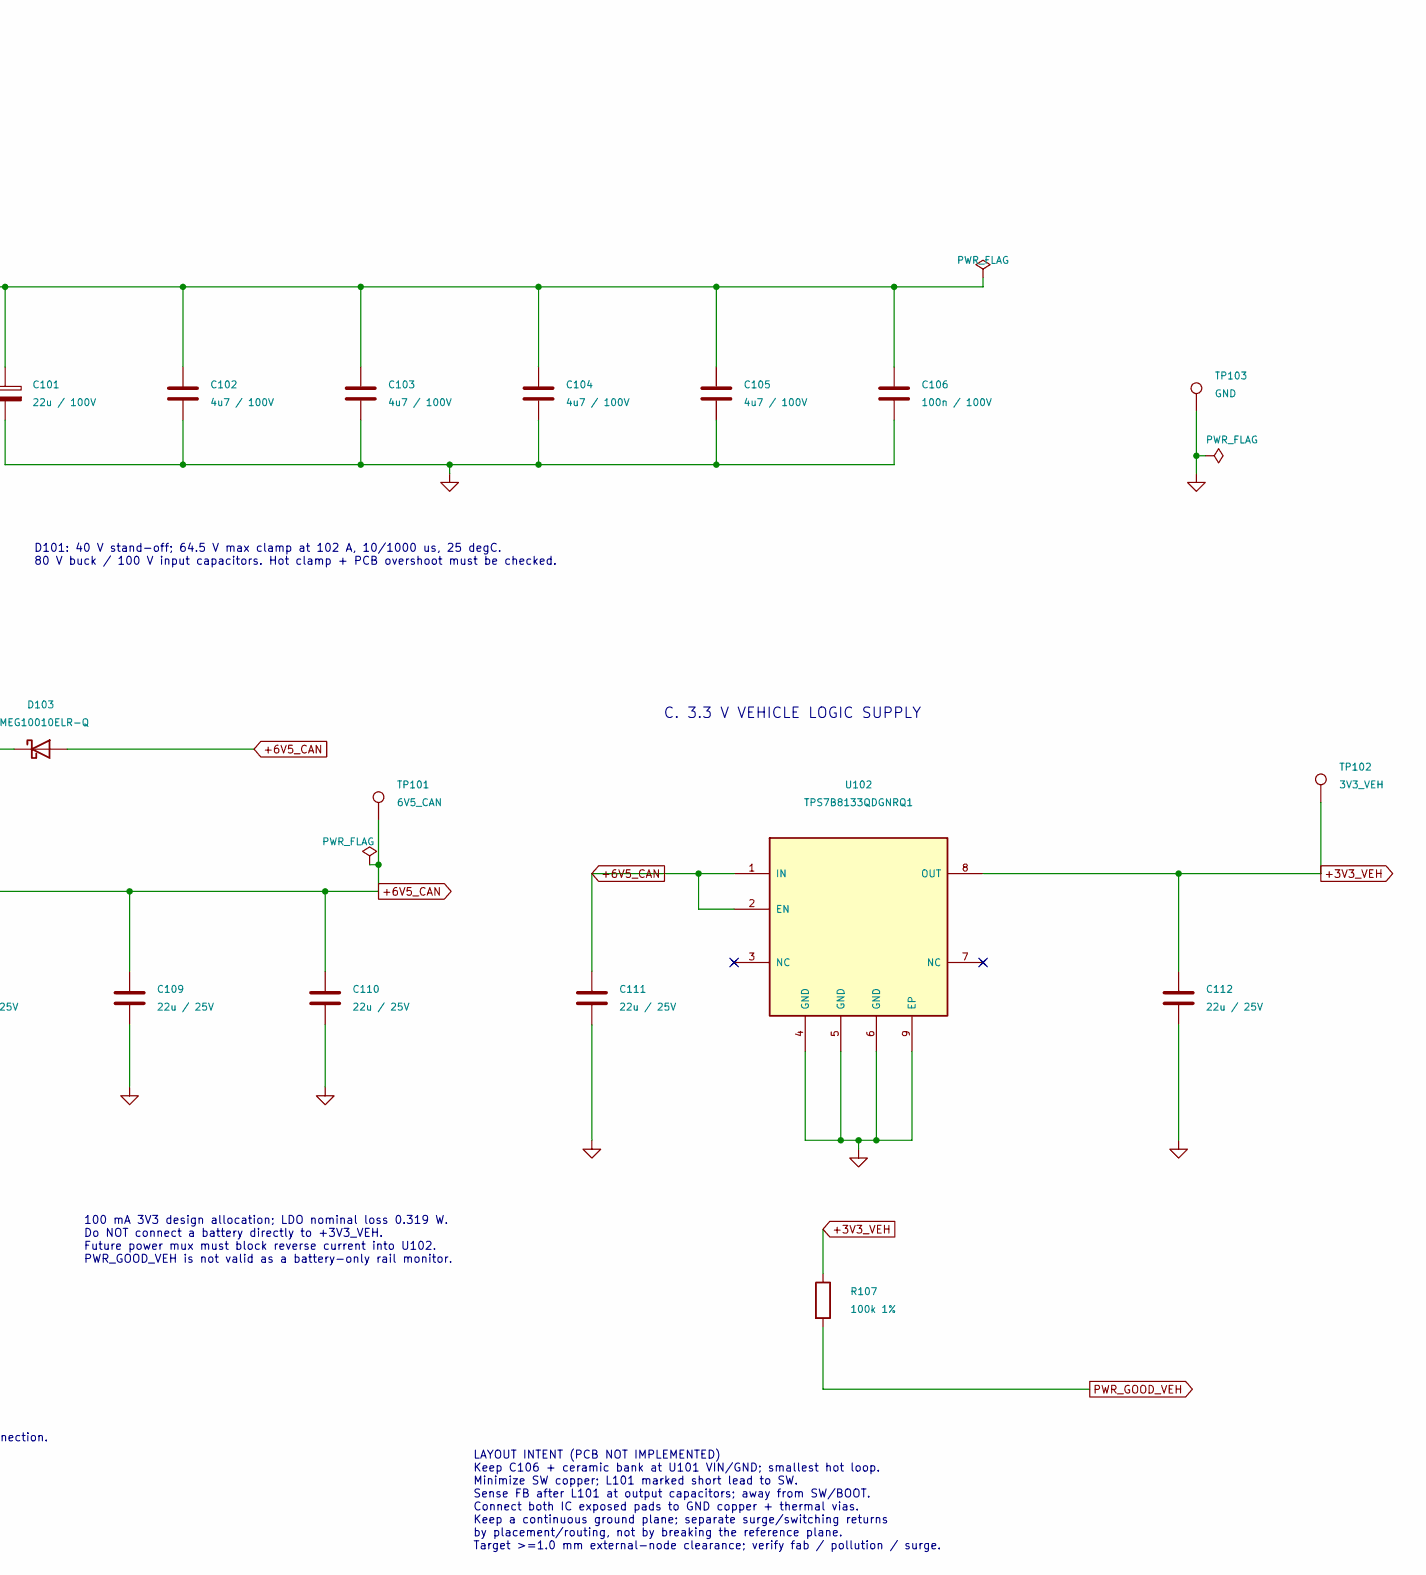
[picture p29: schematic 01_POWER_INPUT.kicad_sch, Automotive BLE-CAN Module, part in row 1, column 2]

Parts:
C101: 22u / 100V; Panasonic_FK_F_8x10.2; MPN EEEFK2A220P
C102, C103, C104, C105: 4u7 / 100V; C_1206_3216Metric; MPN CGA5L1X7R2A475K160AC
C106: 100n / 100V; C_0805_2012Metric; MPN CGA4J2X7R2A104K125AA
C107: 100n / 50V; C_0603_1608Metric; MPN CGA3E2X7R1H104K080AA
C108, C109, C110, C111, C112: 22u / 25V; C_1210_3225Metric; MPN CGA6P3X7R1E226M250AB
D101: SM8S40CA; Vishay_DO-218AC_SM8S; MPN SM8S40CAHM3_A/I
D102: PNE20010ER-Q; Nexperia_CFP3_SOD-123W; MPN PNE20010ER-QX
D103: PMEG10010ELR-Q; Nexperia_CFP3_SOD-123W; MPN PMEG10010ELR-QX
F101: T1A / 125VDC; Fuse_Schurter_UMT250; MPN 3403.0166.24
J101: 9-36 V INPUT; TerminalBlock_Phoenix_MPT-0,5-2-2.54_1x02_P2.54mm_Horizontal; MPN 1725656
L101: 47uH / XGL6060; Coilcraft_XGL6060; MPN XGL6060-473MEC
R101: 1R 5% / 1W IF; R_2512_6332Metric; MPN CRCW25121R00JNEGIF
R102: 383k 1%; R_0603_1608Metric; MPN CRCW0603383KFKEA
R103, R107: 100k 1%; R_0603_1608Metric; MPN CRCW0603100KFKEA
R104: 64k9 1%; R_0603_1608Metric; MPN CRCW060364K9FKEA
R105: 54k9 1%; R_0603_1608Metric; MPN CRCW060354K9FKEA
R106: 10k0 1%; R_0603_1608Metric; MPN CRCW060310K0FKEA
TP101: 6V5_CAN; TestPoint_Pad_D2.0mm; MPN N/A - PCB copper pad
TP102: 3V3_VEH; TestPoint_Pad_D2.0mm; MPN N/A - PCB copper pad
TP103: GND; TestPoint_Pad_D2.0mm; MPN N/A - PCB copper pad
U101: LMR38010SQDDARQ1; TI_DDA0008B_PowerPAD; MPN LMR38010SQDDARQ1
U102: TPS7B8133QDGNRQ1; TI_DGN0008G_PowerPAD; MPN TPS7B8133QDGNRQ1

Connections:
+3V3_VEH: C112.1, R107.1, TP102.1 (1_1), U102.8 (OUT); also elsewhere on the board
+6V5_CAN: C108.1, C109.1, C110.1, C111.1, D103.2 (A), L101.2, R105.1, TP101.1 (1_1), U102.1 (IN), U102.2 (EN); also elsewhere on the board
/01_POWER_INPUT/BUCK_EN: R102.2, R103.1, U101.2 (EN)
/01_POWER_INPUT/BUCK_FB: R105.2, R106.1, U101.5 (FB)
/01_POWER_INPUT/BUCK_SW: C107.2, L101.1, U101.8 (SW)
/01_POWER_INPUT/VIN_FILTERED: C101.1, C102.1, C103.1, C104.1, C105.1, C106.1, D103.1 (K), R101.2, R102.1, U101.3 (VIN)
/01_POWER_INPUT/VIN_FUSED: D101.2 (A2), D102.2 (A), F101.2
/01_POWER_INPUT/VIN_PROTECTED: D102.1 (K), R101.1
/01_POWER_INPUT/VIN_RAW: F101.1, J101.1 (+)
GND: C101.2, C102.2, C103.2, C104.2, C105.2, C106.2, C108.2, C109.2, C110.2, C111.2, C112.2, D101.1 (A1), J101.2 (-), R103.2, R104.2, R106.2, TP103.1 (1_1), U101.1 (GND), U101.9 (EP), U102.4 (GND), U102.5 (GND), U102.6 (GND), U102.9 (EP); also elsewhere on the board
unnamed: C107.1, U101.7 (BOOT)
unnamed: R104.1, U101.4 (RT/SYNC)
PWR_GOOD_VEH: R107.2, U101.6 (PG)

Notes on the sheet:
SCHEMATIC | 9-36 V nominal operating input
LAYOUT INTENT (PCB NOT IMPLEMENTED) Keep C106 + ceramic bank at U101 VIN/GND; smallest hot loop. Minimize SW copper; L101 marked short lead to SW. Sense FB after L101 at output capacitors; away from SW/BOOT. Connect both IC exposed pads to GND copper + thermal vias. Keep a continuous ground plane; 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
100 mA 3V3 design allocation; LDO nominal loss 0.319 W. Do NOT connect a battery directly to +3V3_VEH. Future power mux must block reverse current into U102. PWR_GOOD_VEH is not valid as a battery-only rail monitor.
A. FUSED CLAMP + REVERSE BATTERY + DAMPED INPUT FILTER
Internal compensation, soft start and synchronous rectification. No COMP network / catch diode / external bootstrap diode. 6.49 V supports TCAN4550 VSUP (6 V minimum), with 9 V input headroom. EN typ: ON 6.04 V / OFF 5.31 V at VIN_FILTERED; see corner calculations. UVLO is not a guarantee of valid 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
Scope: only this power sheet. No +5V rail is required by the selected architecture. Design is non-isolated. Never use GND as a substitute for a specified chassis connection. No LED load added; test pads provide bring-up access without continuous drain.
F101 is NOT a precision current limiter. Use a suitably fused vehicle harness. D101 return: short/wide to J101 return; keep surge current away from logic. Bidirectional D101 avoids forward conduction on a reversed battery.
D101: 40 V stand-off; 64.5 V max clamp at 102 A, 10/1000 us, 25 degC. 80 V buck / 100 V input capacitors. Hot clamp + PCB overshoot must be checked.
C. 3.3 V VEHICLE LOGIC SUPPLY
B. 6.49 V SYNCHRONOUS BUCK / 300 mA TOTAL DESIGN BUDGET
01 AUTOMOTIVE POWER INPUT / VEHICLE-SUPPLIED RAILS

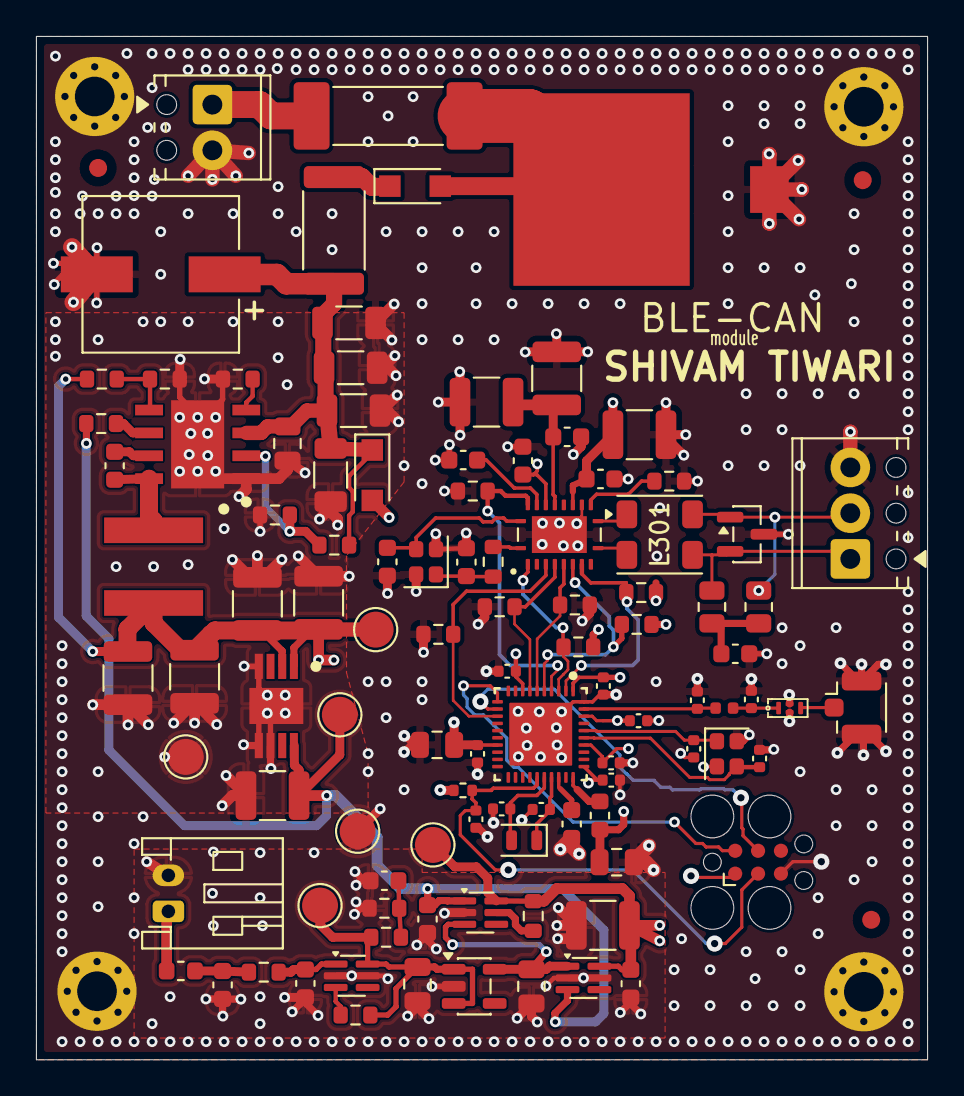
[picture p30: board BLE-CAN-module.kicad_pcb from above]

Board: 4 copper layers, 49.5 x 56.8 mm, 110 parts (0 on the bottom side), 53 nets.

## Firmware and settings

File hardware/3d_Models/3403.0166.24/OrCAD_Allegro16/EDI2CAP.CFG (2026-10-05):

;>------- Configuration parameters: -------<

;>------Check EDIF2CAP.PDF for details ----<



[OrCAD Writer]



SuppressWarnings = 0	

ConvertOnlyLibs = 0

UnitMeasurement = default

PinToPin = 0

Grid = 0

EnableOffgridObjects = 0

GenerateIniFile = 1

OrcadConventions = 1

UseDesignatorsForPackaging = 1

DesignatorsEndOnLetters = 0

DesignatorsSameInHierarchy = 1

GeneratePinNumbers = 0

GeneratePortSymbols = 1

GenerateOffPageConnectors = 0

GenerationVisible = 1

CaptureLibsWithUserPackages = ""

SystemNetNamePrefix = ""

BackgroundTextScale = 0.8

DefaultNetNameScale = 0.3

StandardPageSize = 0

EliminatePageText = 0

SmashTitleBlock = 0

PinDisplayStyle = orcad

TopView = ""

ComponentsMode = 0

ReplacePartWithNoPinsWithTitleBlock = 0

ChangeBusBaseThatEndsOnDigit = 0

ProcessBackAnnotation = 1



[Mapper]

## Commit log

2026-10-05 Initial automotive BLE-CAN hardware project
    [01_POWER_INPUT.kicad_sch, 03_CAN_Interface.kicad_sch, 04_Power_Back-up.kicad_sch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]
2026-10-06 cleanup .gitignore
    Remove ai_logs from .gitignore to track AI logs.
2026-10-12 Add PCB views to README
